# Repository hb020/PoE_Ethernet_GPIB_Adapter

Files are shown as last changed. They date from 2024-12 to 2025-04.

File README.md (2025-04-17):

# PoE Ethernet GPIB Adapter, with Prologix or VXI-11.2

## PoE-powered GPIB Adapter with Ethernet and USB-C Support

<a href="Img/adapter_connected.png" target="_blank">
    Adapter Assembled
</a>

The **PoE Ethernet GPIB Adapter** is designed to interface test equipment with GPIB / HPIB / IEEE-488 interfaces.

The primary goal of this project is to provide an easy solution to connect multiple GPIB-equipped instruments over Ethernet without excessive cabling. It can, at choice, use the Prologix protocol or support VXI-11.2 (VISA).

---

## Why?

The motivation behind this project comes from the challenges of using several generations of instruments with GPIB interfaces. In theory, only one GPIB master is needed, and up to 20+ instruments can be connected in any order using suitable GPIB cabling. However, there are drawbacks:

- Instruments must be fully compliant with the IEEE-488 standard. Many older instruments, predating the standard, do not comply. The main issue is that the bus does not go Hi-Z when off, requiring certain instruments to be powered on even if you're only using another device.
- GPIB cabling is bulky and expensive. While used options can sometimes be found, the overall cost remains high.

At work, this has been solved elegantly using commercial Ethernet adapters, each assigned an address and connected directly to the instrument. However, these adapters are priced around $500 USD—far from hobbyist-friendly. My initial solution was to buy one adapter and rely on daisy-chaining, but as my instrument collection grew to 20 devices requiring GPIB, this approach was no longer practical. Hence, the **PoE Ethernet GPIB Adapter** was born.

---

## Design Criteria

1. Lower cost: Total BOM should be less than 50 USD.
2. Support Power over Ethernet (PoE) to minimize cable clutter.
3. Include USB-C power as an alternative if PoE is unavailable.
4. Enable GPIB communication over both Ethernet and USB-C interfaces.
5. Use the same communication protocol as existing commercial units.
6. Minimize radiated and conducted noise to avoid interference in test environments.
7. Include a simple, easy-to-print 3D-printed enclosure to keep costs low.

---

## Results

All design goals have been met[^2]. The current unit price is approximately $45 USD when ordering parts for 20 units. Prices increase for smaller batch sizes.

[^2]: GPIB commands over USB-C is Work In Progress.

In my home lab, I assign each device a static IP address based on its MAC address and run a local DNS server to provide easy-to-remember domain names, making the adapter simple and intuitive to use.

Project's documentation:

- [Design Documentation](docs/dn.md)
- [Design Test Documentation](docs/dt.md)

---

## VXI-11 or Prologix

This code can produce either a VXI-11.2 device, or a Prologix device (the ROM is not big enough for both at the same time, although the code is compatible with cohabitation). Switching between VXI-11 and Prologix is done at compile time. If compiler option `-DINTERFACE_PROLOGIX` is used, the firmware produced is for Prologix.

VXI-11.2 allows discovery over the network, and uses the following VISA connection strings:

- Controller[^1]: `TCPIP::{IP address}::INSTR` (unless you have set the default instrument address to something else than 0)
- Instruments: `TCPIP::{IP address}::gpib,N::INSTR` or `TCPIP::{IP address}::instN::INSTR`, where `N` is their address on the GPIB bus (1..30)

Example: `TCPIP::192.168.7.105::gpib,2::INSTR` for instrument with GPIB address 2 on the gateway having IP address 192.168.7.105.

[^1]: controller, gateway, adapter: different names for the same.

### VXI-11.2 compatibility

With the limited resources, this device is meant to work with the most common tools, like for example pyVisa. It is not a full implementation, and lacks the following advanced features:

- secondary instrument addresses
- async VXI-11 operations
- instrument locking via VXI-11
- VXI-11 interrupts
- the VXI-11 abort channel

It is discoverable via UDP, but there is no publication via mDNS (yet).

---

## The number of instruments you can connect

The GPIB bus protocol itself allows up to 30 instruments. This does not mean you can connect 30 instruments to the gateway, as the gateway device has its electrical limits, depending on the length of the cables and instruments themselves. And also the software has its limits.

The Prologix service will accept as many instruments as the gateway hardware can drive reliably.

The VXI-11 service is easier to integrate with many tools, but it consumes more resources on the gateway. The Ethernet chip can only maintain a limited number of network sockets, and each instrument requires a separate socket with VXI-11. Prologix uses only 1 socket, no matter the number of instruments. This means that regardless of the limitations of the hardware, there is a limit to the number of instruments you can connect to via VXI-11 compatible client software:

- up to 4 instruments: no restriction
- 5 instruments: only if you do not use the web server
- 6 instruments: only if you disable the web server (use the compile option `-DDISABLE_WEB_SERVER`)
- 7 or more: not possible via VXI-11

This does not mean that you cannot physically connect more instruments to the gateway, it just means that you cannot connect to more of them, via your client software, at the same time.

Also, be aware that the GPIB bus is a shared bus. Do not try to control instruments on the bus from different software clients at the same time. VXI-11 is somewhat more forgiving in this matter, but the prologix service simply doesn't allow multiple connections.

---

## The User Interface of the device

There are 3 parts:

- the **LED**. It indicates different states: blue for waiting for DHCP, red for error in network or DHCP, green flashing for idle, green/blue flashing for busy
- the **Web Server** (on port 80): it shows some help texts and the number of connected clients. It is not interactive.
- the **serial console** (via USB): This console shows startup information, ports used, and has a small menu. 

### The serial menu

This menu is rather basic. Be aware that it requires 'enter' for each command.

It has the following options:

- Setting of IP address. By default, the device starts with DHCP. You can however force a fixed IP address.
- Setting of the default instrument address (only with VXI-11, as Prologix has its own command for that). The default is 0, meaning: the gateway itself. If you only have 1 instrument connected, or want to designate a "preferred" instrument, you can set it to the address of any instrument on the bus. That way, the gateway becomes transparent, and you can use the default (and the discoverable) VISA connection string to address that instrument.

---

## Project files

Latest version is avaiable under [Releases](https://github.com/Kofen/PoE_Ethernet_GPIB_Adapter/releases)

And all the source code for all the parts should be in their respective folders in the repro. If anything is missing, let me know!

## How to compile

The easiest is for compilation with PlatformIO, from the [SW](/SW) directory.

## License

This project is licensed under the GPL V3. See the [LICENSE](LICENSE) file for details.

## Acknowledgements

- A huge thanks to the [AR488 project](https://github.com/Twilight-Logic/AR488), run by [Twilight-Logic](https://github.com/Twilight-Logic) and its community contributors. The current software is a fork of AR488. For more information about this, see [here](SW/README.md).
- The VXI-11 driver is partially inherited from [espBode](https://github.com/awakephd/espBode), and went through various evolutions before arriving here.

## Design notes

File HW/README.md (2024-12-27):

# PoE Ethernet GPIB Adapter - Hardware Files

## Overview

This folder contains the necessary hardware files for the PoE Ethernet GPIB Adapter project.

- **Schematics:** The schematic files can be found [here](https://github.com/Kofen/PoE_Ethernet_GPIB_Adapter/blob/main/HW/Schematic_PDF/PoE_Ethernet_GPIB_Adapter.pdf).
- **Output Files:** The output files, including Gerber files and assembly information, are located [here](https://github.com/Kofen/PoE_Ethernet_GPIB_Adapter/tree/main/HW/PoE_Ethernet_GPIB_Adapter_PCBA_MFG_Files).
- **Releases:** Precompiled hardware files for different versions are available under [Releases](https://github.com/Kofen/PoE_Ethernet_GPIB_Adapter/releases).

**Important note:** PCB thickness should be 1.6mm, 1 oz / 35 um copper thickness on all layers!

---

Ensure to verify compatibility with your PCB manufacturing service before using the files.

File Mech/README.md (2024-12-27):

# PoE Ethernet GPIB Adapter

In the Freecad folder you will find the project files and an output folder with STL files. 

To make the case and assemble: 

- 2 x M3 x 10mm T10 Torx Countersunk Screws (ISO 14581) 
- 12 Meter (40 gram) of 3d filament of your choice. 
- Optional: 2x M3.5 x 70mm Countersunk Screws to fasten the adapter to the instrument. 

***NOTE*** If you want to use screws to fasten the adapter to the instrument, you need to drill out the holes in the centronic connector.

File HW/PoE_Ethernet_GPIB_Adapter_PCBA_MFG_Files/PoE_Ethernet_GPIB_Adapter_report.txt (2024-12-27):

PCB statistics report
=====================
- Date: Friday, December 27, 2024 at 07:41:28 AM
- Project: PoE_Ethernet_GPIB_Adapter
- Board name: PoE_Ethernet_GPIB_Adapter

Board
-----
- Width: 60.0000 mm
- Height: 55.0000 mm
- Area: 3300.0000 mm²

Pads
----
- Through hole: 60
- SMD: 557
- Connector: 0
- NPTH: 4

Vias
----
- Through vias: 741
- Blind/buried: 0
- Micro vias: 0

Components
----------

| | Front Side | Back Side | Total |
|---|---|---|---|
|THT: | 4 | 0 | 4 |
|SMD: | 135 | 28 | 163 |
|Unspecified:  | 30 | 1 | 31 |
|Total: | 169 | 29 | 198 |

Drill holes
-----------

| Count | Shape | X Size | Y Size | Plated | Via/Pad | Start Layer | Stop Layer |
|---|---|---|---|---|---|---|---|
| 741 | Round | 0.3000 mm | 0.3000 mm | PTH | Via | F.Cu | B.Cu |
| 26 | Round | 1.0000 mm | 1.0000 mm | PTH | Pad | F.Cu | B.Cu |
| 10 | Round | 0.6500 mm | 0.6500 mm | PTH | Pad | F.Cu | B.Cu |
| 10 | Round | 0.8900 mm | 0.8900 mm | PTH | Pad | F.Cu | B.Cu |
| 4 | Round | 1.0200 mm | 1.0200 mm | PTH | Pad | F.Cu | B.Cu |
| 2 | Round | 0.6500 mm | 0.6500 mm | NPTH | Pad | F.Cu | B.Cu |
| 2 |  Slot | 0.6000 mm | 1.7000 mm | PTH | Pad | F.Cu | B.Cu |
| 2 |  Slot | 0.6000 mm | 1.4000 mm | PTH | Pad | F.Cu | B.Cu |
| 2 | Round | 3.2000 mm | 3.2000 mm | NPTH | Pad | F.Cu | B.Cu |
| 2 | Round | 1.7000 mm | 1.7000 mm | PTH | Pad | F.Cu | B.Cu |
| 2 | Round | 1.3000 mm | 1.3000 mm | PTH | Pad | F.Cu | B.Cu |
| 2 | Round | 3.0000 mm | 3.0000 mm | PTH | Pad | F.Cu | B.Cu |

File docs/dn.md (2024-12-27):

# PoE Ethernet GPIB Adapter

## Design Notes

<a href="../Img/adapter_open.png" target="_blank">
    Adapter Assembled
</a>

---

## Hardware

While there are a few open-source GPIB controller projects, most of them rely on USB, Raspberry Pi, or WiFi/Bluetooth connectivity. These solutions do not meet my requirements. Using over 10 adapters with USB would result in a serial port management nightmare and require a service running on a local computer to forward all ports over the network for access from any computer. 

WiFi could resolve this but would introduce multiple devices in close proximity to sensitive test setups, which I find suboptimal. One PoE-powered GPIB project based on the RP2040 was mentioned on the EEVblog forum but was never published and seemed to have stalled. Therefore, I designed my own adapter while ensuring compatibility with one of the largest open-source adapters, the AR488.

Based on these requirements, the design was divided into the following components:

- PoE Power Supply
- Microcontroller Interface
- Network Interface
- GPIB Interface
- USB Interface

---

### PoE Power Supply

Several PoE modules provide 5V output, simplifying integration. However, achieving low noise and a small form factor made off-the-shelf solutions challenging without extensive pre-testing for EMI compliance. To address this, I divided the power supply into two parts: a PoE controller and a standalone isolated power supply.

- **PoE Controller:** I selected the Texas Instruments TPS2375-1 for its small size, affordability, built-in inrush limit, integrated MOSFET, and 802.3af compliance. The device was configured for Class 0 classification with standard input capacitance and transient protection.
- **Isolated 5V Power Supply:** The Texas Instruments LM5180 flyback controller was chosen for its integrated switch and primary-side regulation, offering a simple implementation. Although flyback converters are not ideal for low EMI, space constraints left no alternative without significantly increasing complexity. To minimize EMI:
  - A powerful common-mode filter was added on the input side.
  - Planar magnetics were used to reduce current loop size.
  - A cancellation winding was added to the transformer to mitigate common-mode voltage issues.
  - A strong chassis connection to the GPIB connector ensured a low-impedance return path for common-mode voltage.

---

### Microcontroller Interface

The Microchip ATMEGA4809 was chosen for its affordability and familiarity. While a more powerful 32-bit processor could have been considered, simplicity and the 8-bit architecture's alignment with the GPIB bus made this an appealing choice.

- **Unique MAC Address:** A Microchip I2C Unique ID EEPROM was included to provide a globally unique MAC address for the Ethernet interface. It can also store user-configurable settings.
- **Additional Features:** An RGB LED and reset switch were added for status indication and recovery in case of GPIB bus or adapter failure. 
- **Expansion:** A standard UPDI pinout for Atmel ICE programmers was implemented. Optional resistors connect I2C and UART2 to unused pins for potential future use with sensors or a WiFi UART interface (default resistors are not mounted).

---

### Network Interface

The Wiznet W5500 was selected as the network controller for its available drivers and compatibility with the AR488 project. To simplify the design:
- A magnetics RJ-45 magjack was used.
- Series termination was added to all applicable I/O lines for proper signal integrity and EMI reduction.
- A Texas Instruments SN74LV1T125DCK tri-state buffer was used for level translation (5V ↔ 3.3V ↔ 5V).
- A simple LDO provided the 3.3V supply, with a watchdog on the reset line.
- The crystal was selected per the datasheet to ensure Ethernet timing compliance.

---

### GPIB Interface

The GPIB interface directly connects to the microcontroller without driver ICs, using a resistor network on each I/O line and ESD protection to ground. This design:
- Does not handle constant overvoltage but protects against most ESD events.
- Requires the device to be powered on to avoid loading the GPIB bus, deviating slightly from full IEEE-488 compliance. This compromise reduces cost and space while meeting the 99% use case of the adapter being the controller.

---

### USB Interface

USB-to-UART controllers from reputable distributors proved expensive. Instead, I selected the CH340X USB-UART controller for its affordability and proven reliability in DIY and commercial projects. Notable features:
- A USB-C connector was used and configured for 500mA power.
- Protection includes a PTC fuse, ferrite bead, transient diode, and ESD filters on the data pins.
- The only drawback is sourcing the CH340X from Asian vendors, but reputable distributors like LCSC ensure reliability.

---

## Software

The current software is a work-in-progress, simplified fork of the AR488 project. This fork was chosen because it uses the Prologix syntax, compatible with my existing scripts. I also appreciate Prologix's simplicity: the Ethernet adapter operates as a basic socket. Commands without a `++` prefix are sent directly to the bus, while configuration is handled with `++` commands (e.g., `++addr` queries the address, and `++addr 22` sets the interface address to 22).

Initially, I intended to fully integrate the network stack and console interface into the AR488 project. However, given the project's complexity and my inability to test all functionalities, I opted to streamline this fork exclusively for this adapter. In the future, I plan to move away from Arduino to enhance performance.

Currently, the software includes a barebones implementation of the network stack and I2C support, with only DHCP enabled. Switching to USB-C UART instead of Ethernet requires modifying the configuration file and recompiling. Updates are planned to address these limitations.

Despite its barebones, hacky approach, the code has proven extremely reliable, running for months without issues. All my Prologix-based scripts work seamlessly.

Many software updates are expected in the future. Contributions to the software are highly welcome!

---

## Mechanics

A simple split housing was designed in FreeCAD for 3D printing. The snap-action case simplifies assembly and includes holes for securing the PCB and connector to the bottom half. There are also two holes on the back of the case for optional M3.5 screws to secure the adapter to the instrument.

The case design fitment heavily depends on the 3D printer and filament. I printed the cases on a Prusa MK3.5 using Bambu Labs PLA-CF filament, which provides a superb finish.

---

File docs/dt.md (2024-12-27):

# PoE Ethernet GPIB Adapter

## Design Tests

<a href="../Img/adapter_open.png" target="_blank">
    Adapter Assembled
</a>

---

## Scope of Testing

Each of the main blocks of the adapter was fully design-tested. The prototype (shown in the header image) was built in stages to make testing each module manageable as it was brought up.

The adapter was built and tested in this order:

- PoE Power Supply
- Microcontroller Interface
- USB Interface
- Network Interface
- GPIB Interface

**A note on details:** There are screenshots and CSV files of many measurements in this repository, but I decided against adding them to this document as they are not that interesting unless you are testing the design yourself. They're there for those who might care, in the `DT/Figs` folder. Naming should make sense for anyone familiar with the tests.

---

## Electrical Testing

### PoE Transformer

I started with a bare PCB to characterize the transformer using an HP4395A impedance analyzer in shunt-thru mode.

**Test Setup:**  
<a href="../Img/trafo_dt.png" target="_blank">
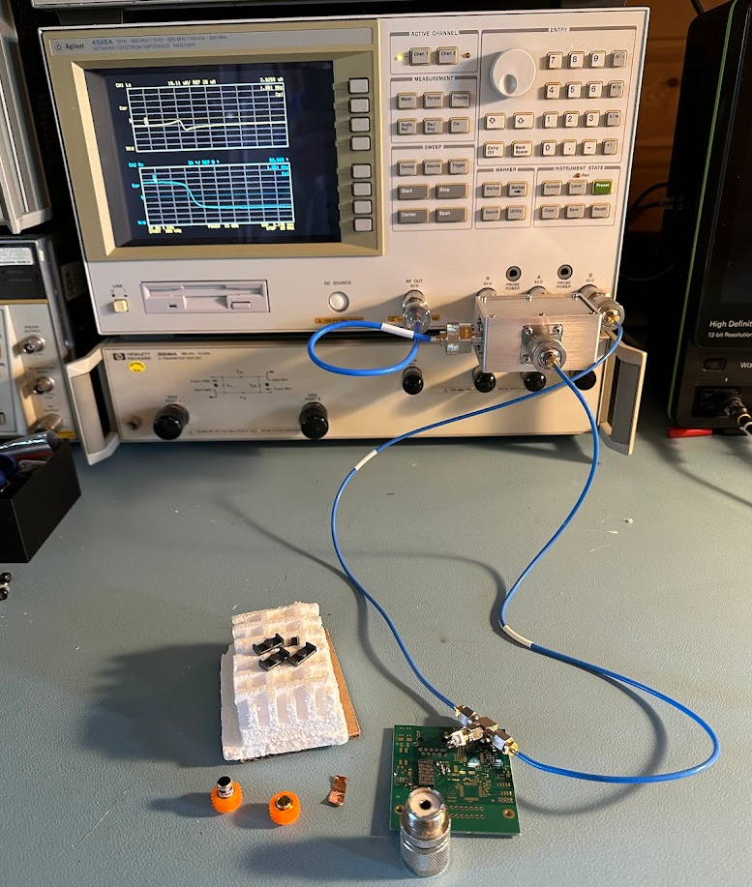
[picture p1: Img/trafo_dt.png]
Transformer Test Setup
    
</a>

Measurements were taken for primary/secondary inductance, leakage inductance, and interwinding capacitance. Everything was calibrated, and fixture parasitics were compensated.

Two tests were run with cores providing 50nH and 100nH Al values. Eventually, the 50nH core combination was chosen (reasons detailed later). Results for this configuration:

- Interwinding capacitance: **100 pF**
- Primary inductance: **18.2 µH**
- Secondary inductance: **2.29 µH**
- Primary leakage inductance: **395 nH**

These numbers lined up well with expectations.

### PoE Flyback 5V Power Supply

With the flyback controller populated, I connected it to a lab power supply with current limiting. It came to life at around 36.5V input, outputting 5.4V, which stabilized to 5.01–4.9V depending on the load.

**Test Setup:**  
<a href="../Img/test_poe.png" target="_blank">
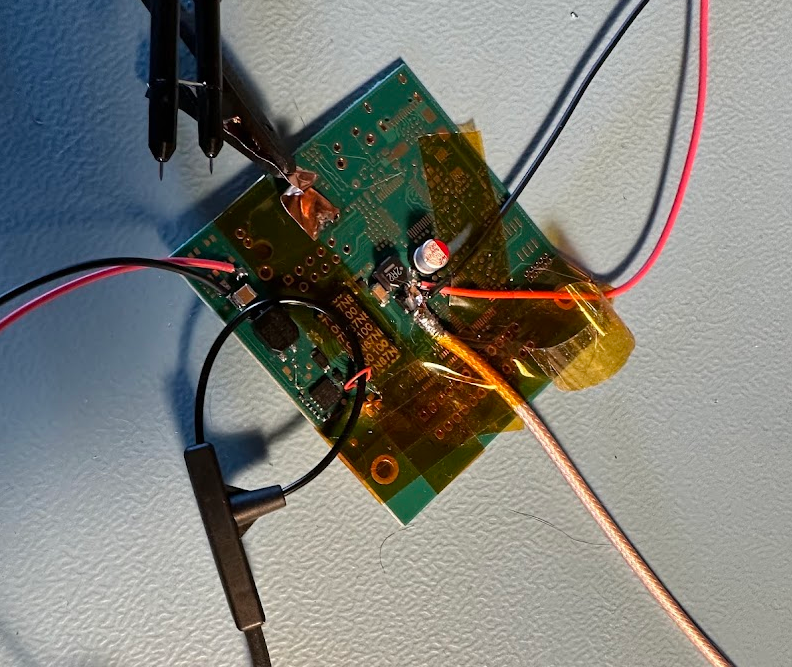
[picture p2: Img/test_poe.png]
Power Test Setup
    
</a>

**Troubleshooting and Adjustments:**  
Things went sideways at 48V, with instability in the power supply. The issue was traced to an undersized air gap in the transformer core. I took a calculated risk here, knowing the available cores and space constraints. To fix this, I replaced both of the core halfs with a gapped one, reducing the Al value to 50nH. This brought the primary inductance to ~15 µH. Not ideal, as it increased magnetizing current and reduced efficiency, but it was the best trade-off given the circumstances.

- Switching node voltage was clean, with the zener snubber doing its job well. No RC snubber was needed.
- High-frequency ringing across the rectifier diode required a 330pF + 33Ω snubber, which worked effectively.

**Efficiency Plot (Clickable):**  
<a href="../Img/eff.png" target="_blank">
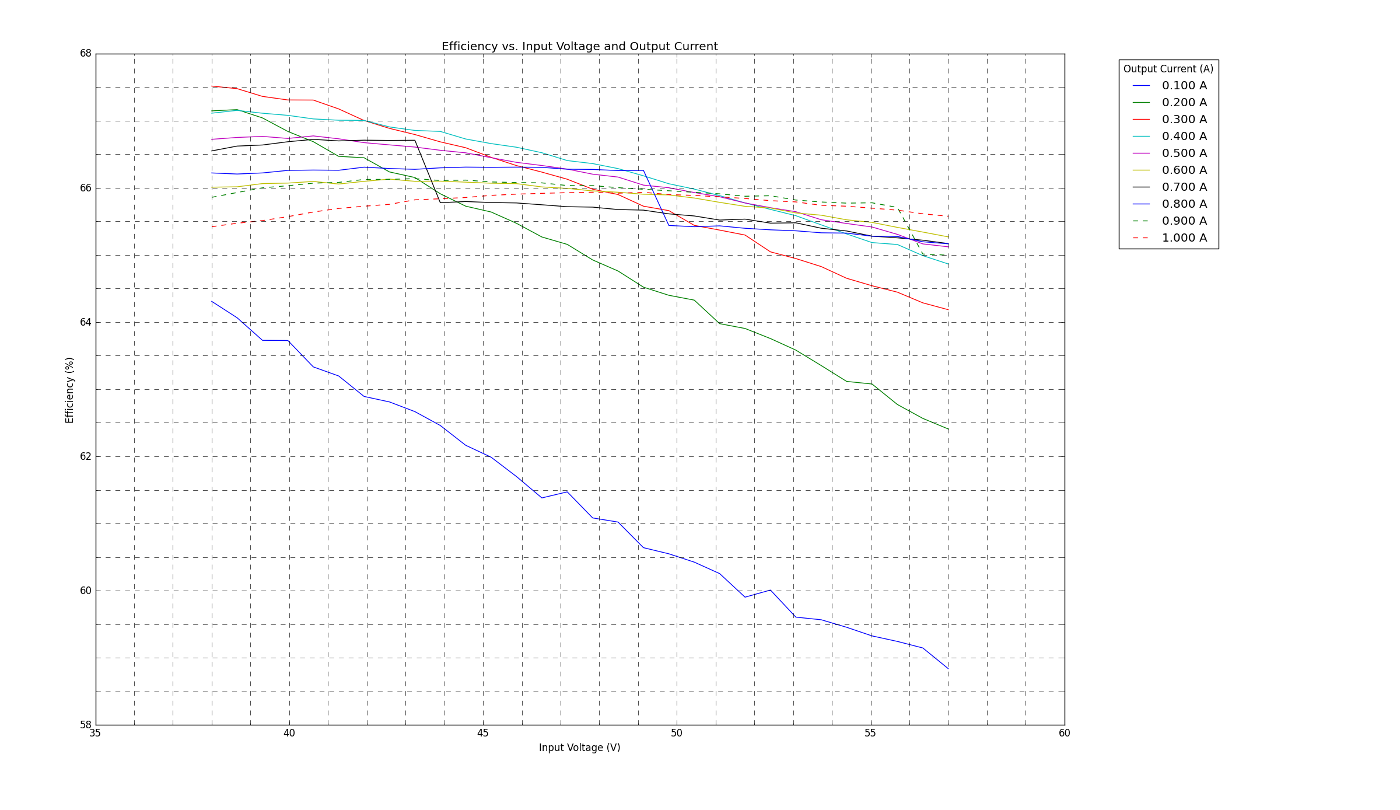
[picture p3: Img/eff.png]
Power Efficiency
    
</a>

As expected, efficiency isn't great. Lower loads and higher input voltages exacerbate losses due to increased magnetizing current and switching losses. However, thermals remain under control, with no concerning hotspots under typical operating conditions. It was decided to leave the core as is until full system tests are done.

Next, stability testing was done. Since the secondary voltage is regulated by the primary side, we do not have a normal feedback network. 
To test stability, two tests were done: step response and output impedance measurement. 

First, step response was done.

**Step Response Plot (Clickable):**  
<a href="../Img/Step_response_0p5A.png" target="_blank">
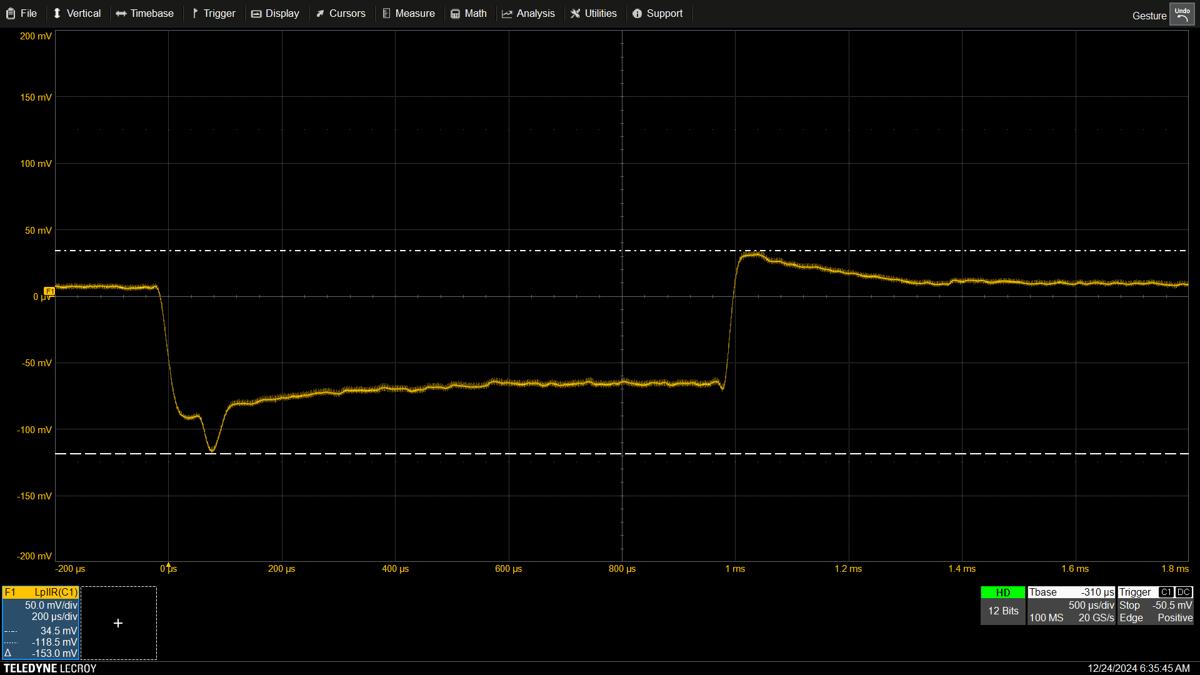
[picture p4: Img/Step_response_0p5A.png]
Step Response
    
</a>

The load was stepped from 0.1 A to 0.5 A. The result is a clean, fast step response with minimal ringing. The output voltage does drop slightly with increased load; this is due to the extra diode drop, not accounted for by the controller due to the regulating mechanism. 

Output ripple was measured to 15 mV peak to peak. Created mostly by the rest of the circuitry connected to the power supply.

As a final test, the output impedance was measured with all the parts placed on the PCB, with the adapter powered off and on. 

**5V PSU Impedance Plot (Clickable):**  
<a href="../Img/PSU_Impedance.png" target="_blank">
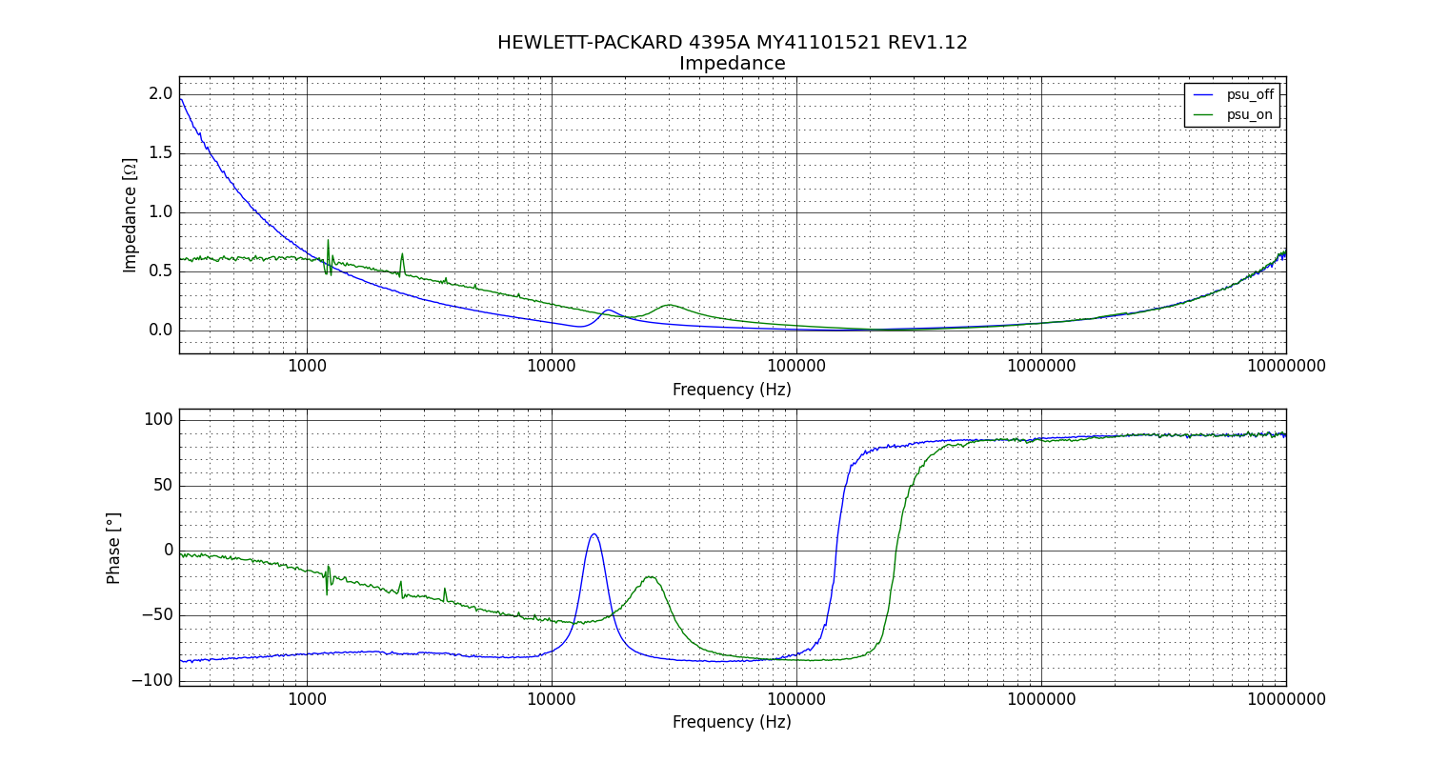
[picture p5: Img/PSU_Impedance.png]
PSU Impedance
    
</a>

With the power supply off, we see a resonance formed by the output LC filter, then we turn inductive around 150 kHz. 
With the power supply turned on, those points shift, and the Q of the LC resonance is lowered due to the parallel output impedance of the power supply. 
We also lower the general output impedance and see no added peaks or resonances from the power supply itself. 

The peak from the LC filter harmonizes well with the damped half-cycle ringing observed in the step response. 

Since we have no way to inject a test signal and do not see any form of resonance created by the switching controller on the impedance plot, we have no way of estimating the phase margin, but we can safely assume it is high due to the lack of any formed resonance. 
It is concluded that the power supply is sufficiently stable. 

### Microcontroller Interface

The microcontroller and its support circuitry were populated. Programming over JTAG worked perfectly, and all LEDs blinked as expected. No issues arose.

### USB Interface

With the CH340X USB interface populated, the adapter was recognized by my computer, and the serial console worked flawlessly. The reset line behaved correctly for USB programming. Measurements revealed no ringing or anomalies on the I/O lines.

### Network Interface

The Wiznet W5500's 3.3V power supply measured 4.2V due to an ordering mistake: the AZ1117-3.3 LDO I received had a different pinout. After replacing it, the supply output 3.303V, as expected.

Once the correct LDO was in place, the W5500 connected to the network, obtained an IP address, and passed signal integrity checks.

### GPIB Interface

The final test involved connecting the adapter to a GPIB-equipped instrument and querying `*IDN?`. It returned the expected instrument ID. The adapter handled multiple instruments and longer GPIB chains without issues, with signal levels and integrity well within acceptable ranges. I set up an automated test to stress the GPIB handling by sending a lot of data back and forth between numerous instruments without any issues. 

---

## EMC Compliance Testing

**Disclaimer:** This was done at home with DIY equipment. While I've characterized all my gear and even compared some of my equipment with professional gear, these results shouldn't be treated as commercial-grade compliance tests. The goal here was to ensure the adapter wasn't creating an EMI disaster in my own lab.

### Conducted Emissions

**Test Setup:**  
<a href="../Img/emc_cond.jpg" target="_blank">
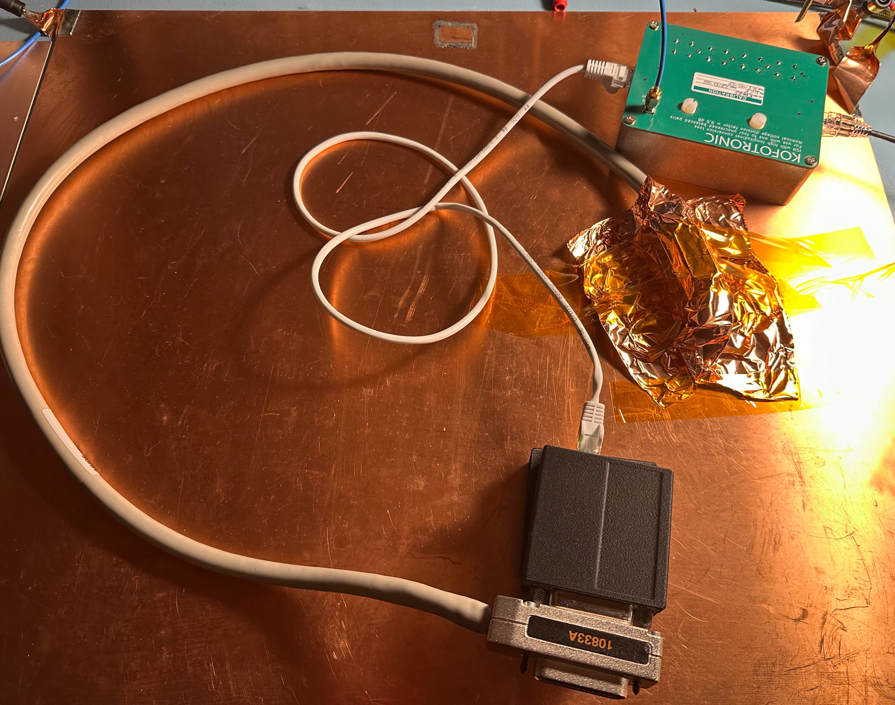
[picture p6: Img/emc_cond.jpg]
EMC Conducted Setup
    
</a>

This worst-case setup involved elevating the DUT 2.5 cm, using a cheap 1 Meter unshielded Ethernet cable, and grounding the GPIB connector via an additional GPIB cable.

**Results (Clickable):**  
<a href="../Img/Conducted.png" target="_blank">
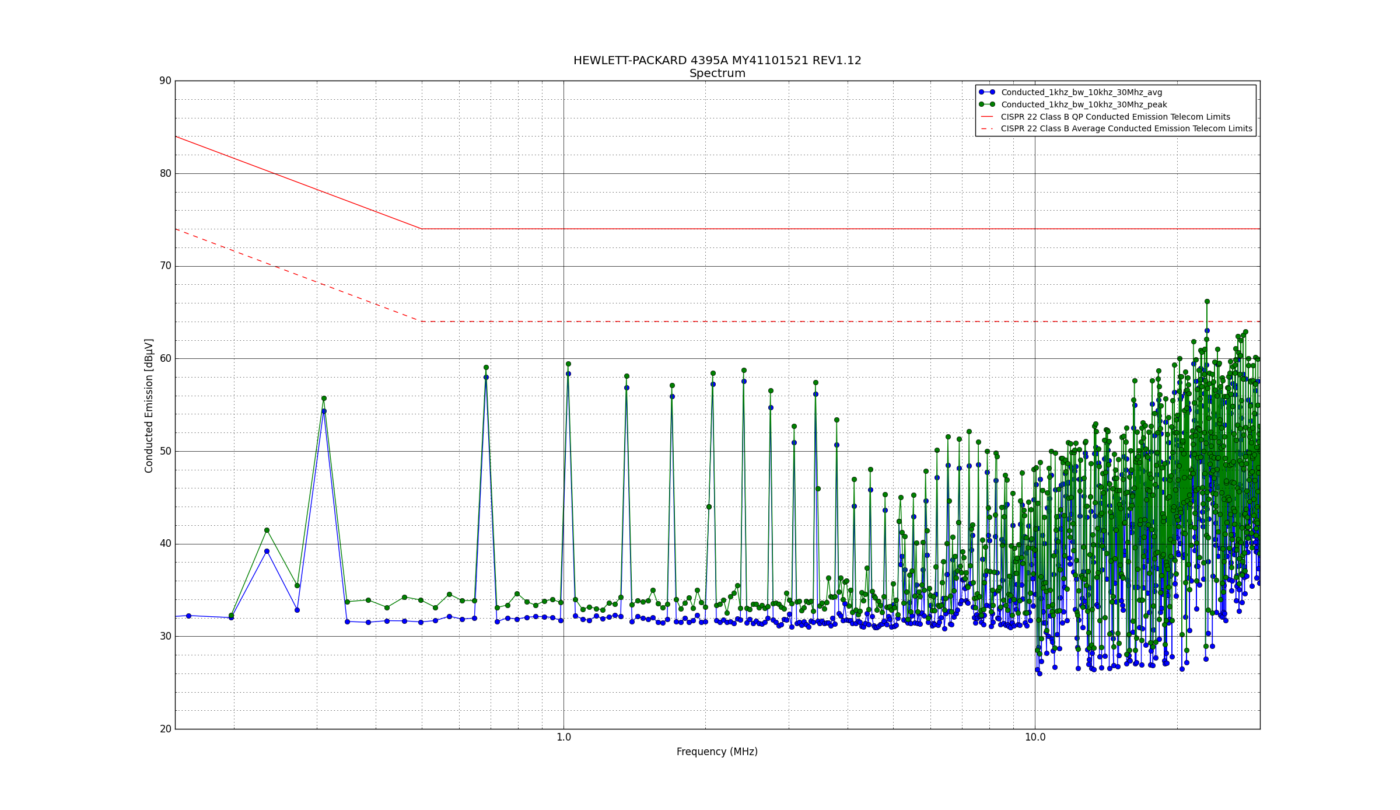
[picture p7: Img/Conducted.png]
Conducted Emissions
    
</a>

The adapter met CISPR-22 Class B limits. Margins were tight at higher frequencies, but no further tweaks were deemed necessary.

### Radiated Emissions

**Test Setup:**  
<a href="../Img/tem.png" target="_blank">
    EMC Radiated Setup
</a>

A small TEM cell was used instead of a proper far-field setup, so take these results with a grain of salt.
I have calculated the equivalent 3-meter far field, but I am still unsure how well it translates. Uncorrected as well as corrected data is therefore shown below.

**Uncorrected Results (Clickable):**  
<a href="../Img/Radiated_emissions_peak.png" target="_blank">
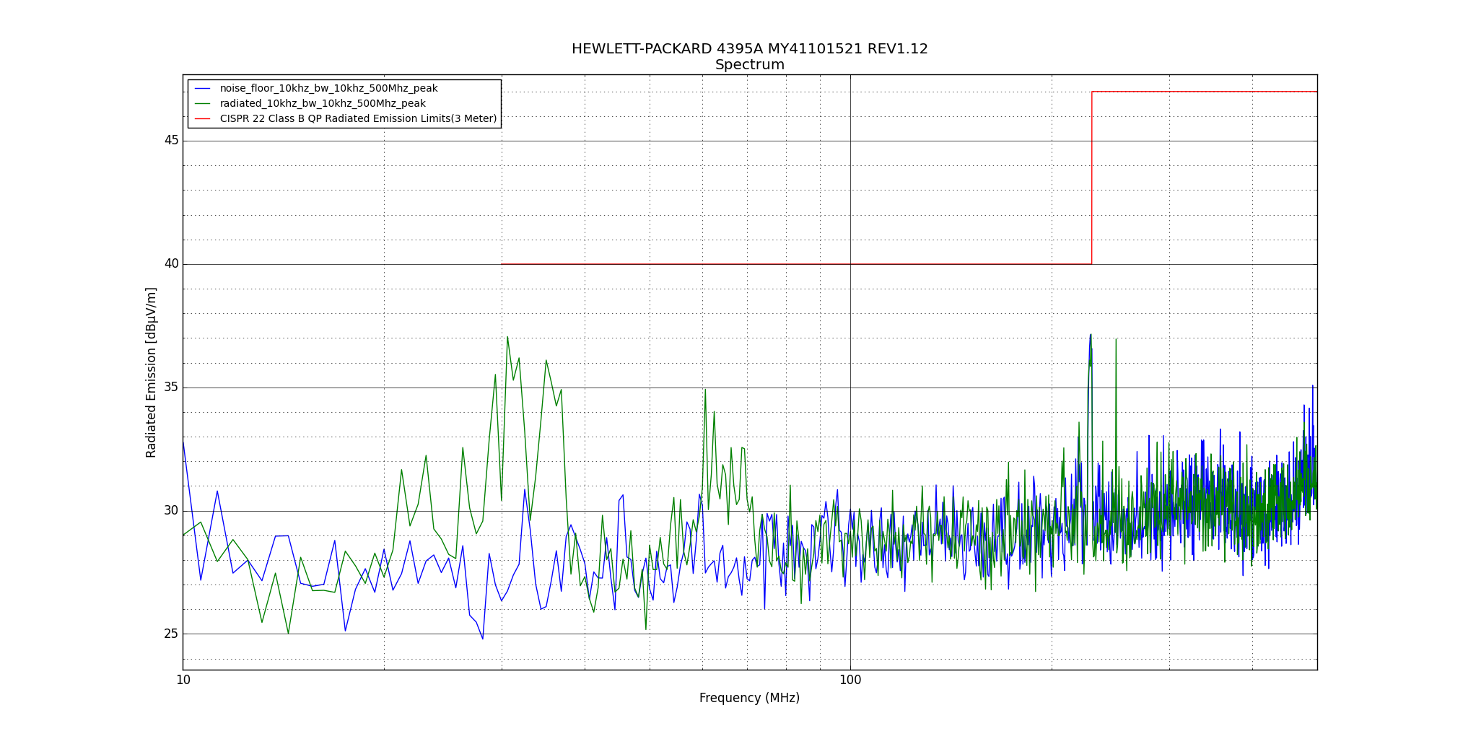
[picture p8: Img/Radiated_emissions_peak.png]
Radiated Emissions
    
</a>

**Corrected Results (Clickable):**  
<a href="../Img/Radiated_emissions_peak_corrected.png" target="_blank">
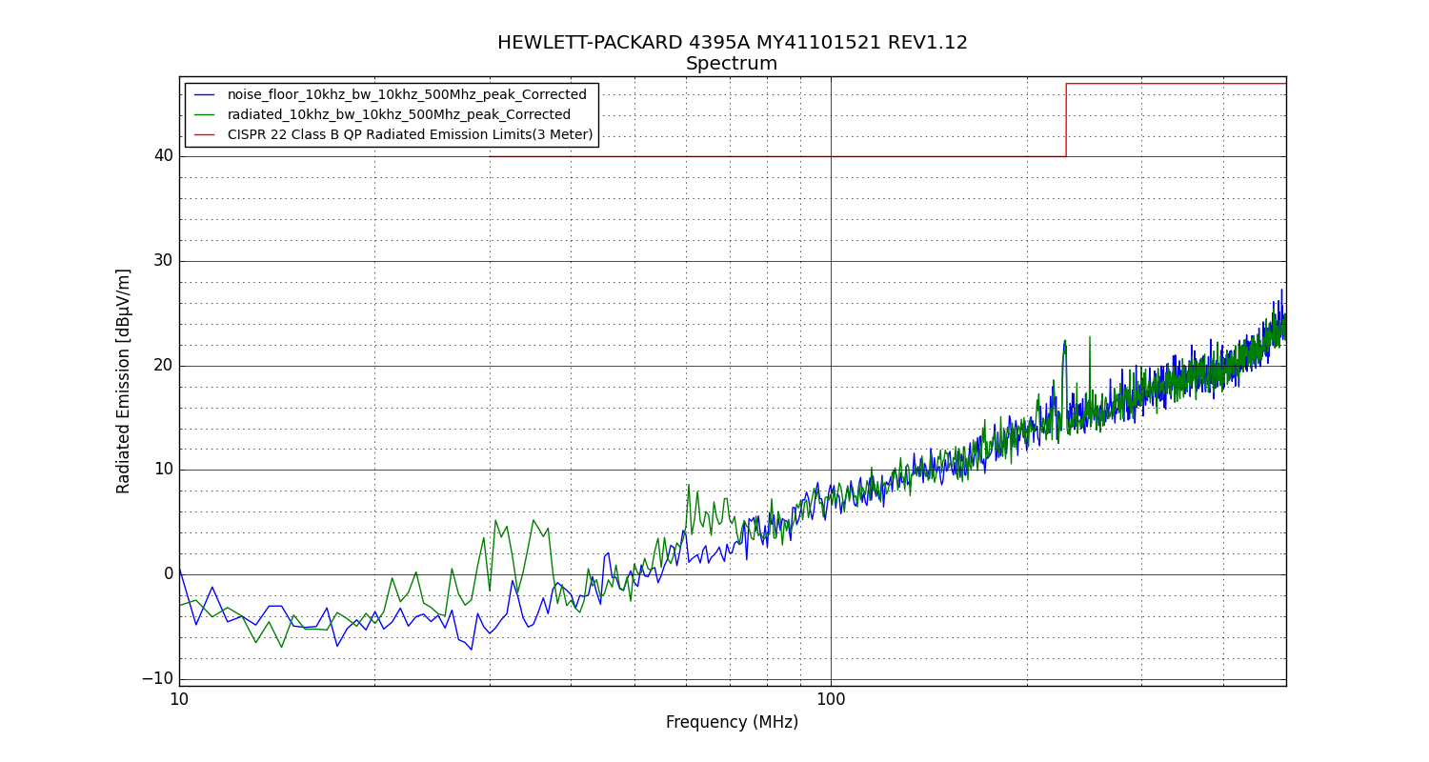
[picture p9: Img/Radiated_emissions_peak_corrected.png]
Corrected Radiated Emissions
    
</a>

The adapter showed minimal issues. Peaks around 250 MHz likely originate from the network interface.

---

## Thermal Testing

Thermal tests showed the adapter's housing raised internal temperatures by ~10°C. With the case opened, thermal imaging identified the 3.3V LDO and Ethernet interface as the hottest points (~23°C above ambient).

**Thermal Plot (Clickable):**  
<a href="../Img/Thermals.png" target="_blank">
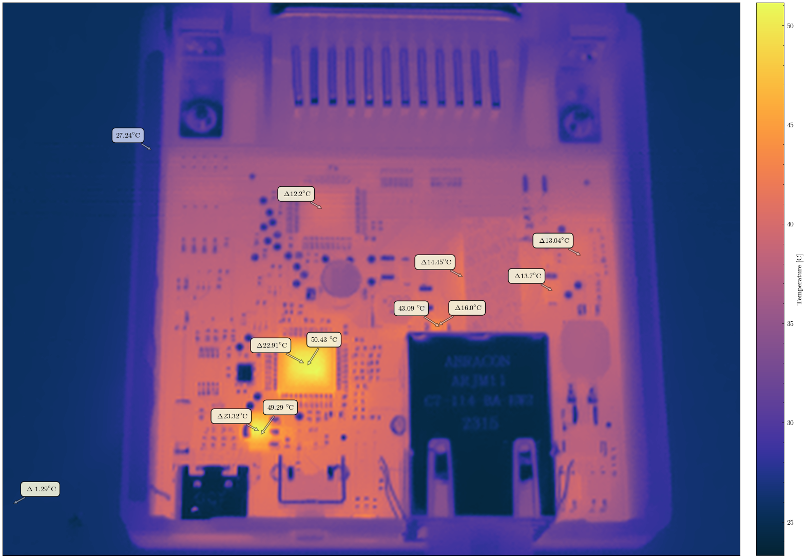
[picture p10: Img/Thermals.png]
Thermal Analysis
    
</a>

This suggests the adapter is safe for ambient temperatures up to ~50°C.

---

## Total power consumption

The total power consumption at 52v in was measured to 1.3 Watt. This is with network interface active, but GPIB bus idle.

## Conclusion

The device meets design goals despite a few compromises:

- The transformer core was adjusted to avoid re-sourcing or grinding cores.
- The LDO issue was fixed with a correct part replacement.

For the release version, I added optional I2C and UART2 connections to the JTAG header and improved copper pours around the Ethernet controller and LDO.

These changes aren't critical but should make future revisions easier.

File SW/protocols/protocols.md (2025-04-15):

# prologix vs RAW vs VXI-11.2 vs hislip

## Needs in number of network connections

..provided we need compatibility with 1 pyvisa program only.

Suppose N is the number of instruments to be represented:

* prologix: 1: TCP server
* RAW: N or N+1 (if you also want the instrument server): all TCP servers in 'auto' mode
* VXI-11.2: N+2 or N+3 (if you also want the instrument server): 1 UDP portmapper, 1 TCP portmapper and the rest RPC servers in non-'auto' mode.
* hislip: not investigated, requires a LOT

## prologix

not (yet) suppored by pyvisa

## RAW

Example of connection string:

TCPIP::192.168.1.105::[port number]::SOCKET

Requires 1 server, and 1 client socket per instrument. Multiple commands tend to be sent concatenated in 1 network packet, unless a question is sent.

## VXI-11.2

Example of connection string:

* TCPIP::192.168.1.105::gpib,5::INSTR   (gpib or hpib or gpibN or hpibN): VXI-11.2
* TCPIP::192.168.1.105::inst::INSTR     (instN): 'normal' vxi-11

gpib0 or inst0: default or only, hpibN or instN: others

Requires 3 servers, and 1 client socket per instrument:

* port mappers on UDP and TCP that point to the VXI-11 RPC server
* the VXI-11 RPC server. VXI-11 consists of 3 separate RPC programs with the numeric identifiers: 0x0607AF (DEVICE_CORE), 0x0607B0 (DEVICE_ASYNC) and 0x0607B1 (DEVICE_INTR).
* you may also add mDNS

For compatibility with basic pyvisa use, you only need DEVICE_CORE, but the guidelines say you should also support the others.

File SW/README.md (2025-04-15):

# PoE Ethernet GPIB Adapter Software

## Programming

In order to program the adapter you first need to flash the Optiboot bootloader via Jtag with an UPDI programmer(Atmel ICE, serial updi or similar).
After this is done, it can be programmed through the usb-c interface.

# AR488, what has changed and how to integrate a new version of AR488

The GPIB part of this program is "forked" from https://github.com/Twilight-Logic/AR488, from ver. 0.53.03, 08/04/2025. It was enhanced with ethernet support, VXI-11.2 and a couple of User Interface options.

Since a proper fork was not possible seen the amount of changes and the specifics of the hardware, this file documents how the integration of the AR488 code was performed. Hoping it will help future code updates.

The original README from AR488 is here: [README_AR488](README_AR488.md), as is the [original AR488 manual](AR488-manual.pdf). Only the part regarding the Prologix protocol would be of interest here.

The files starting with `AR488` were copied to `\SW\src` and modified:

## AR488.ino

This is/was the 'main' file. It received most changes:

* changed the setup section, as the structure was not compatible with cohabitation with other socket servers
* was lacking forward declarations, making it incompatible with 'standard' compilers.

The file was renamed to 'prologix_server.cpp'. The code sections that were modified, are marked as such, with explanation of what was changed.

## AR488_ComPorts.cpp and AR488_ComPorts.h

* DEVNULL externalised to become a dependency
* Added include to `EthernetStream.h`
* `startDataPort()` version added that points to a `EthernetStream`.
* `int maintainDataPort()` added
* `printBuf()` added

## AR488_Config.h

* Set `#define AR488_CUSTOM`, plus content of the 2 relevant sections

## AR488_Eeprom.cpp and AR488_Eeprom.h

no changes

## AR488_GPIBbus.cpp and AR488_GPIBbus.h

* Changed `void sendData(char *data, uint8_t dsize);` into `void sendData(const char *data, uint8_t dsize);`  (const)
* Added a couple of sections with `#ifdef AR488_GPIBconf_EXTEND`, in order to store the IP address in the config.

## AR488_Layouts.cpp and AR488_Layouts.h

Replaced the entire `CUSTOM PIN LAYOUT SECTION` in the .cpp file.

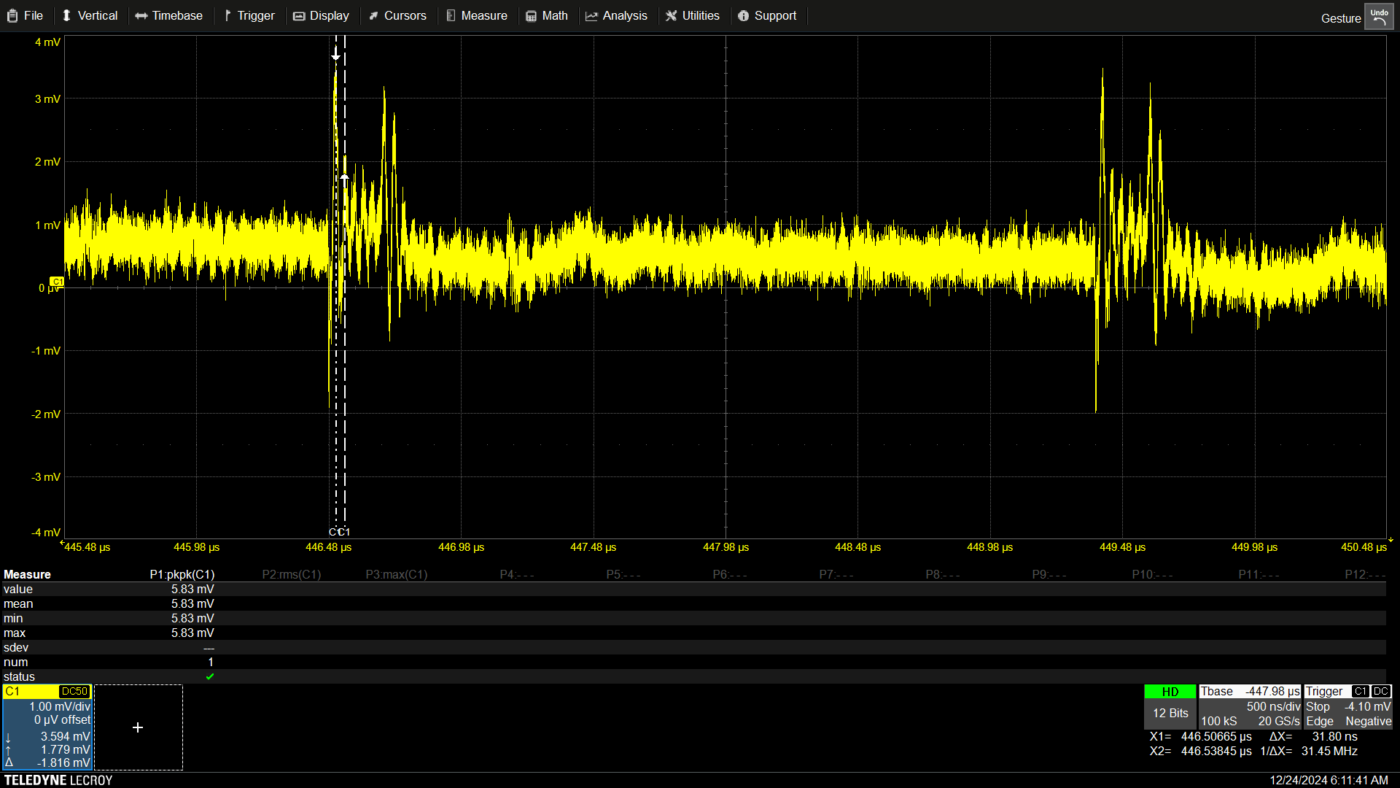
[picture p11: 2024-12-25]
HW/DT/Figs/ripple_30mhz.png

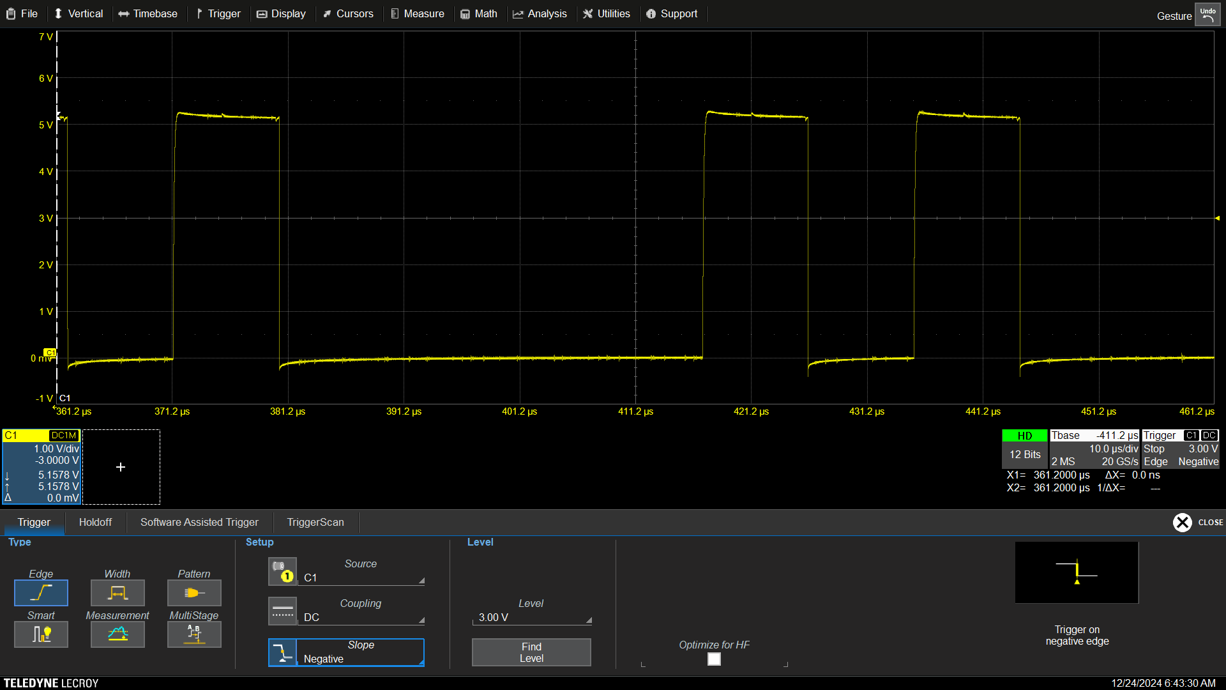
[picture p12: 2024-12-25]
HW/DT/Figs/SDA.png

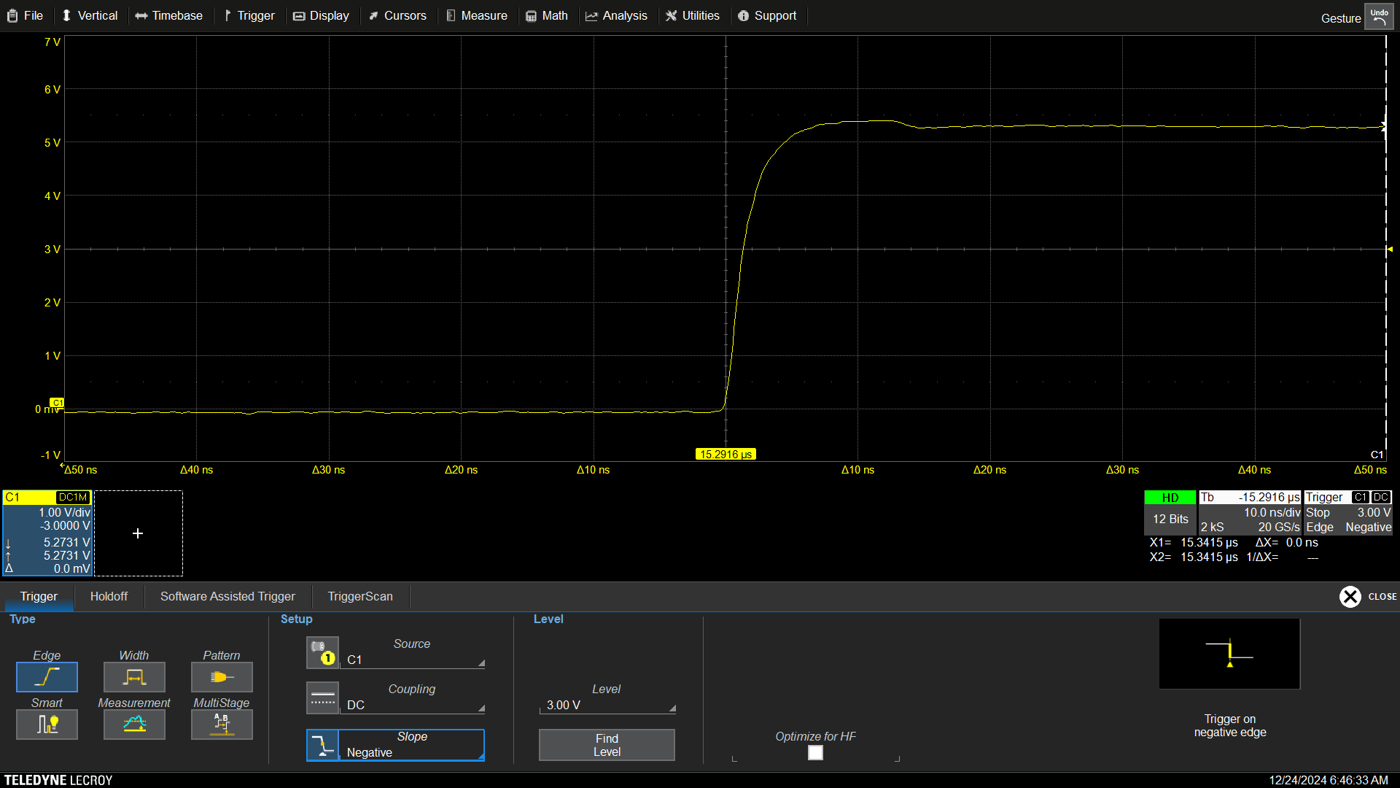
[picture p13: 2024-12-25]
HW/DT/Figs/MOSI_RISE.png

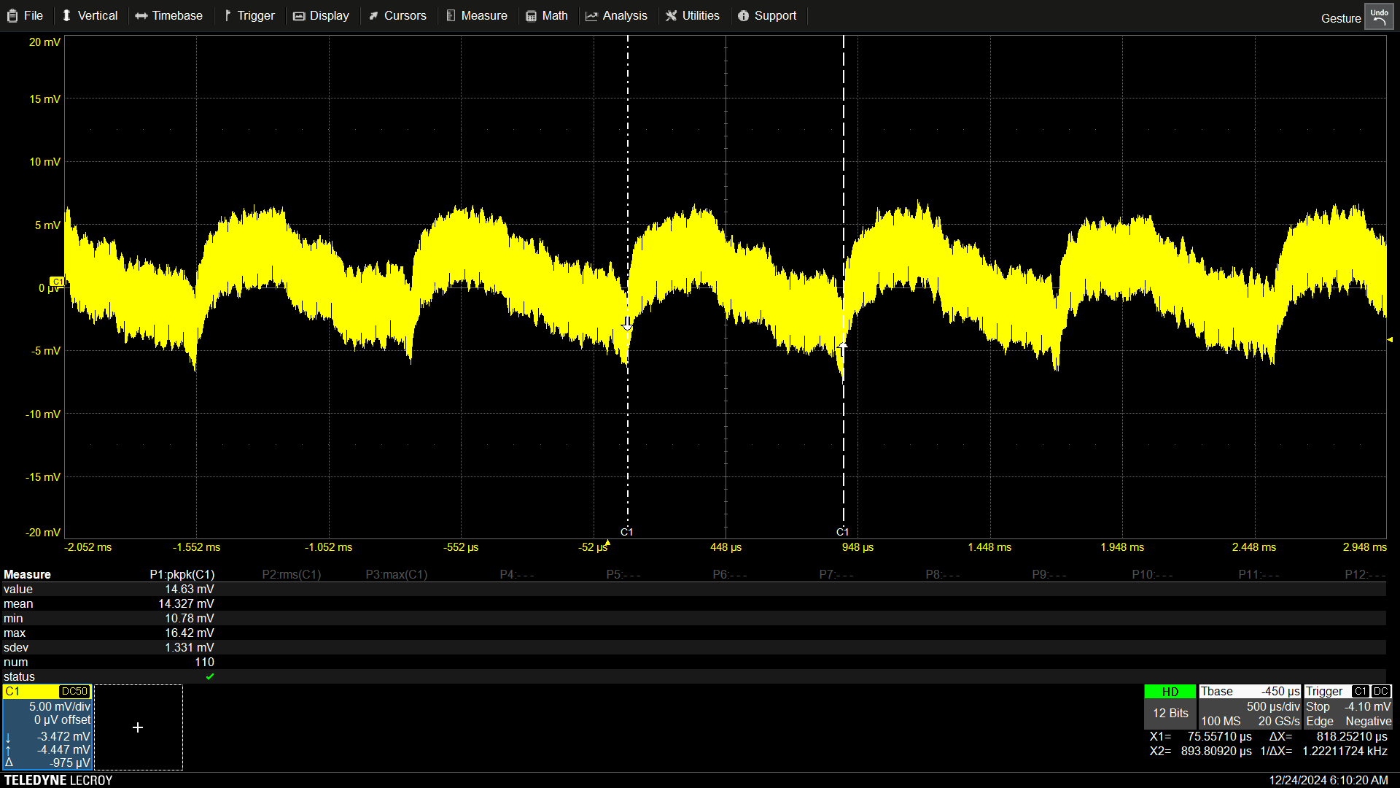
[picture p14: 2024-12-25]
HW/DT/Figs/ripple_lf.png

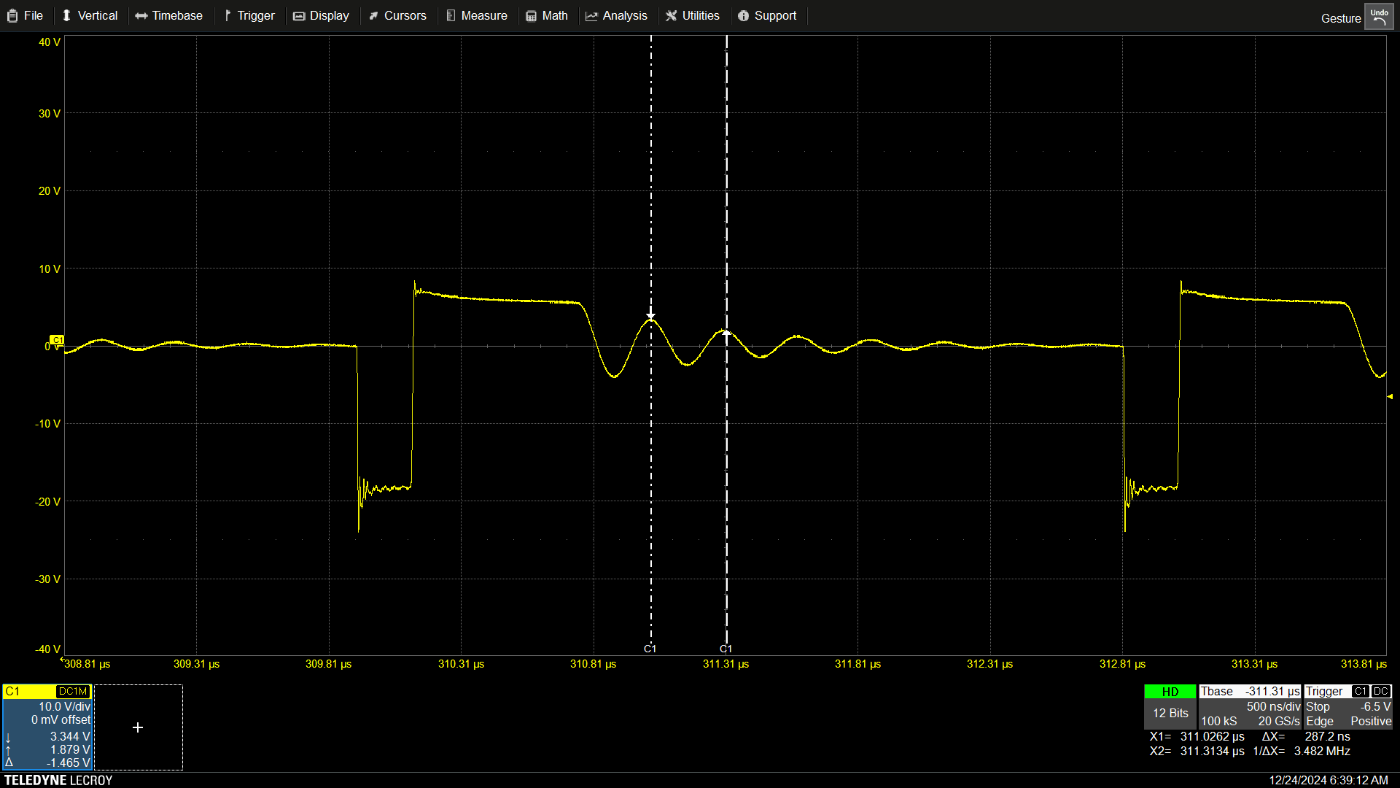
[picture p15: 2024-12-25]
HW/DT/Figs/DCM_secondary_ringing.png

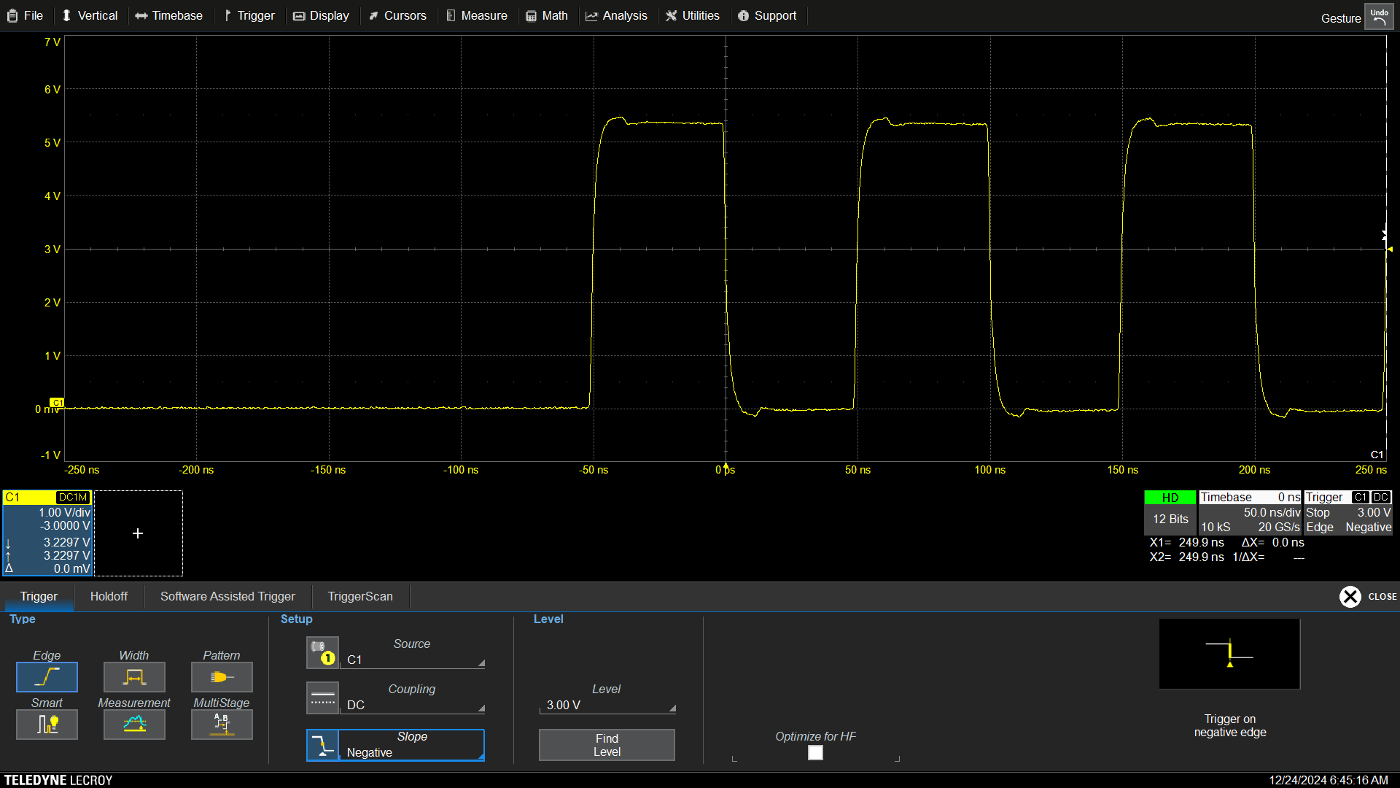
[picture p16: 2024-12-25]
HW/DT/Figs/SCK.png

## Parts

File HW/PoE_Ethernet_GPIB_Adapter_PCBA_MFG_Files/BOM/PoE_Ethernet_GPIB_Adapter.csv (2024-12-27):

null | Sourced | Placed | References | Value | Footprint | Manufacturer | Model | Quantity
1 |  |  | C4, C5, C6, C11, C12, C13, C14, C19, C20, C22, C23, C31, C32, C33, C34, C35, C36, C37, C38, C39, C40, C41 | 100n | C_0402_1005Metric | KEMET | C0402C104K4RACTU | 22
2 |  |  | C7, C8, C9, C10, C15, C16, C21, C24, C25, C26, C27, C28, C29, C30, C63, C64 | 10µ | C_0402_1005Metric | Murata | GRM155R60J106ME05D | 16
3 |  |  | C47, C48, C49, C50, C51, C52, C53, C54, C57 | 4.7n 1kV | C_0805_2012Metric | KEMET | C0805C472KDRACTU | 9
4 |  |  | C2, C3, C17, C18 | 18p | C_0402_1005Metric | YAGEO | CC0402GRNPO9BN180 | 4
5 |  |  | C43, C44, C45, C46 | 10µ 100v | C_1210_3225Metric | Murata | GRM32EC72A106ME05L | 4
6 |  |  | C1, C62 | 47n | C_0402_1005Metric | KEMET | C0402C473K4RACTU | 2
7 |  |  | C59, C60 | 100µ | C_1206_3216Metric | Samsung | CL31A107MQHNNWE | 2
8 |  |  | C42 | 100n 100v | C_0603_1608Metric | Samsung | CL10B104KC8NNNC | 1
9 |  |  | C55 | 22pF | C_0603_1608Metric | YAGEO | CC0603JRNPOYBN220 | 1
10 |  |  | C56 | 330pF | C_0603_1608Metric | YAGEO | CC0603JRNPOYBN331 | 1
11 |  |  | C58 | 470pF 1kV | C_0805_2012Metric | KEMET | C0805C471KDRACTU | 1
12 |  |  | C61 | 100µ 6.3v | CP_Elec_5x5.3 | Wurth Elektronik | 865080142007 | 1
13 |  |  | R23, R24, R25, R26, R27, R36, R37, R38, R39, R41, R42, R53, R54, R55, R56 | 49.9 | R_0402_1005Metric | Yageo | RC0402FR-0749R9L | 15
14 |  |  | R10, R11, R32, R33, R34, R35, R40 | 10 | R_0402_1005Metric | Yageo | RC0402FR-0710RL | 7
15 |  |  | R5, R7, R12, R17, R31 | 4.7k | R_0402_1005Metric | Yageo | RC0402FR-074K7L | 5
16 |  |  | R46, R47, R48, R49 | 1.5k | R_0603_1608Metric | Yageo | RC0603FR-131K5L | 4
17 |  |  | R3, R15, R16 | 27k | R_0402_1005Metric | Yageo | RC0402FR-0727KL | 3
18 |  |  | R18, R29, R30 | 220 | R_0402_1005Metric | Yageo | RC0402FR-07220RL | 3
19 |  |  | R6, R28 | 12.1k | R_0402_1005Metric | Yageo | RC0402FR-0712K1L | 2
20 |  |  | R13, R14 | 5.1k | R_0402_1005Metric | Yageo | RC0402FR-075K1L | 2
21 |  |  | R20, R21 | 1k | R_0402_1005Metric | Yageo | RC0402FR-071KL | 2
22 |  |  | R1 | 15k | R_0402_1005Metric | Yageo | RC0402FR-0715KL | 1
23 |  |  | R2 | 330k | R_0805_2012Metric | Yageo | RC0805FR-13330KL | 1
24 |  |  | R4 | 100k | R_0402_1005Metric | Yageo | RC0402FR-07100KL | 1
25 |  |  | R8 | 150k | R_0805_2012Metric | Yageo | RC0805FR-13150KL | 1
26 |  |  | R9 | 10k | R_0402_1005Metric | Yageo | RC0402FR-0710KL | 1
27 |  |  | R19 | 2.2k | R_0402_1005Metric | Yageo | RC0402FR-072K2L | 1
28 |  |  | R22 | 1M | R_0402_1005Metric | Yageo | RC0402FR-071ML | 1
29 |  |  | R43 | 24.9k | R_0402_1005Metric | Yageo | RC0402FR-0724K9L | 1
30 |  |  | R44 | 180k | R_0402_1005Metric | Yageo | RC0402FR-07180KL | 1
31 |  |  | R45 | 4.42k | R_0402_1005Metric | Yageo | RC0402FR-074K42L | 1
32 |  |  | R50 | 100 | R_0603_1608Metric | Yageo | RC0603FR-13100RL | 1
33 |  |  | R51 | 33 | R_0603_1608Metric | Yageo | RC0603FR-1333RL | 1
34 |  |  | R52 | 0 | R_0603_1608Metric | Yageo | RC0603FR-130RL | 1
35 |  |  | L1 | 50475AC | muRata_5000A | MuRata | 50475AC | 1
36 |  |  | L2 | 2.2µ | L_Taiyo-Yuden_NR-50xx | TAIYO YUDEN | NRS5030T2R2NMGJ | 1
37 |  |  | D1, D2 | DT1240A-08LP3810 | UDFN-9_1.0x3.8mm_P0.5mm | Diodes Incorporated | DT1240A-08LP3810-7 | 2
38 |  |  | D4, D10 | 1N4448WS | D_SOD-323 | Diotec Semiconductor | 1N4448WS | 2
39 |  |  | D6, D7 | MYS80 | Diode_Bridge_Diotec_MicroDil_3.0x3.0x1.8mm | Diotec Semiconductor | MYS80 | 2
40 |  |  | D3 | P4SMAJ5.0A | D_SMA | Diotec Semiconductor | P4SMAJ5.0A | 1
41 |  |  | D5 | LED_ABGR | LED_RGB_Everlight_EASV3015RGBA0_Horizontal | Wurth | 155124M173200 | 1
42 |  |  | D8 | P4SMAJ58CA | D_SMA | Diotec Semiconductor | P4SMAJ58CA | 1
43 |  |  | D9 | DFLZ20-7 20V | D_PowerDI-123 | Diodes Incorporated | DFLZ20-7 | 1
44 |  |  | D11 | CUHS20S40 | D_TUMD2 | Toshiba | CUHS20S40,H3F | 1
45 |  |  | D12 | 5.6v | D_SOD-123F | Diotec Semiconductor | BZT52C5V6 | 1
46 |  |  | U7, U8 | SN74LV1T125DCK | SOT-353_SC-70-5 | Texas Instruments, Texas Instruments | SN74LV1T125DCKRG4 | 2
47 |  |  | U1 | LM5180 | WSON-8-1EP_4x4mm_P0.8mm_EP1.98x3mm | Texas | LM5180NGUR | 1
48 |  |  | U2 | ATmega4809-A | TQFP-48_7x7mm_P0.5mm | Microchip | ATMEGA4809-AU | 1
49 |  |  | U3 | W5500 | LQFP-48_7x7mm_P0.5mm | WIZnet | W5500 | 1
50 |  |  | U4 | 24AA256UID | SOIC-8_3.9x4.9mm_P1.27mm | Microchip | 24AA256UID-I/SN | 1
51 |  |  | U5 | USBLC6-2P6 | SOT-666 | STMicroelectronics | USBLC6-2P6 | 1
52 |  |  | U6 | CH340X | MSOP-10_3x3mm_P0.5mm | Jiangsu Qin Heng | CH340X | 1
53 |  |  | U9 | APX811-31UG-7 | SOT-143 | Diodes Incorporated | APX811-31UG-7 | 1
54 |  |  | U10 | AZ1117-3.3_SOT89 | SOT-89-3 | Diodes Incorporated | AZ1117CR2-3.3TRG1 | 1
55 |  |  | U11 | TPS2375-1 | TSSOP-8_4.4x3mm_P0.65mm | Texas Instruments | TPS2375PWR-1 | 1
56 |  |  | Y1 | 25Mhz | Crystal_SMD_2520-4Pin_2.5x2.0mm | ECS | ECS-250-18-36B2-CTY-TR | 1
57 |  |  | F1 | 0.75A | Fuse_1812_4532Metric | Eaton | PTS181213V075 | 1
58 |  |  | SW1 | Reset | SW_Tactile_SKHH_Angled | Alps Alpine | SKHHLUA010 | 1
59 |  |  | RN1, RN2 | 10 | R_Array_Convex_8x0602 | YAGEO | YC248-JR-0710RL | 2
60 |  |  | FB1 | 220R | L_0603_1608Metric | Bourns | MU1608-221Y | 1
61 |  |  | FB2 | 1k | L_0805_2012Metric | Murata Electronics | BLM21PG102BH1D | 1
62 |  |  | Q1 | PMV30XPEAR | SOT-23 | Nexperia | PMV30XPEAR | 1
63 |  |  | Q2 | BC857BS | SOT-363_SC-70-6 | Nexperia | BC857BS-QX | 1
64 |  |  | T1 | ~ | ER14_planar_4_to_1_48v_in_5v_out_5w | TDK | B65513J0100A087 | 2
65 |  |  | J1 | ARJM11C7-114-BA-EW2 | RJ45_ARJM11C7-114-BA-EW2 | ABRACON | ARJM11C7-114-BA-EW2 | 1
66 |  |  | J2 | 112-024-113R001 | 112-024-113R001 | NorComp | 112-024-113R001 | 1
67 |  |  | J3 | USB4105-GF-A | USB_C_Receptacle_GCT_USB4105-xx-A_16P_TopMnt_Horizontal | GCT | USB4105-GF-A | 1
68 |  |  | J4 | UPDI Debug Connector | PinHeader_2x05_P1.27mm_Vertical | Amphenol | 20021111-00010T1LF | 1

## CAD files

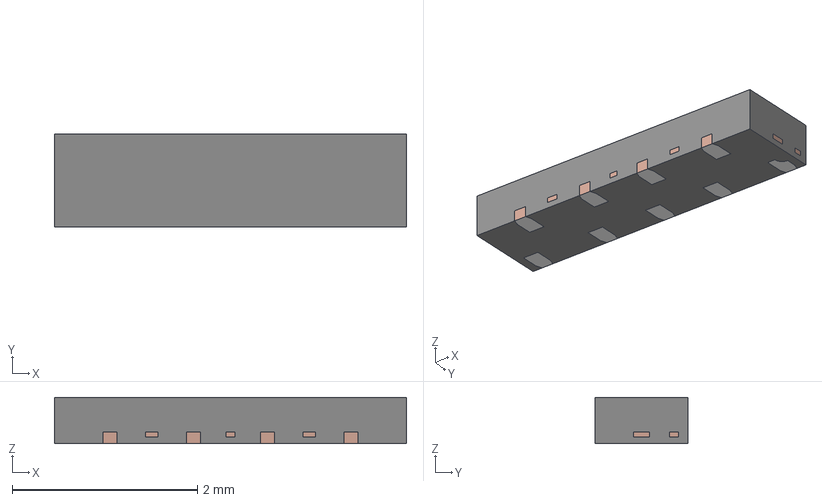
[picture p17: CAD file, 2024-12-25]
HW/3d_models/DT1240A-08LP3810-7.stp
3.80 x 1.00 x 0.5 mm
CPD
LDF

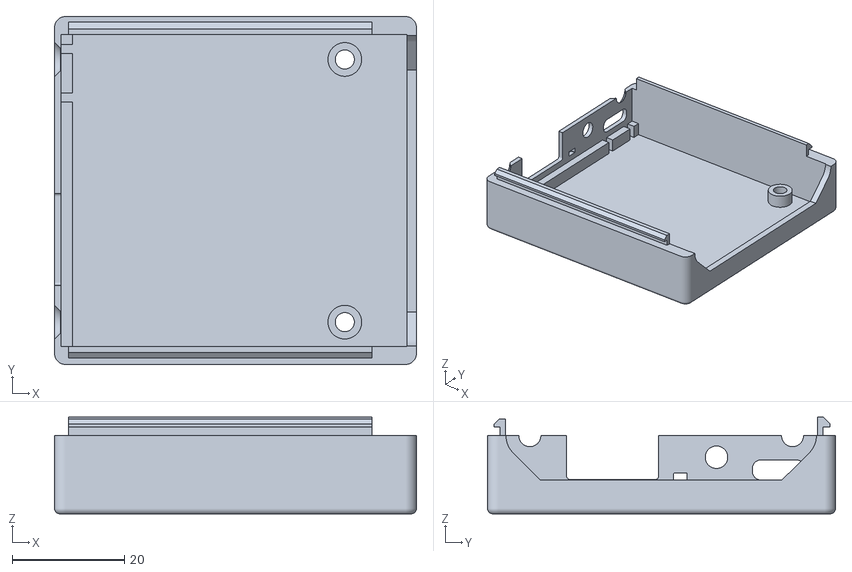
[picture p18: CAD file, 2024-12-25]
Mech/Freecad/STL/PoE_Ethernet_GPIB_Adapter_bot.stl
64.5 x 62.0 x 17.2

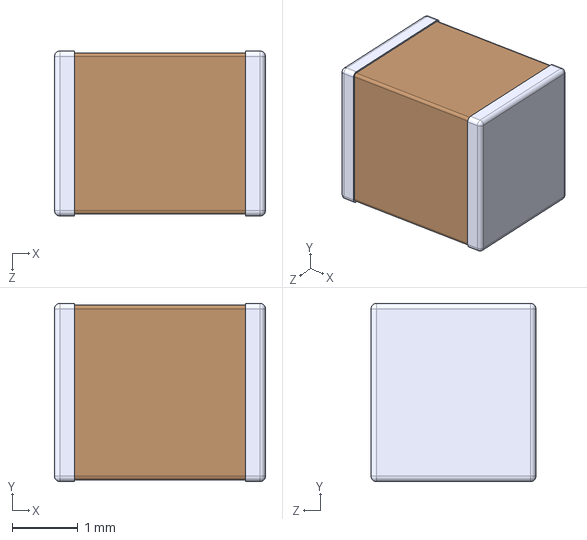
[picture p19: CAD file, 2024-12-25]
HW/3d_models/GRM32EC72A106ME05K.STEP
3.20 x 2.70 x 2.50 mm

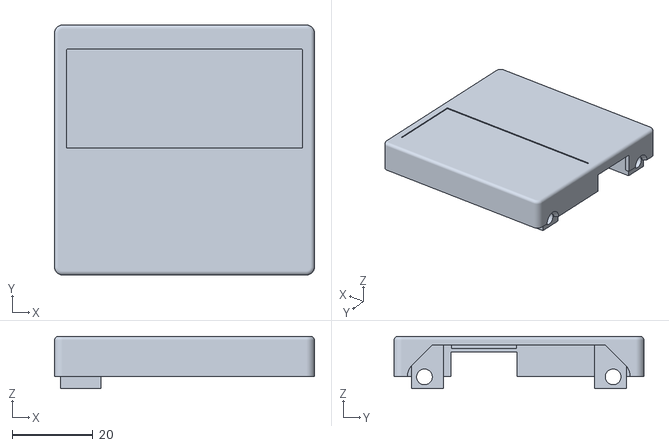
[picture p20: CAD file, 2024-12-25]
Mech/Freecad/STL/PoE_Ethernet_GPIB_Adapter_top.stl
64.5 x 62.0 x 13.0

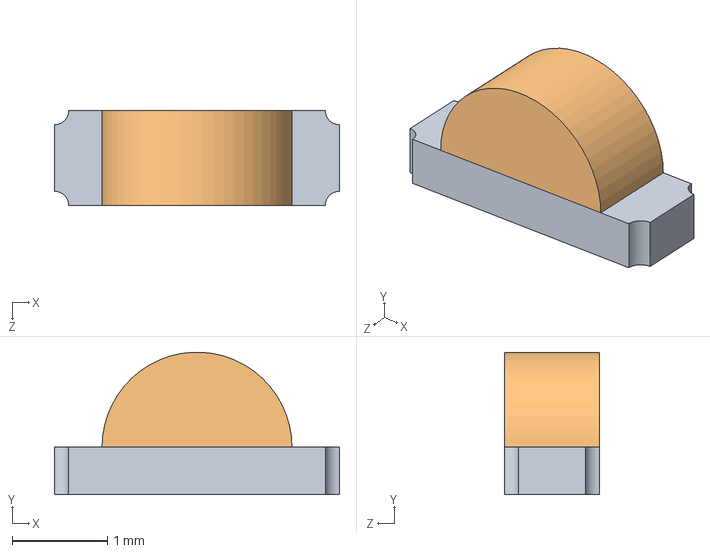
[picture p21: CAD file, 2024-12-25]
HW/3d_models/EASV3015RGBA0.STEP
3.00 x 1.50 x 1.00 mm

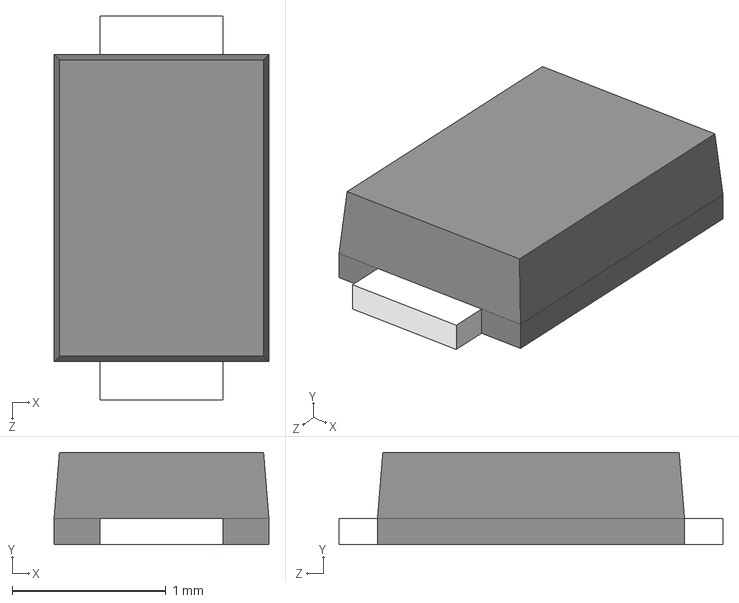
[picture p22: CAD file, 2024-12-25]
HW/3d_models/CUHS20S40,H3F.stp
1.40 x 0.6 x 2.50 mm

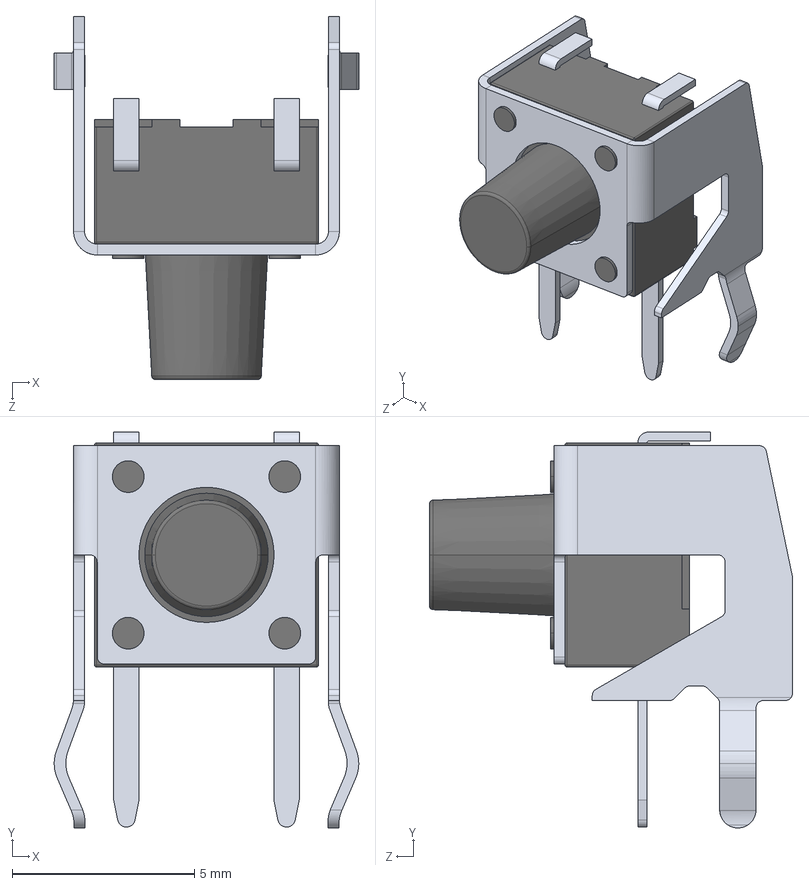
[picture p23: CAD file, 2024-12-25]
HW/3d_models/User Library-Alps TACT SKHH Horizontal Switch.STEP
8.37 x 10.9 x 9.97 mm

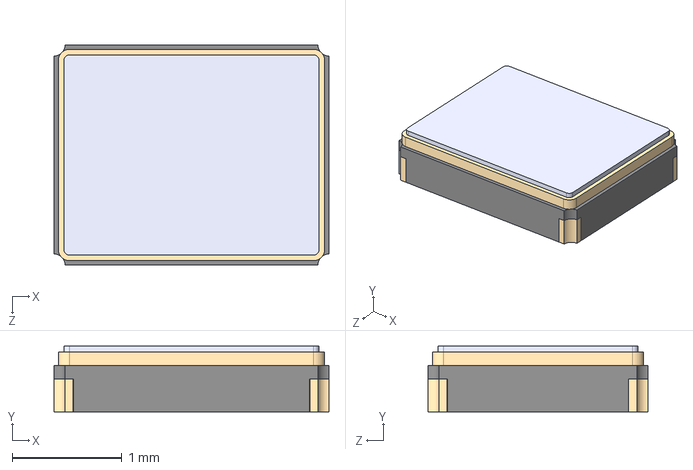
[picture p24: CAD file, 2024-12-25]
HW/3d_models/ECS-250-18-36B2-CTY-TR.stp
2.50 x 0.6 x 2.00 mm

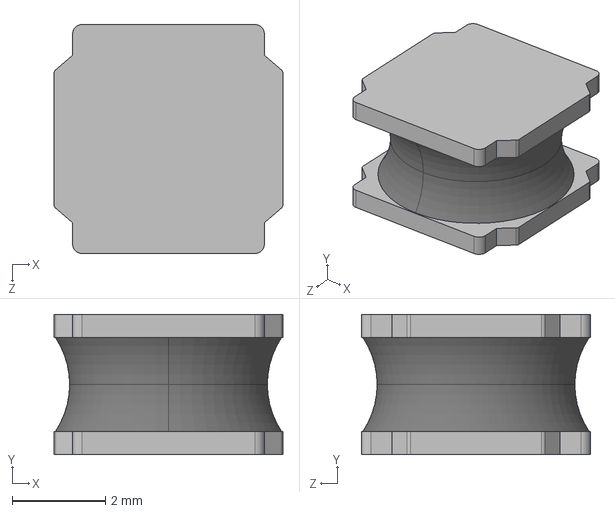
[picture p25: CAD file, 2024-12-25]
HW/3d_models/User Library-SMDpowerInductor.STEP
4.90 x 3.00 x 4.90 mm

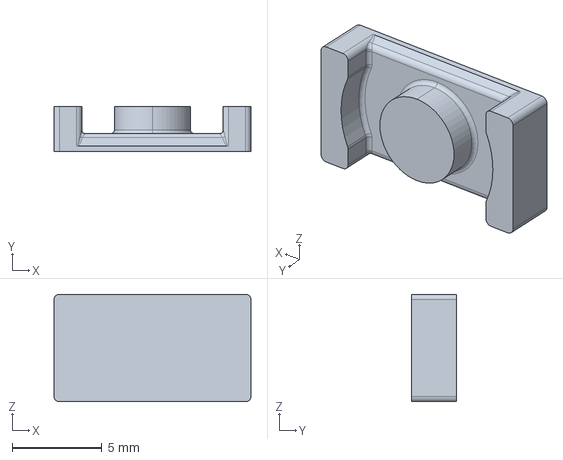
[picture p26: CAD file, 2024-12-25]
HW/3d_models/B65525J0000R087/3D/B65525J0000R087.stp
11.0 x 2.50 x 6.00 mm

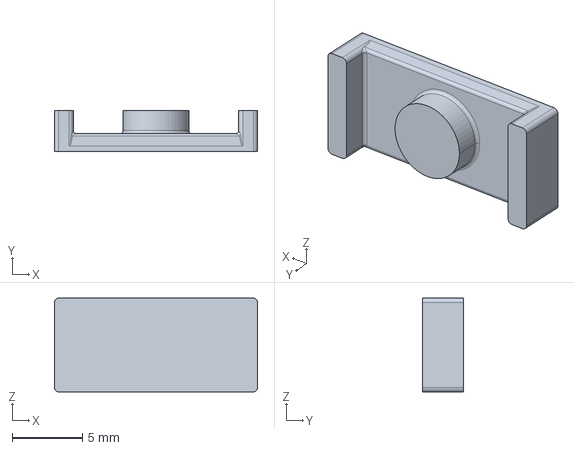
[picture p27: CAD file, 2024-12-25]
HW/3d_models/c61036_a0377_c001_ER14_5.stp
14.5 x 2.95 x 6.70 mm

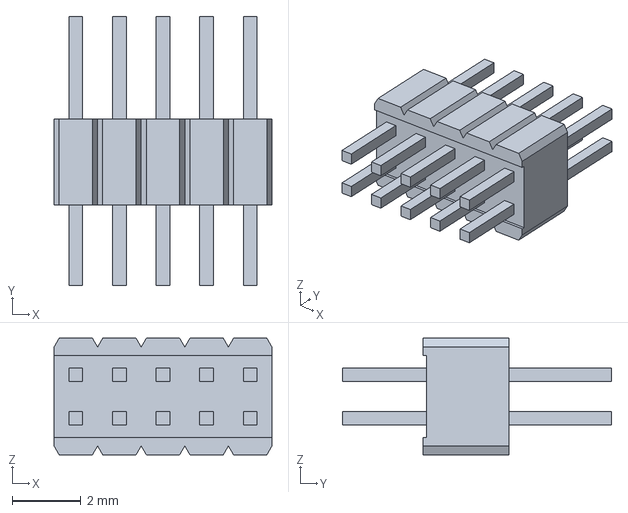
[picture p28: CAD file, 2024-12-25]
HW/3d_models/20021111-00010T1LF.stp
6.35 x 7.85 x 3.40 mm

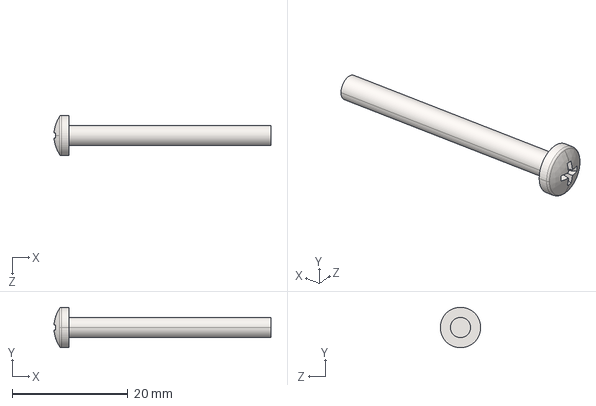
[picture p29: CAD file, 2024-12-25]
HW/3d_models/M3.5 x 35 Screw head.STEP
37.6 x 7.00 x 7.00 mm

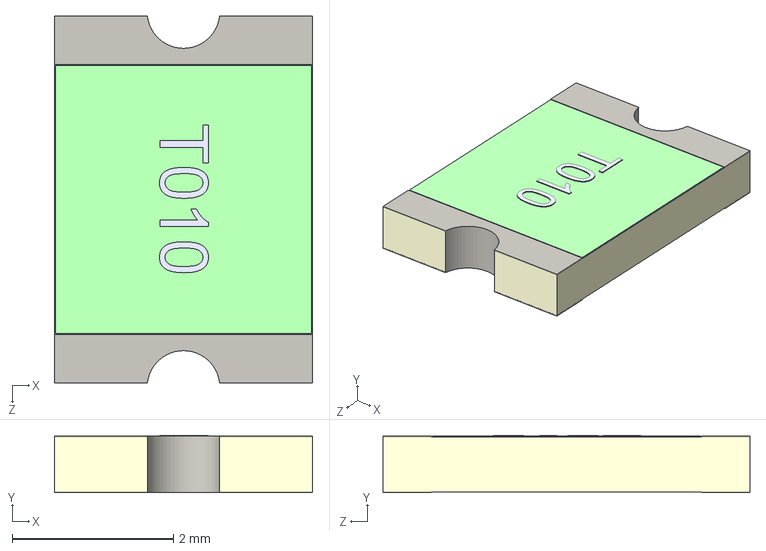
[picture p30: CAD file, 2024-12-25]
HW/3d_models/PTS181213V075.stp
3.20 x 0.71 x 4.55 mm

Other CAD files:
HW/3d_models/155124M173200.step

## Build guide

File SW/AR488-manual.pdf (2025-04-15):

# AR488 GPIB Controller

# User Manual

### Version:

0.53.03

### Dated:

8

## th April 2025

# Twilight Logic

01001010 01000011 01001000

- 1 -

## Table of Contents

- 2 -

- 3 -

A – ATMega328P Boards | 91
Connection details for UNO and Nano | 91
Wiring diagram | 92
B - ATMega2560 boards | 94
Connection details for layout AR488_MEGA2560_D | 94
Connection details for layout AR488_MEGA2560_E1 | 96
Connection details for layout AR488_MEGA2560_E2 | 97
Wiring Diagram for layout - AR488_MEGA2560_D | 98
Wiring Diagram - layout E1 and E2 | 99
E1/E2 layout end header pinout details | 100
C – ATMega32u4 Boards | 101
Connection details for the Arduino Micro | 101
Connection details for the Leonardo R3 | 103
D – Raspberry RP2040/RP2350 Boards | 104
Connection details for Raspberry Pico/W layout RAS_PICO_L1 | 104
Connection details for Raspberry Pico/W layout RAS_PICO_L2 | 106
E – Espressif ESP32 Boards | 108
Connection details for layout ESP32_DEVKIT1_WROOM_32 | 108
Connection details for layout ESP32_TTGO_T8_161 | 109
Connection details for layout ESP32_LOLIN32_161 | 110
Connection details for layout ESP32_ESP32DEV | 111
F – MightyCore ATMega644/1284 Boards | 112
Connection Details for layout AR488_MEGA644P_MCGRAW | 112
G - IEEE Connector Pinout | 113
- 4 -

## The AR488 GPIB Controller

## Introduction

The AR488 GPIB controller is an Arduino-based controller for interfacing with IEEE488 GPIB

devices. The code has been tested on Arduino Uno and Nano 328p boards, the Mega 2560 board,

Micro and Leonardo 32U4 boards and MicroCore ATMega644 and ATMega1024 boards. It

provides a low cost alternative to other commercial interfaces. There is also a forked version for

the ESP32 which can be found here:

https://github.com/douardda/AR488/tree/esp32

A list of other related projects and utilities built by others can be found here:

https://www.eevblog.com/forum/projects/ar488-arduino-based-gpib-adapter/msg2184323/

#msg2184323 (https://www.eevblog.com/forum/projects/ar488-arduino-based-gpib-adapter/msg2184323/#msg2184323)

To build an interface, at least one of the aforementioned Arduino boards will be required to act as

the interface hardware. Connecting to an instrument will require a 16 core cable and a suitable

IEEE488 connector. This can be salvaged from an old GPIB cable or purchased from electronics

parts suppliers. Alternatively, a PCB board can be designed to incorporate a directly mounted

IEEE488 connector.

The project can be expanded by optionally adding the SN75160 and SN75161 GPIB transceiver

integrated circuits. These devices provide proper tri-state IO and buffering between the Arduino

and the GPIB bus. Details of construction as well as mapping of the Arduino pins to GPIB control

signals and the data bus are explained in the Building an AR488 GPIB Interface section.

The interface firmware supports standard Prologix commands (with the exception of ++help) and

adheres closely to the Prologix syntax, but there are some minor differences. In particular, due to

issues with the longevity of the Arduino EEPROM memory, the ++savecfg command has been

implemented differently. A number of additional custom commands have also been implemented.

Details of all commands can be found in the Command Reference section.

The Table of Contents section of this document is hyperlinked. Use Ctrl + Right-Click on the mouse

to go directly to the relevant section of the document.

- 5 -

## Driver Installation

In order to be able to connect to a computer via USB, the above mentioned boards will usually

have an on-board serial to USB converter chip. Windows 7, Windows 10 and Windows 11 will

automatically recognize the 16u2 chip used on genuine Arduino boards as well as the CHG340G

chips used on alternative boards. It will also recognize the FT232RL adapter board as well as the

CP2102 aused on the ESP32. Windows should automatically install the appropriate driver from

Windows Update and then present a COM port.

The official source for FTDI drivers is here:

https://www.ftdichip.com/FTDrivers.htm

The VCP driver provides a virtual COM port for communication while the D2XX (direct) driver

allows direct access via a DLL interface.

The official CH340G driver source is here:

http://www.wch.cn/download/CH341SER_EXE.html

The official CVP2102 driver can be found here:

https://www.silabs.com/developers/usb-to-uart-bridge-vcp-drivers?tab=downloads

There seems to be no official driver source for the 16u2 chip.

Modern versions of Linux such as Mint, MX and Ubuntu contain these driver modules in the kernel

and so will automatically recognize both chipsets.

There is also an interesting alternative Nano board made by Logic Green. This has an LGT8F328P

(328p) clone MCU capable of twice the speed of the Nano. The UART is a Holtek HT42B534-2 IC.

This UART chip does not appear to be officially supported in Linux seem to be recognized by the

Kernel. There seems to be no official driver source for the Holtek chip but it should be recognized by Windows.

## Firmware Upgrades

The firmware is updated by compiling the source in the Arduino IDE and then uploading the

compiled code over USB, but an AVR programmer can also be used to upload the compiled

firmware binary to the Arduino microcontroller.

Updates are available from https://github.com/Twilight-Logic/AR488

- 6 -

## Wireless Operation

### Bluetooth

The AR488 interface can communicate using a Bluetooth HC05 master module. The HC05 module

supports command mode and can be auto-configured by the AR488 sketch using serial

communication. Details of how to enable and configure this feature can be found in the

Configuration and Bluetooth sections. While it is possible to use the HC06 slave module to provide

Bluetooth communication, the slave module does not support command mode so cannot be

configured remotely by the AR488 sketch. It has to be configured manually. For this reason, the

master module is recommended.

### WiFi

David Douard has produced fork of the AR488 project running on an ESP32. His project can be

found here:

https://github.com/douardda/AR488-ESP32/tree/esp32

## Client Software

The interface can be accessed via a number of software client programs.

Serial Terminal software:

https://www.putty.org/

EZGPIB:

http://www.ulrich-bangert.de/html/downloads.html

KE5FX GPIB Toolkit (GPIB Configurator):

http://www.ke5fx.com/gpib/readme.htm

Python scripts and almost anything that can access the Prologix adapter

Terminal clients connect via a virtual COM port and should be set to 115200 baud, no parity, 8

data bits and 1 stop bit when connecting to the interface. On Linux, the port will be a TTY device

such as /dev/ttyUSB0 or /dev/ttyACM0.

Specific considerations may apply when using an Arduino based interface with EZGPIB and the

KE5FX toolkit. These are described in the Working with EZGPIB and KE5FX section.

- 7 -

## Applications

There are a number of compatible applications that can be used with the AR488:

Luke Mester’s Instrument Control Software (HP3478 and WaveTek 178) :

https://mesterhome.com/gpibsw/ (https://mesterhome.com/gpibsw/hp3478a/)

Data logging software by Nirav Patel:

https://www.eevblog.com/forum/projects/ar488-arduino-based-gpib-adapter/msg3586488/

#msg3586488 (https://www.eevblog.com/forum/projects/ar488-arduino-based-gpib-adapter/msg3586488/#msg3586488)

PyMeasure:
https://www.eevblog.com/forum/projects/ar488-arduino-based-gpib-adapter/msg4604662/

#msg4604662 (https://www.eevblog.com/forum/projects/ar488-arduino-based-gpib-adapter/msg4604662/#msg4604662)

https://pymeasure.readthedocs.io/en/latest/

## GPIB

### A Brief Overview

GPIB is an early technology designed for interconnecting computers, peripherals (displays, disks

and printers) and instruments originally designed by HP and known as the Hewlett-Packard

Interface Bus (HPIB). This was later published by the Institute of Electrical and Electronics

Engineers as document IEEE488/1975. It became adopted by other companies and became known

as the General Purpose Interface Bus (GPIB). The standard has been updated and released as

IEEE488.1 and later IEEE488.2.

The GPIB bus is a parralel bus consisting of 8 data signals to transmit characters plus 8 control

signals. It uses relatively heavy 24 way cables terminated with a 24-way Centronics connector.

Modern implementations can run over Ethernet cables.

There have been further enhancements to the Standards for Programmable Instrumentation

(SCPI) and National Instruments “high speed 488”. Some interesting historical and technical

information can be found here:

https://www.hp9845.net/9845/tutorials/hpib/

Full details of the standard can be found here:

https://webuser.unicas.it/misure/MAQ_OLD%20(VO)/Dispense/DISP_7STANDARD%20IEEE

%20488_2%201992.pdf (https://webuser.unicas.it/misure/MAQ_OLD%20(VO)/Dispense/DISP_7STANDARD%20IEEE%20488_2%201992.pdf)

- 8 -

### GPIB Addressing

In order to identify addresses on the bus, each device has to have a GPIB address. GPIB addresses

range from 0 to 31, there being 32 available addresses in all. Address 0 is often used by the

controller. These are known as primary addresses.

In addition to primary addresses, there is also an expanded addressing scheme known as

secondary addressing. This add a second address byte to the primary address. Addresses range

from 0 to 31 as for primary addressing but the combination of two address bytes allows a larger

number of devices to be addressed.

In order to remote-control an instrument, the controller may send control bytes which also all

have values below 32. So how does the instrument it differentiate these values?

When GPIB sends an address over the bus, the value of the byte that it actually sends will depend

on whether its a primary address or secondary address. The GPIB bus is not a duplex bus, in other

words characters can only be sent in one direction at a time. Therefore, the controller addresses

an instrument to either listen or to talk. This is also done by changing the value of the primary

address. To address a device to listen, the controller will add 32 (0x20) to the primary address

value. To address a device to talk, the controller will add 64 (0x40) to the address value. What this

is actually doing is setting bits 5 and 6 of the address byte. When the controller wants to send a

secondary address, it adds 96 (0x60) to the address which sets both bits.

In this way the instrument can determine whether it has been addressed to listen, talk or has

received a secondary address. This is also why you might see secondary addresses referenced as

values between 0-31 or between 96-126. If neither bit is set, then the value is actually below 32

and the instrument interprets this as a control byte.

The AR488 supports both primary and secondary addressing using the ++addr command. It also

provides two additional commands (++secread and ++secsend) to simplify sending and receiving

data when using a secondary address.

## Operating Modes

The interface can operate in both controller and device modes.

### Controller Mode

In this mode the interface can control and read data from various instruments including Digital

multimeters (DMMs). oscilloscopes, signal generators and spectrum analyzers. When powered on,

the controller and sends out an IFC (Interface Clear) to the GPIB bus to indicate that it is now the

Controller-in-Charge (CIC).

All commands are preceded with the ++ sequence and terminated with a carriage return (CR),

newline [a.k.a. linefeed] (LF) or both (CRLF). Commands are sent to or affect the currently

addressed instrument which can be specified with the ++addr command (see command help for

more information).

- 9 -

By default, the controller is at GPIB address 0.

As with the Prologix interface, the controller has an auto mode that allows data to be read from

the instrument without having to repeatedly issue ++read commands. After ++auto 1 is issued, the

controller will continue to perform reading of measurements automatically after the next ++read

command is used and using the parameters that were specified when issuing that command.

### Device Mode

The interface supports device mode allowing it to be used to send data to GPIB devices such as

plotters via a serial USB connection. All device mode commands are supported.

## Transmission of Commands and Data

All data from the computer is sent to the interface over the USB to Serial. Commands sent to the

interface are prefixed with a double plus sign ++ . Anything sent with this prefix is processed by the

command parser. Data to be sent directly to the instrument is not prefixed and is sent directly

over GPIB to the instrument. Character sequences are terminated with a line ending character,

which is usually CR, LF or CRLF depending on the operating system in use and the terminal

software settings. The terminators are stripped by the interface before the data is processed. A

terminator corresponding to the configuration of the AR488 interface (see ++eos and ++eoi

commands) is then appended before onward transmission over GPIB to the instrument.

Data returned from the instrument is not processed or parsed with one exception. If EOI only is

being used as a terminator, a character may be substituted to indicate a terminator depending on

the configuration of the ++eot and ++eot_char commands.

- 10 -

### Sending Data and Special Characters

Carriage return (CR, hex 0D, decimal 13), newline [a.k.a linefeed] (LF, hex 0A, decimal 10), escape

(hex 1B, decimal 27) and ‘+’ (hex 2B, decimal 43) are special “control” characters. Carriage return

and newline terminate command strings and direct instrument commands, whereas the sequence

‘++’ precedes a command token. Special care needs to be taken when sending binary data to an

instrument, because we do not want control characters to be interpreted as some kind of action.

Rather, they need to be treated as ordinary binary data and transmitted as part of the binary data

stream.

When sending binary data, the above mentioned characters must be ‘escaped’ by preceding them

with a single escape (hex 1B, decimal 27) byte. For example, consider sending the following binary

data sequence:

54 45 1B 53 2B 0D 54 46

It would be necessary to escape the 3 control characters and send the following:

54 45 1B 1B 53 1B 2B 1B 0D 54 46

Without these additional escape character bytes, the special control characters present in the

sequence will be interpreted as actions and an incomplete or incorrect data sequence will be sent.

It will also likely be necessary to prevent the interface from terminating the binary data sequence

with the usual carriage return, newline or both (0D 0A) as this will confuse most instruments and

rely on the EOI signal instead. The command ++eos 3 can be used to turn off the transmission of

termination characters. The command ++eos 0 will restore default operation. See the command

help that follows for more details.

### Receiving Data

Binary data received from an instrument is transmitted over GPIB and then via serial over USB to

the host computer PC unmodified. Since binary data from instruments is not usually terminated by

CR or LF characters (as is usual with ASCII data), the EOI signal can be used to indicate the end of

the data transmission. Detection of the EOI signal while reading data can be accomplished with

the ++read eoi command, while an optional character can be added as a delimiter with the

++eot_enable command (see the command help that follows). The instrument must be configured

to send the EOI signal. For further information on enabling the sending of EOI see your instrument

manual.

- 11 -

### Interrupting Transmission of Data

In normal operation, the user issue the ++ command, the instrument responds and data is

returned form the instrument over serial. Once the transmission is complete, the next ++

command can be sent. However, under certain conditions when the instrument is addressed to

talk, data transmission may continue indefinitely, for example:

- when eos is set to 3 [no terminator character] and the expected termination character is

not received from the instrument

- ‘read with eoi’ has been configured on the interface but the instrument is not configured

to assert eoi

- auto mode is enabled

If this happens, the interface should still respond to the a double plus followed by an exclamation

mark ++! or a command (e.g. ++auto 0 or ++rst). There may be a slight delay before response but

data transmission should stop allowing the interface or instrument configuration to be adjusted.

### Listen-only (LON), Talk-only (TON) and Promiscuous modes

In device mode, the interface supports “listen-only”, “talk-only” and promiscuous modes (for

further details see the ++lon, ++ton and ++prom commands. Talk-only and listen-only modes are

non-addressed modes and do not require a GPIB address to be set. Any GPIB address that has

already been set is ignored. In either of these modes, devices are not controlled by the CIC. Data

characters are sent using standard GPIB handshaking , but GPIB commands are ignored. The bus

acts as a simple one way transmission medium. In LON mode, the device is in listen-only mode and

will receive any data placed on the bus by a talker in Talk-Only Mode. In TON mode the device is in

Talk-Only mode. It can send data only and cannot receive data from other devices on the bus. Only

one talker can exist on the bus, but it is possible to have many listeners.

In Promiscuous mode the interface will ignore addressing and receive any data being sent across

the GPIB bus and can be used when there is a controller on the bus. It will ignore command bytes

and forward only the received data to the serial port.

LON and TON are standard GPIB modes. Promiscuous mode is a custom option provided by the

AR488 interface.

- 12 -

## Configuration

## The Configuration File

Configuration of the AR488 is achieved be editing the AR488_Config.h file. This is a C++ style

header file containing various definition statements, also known as ‘define macros’ , starting with

keyword ‘#define’, that can be used to configure the firmware. The AR488_config.h file must be

included in the main AR488 sketch as well as any other module header file (e.g.

AR488_Layouts.cpp and AR488_Layouts.h) with an include statement:

#include "AR488_Config.h

A number of these definition statements are contained within an #ifdef .. #endif construct, some

of which may contain additional #else or #elif elements. The presence of these constructs is

necessary and they should not be changed or removed. Only the definitions within them should be

changed as required. Nothing should need to be changed in any other file.

The firmware version is defined at the top of the AR488_Config.h file in the format:

#define FWVER "AR488 GPIB controller, ver. 0.51.09, 20/06/2022"

The #define command is a compiler directive instructing it to store the version string, whoch is

contained within the double quotes, in a variable called FWVER. This variable is used to present

the version information within the program. It should not exceed 47 characters in length and

ideally should also not be changed. If required, the string can be overridden using the ++id

command (see the Command Reference).

## Board Selection

The AR488 supports a number of Arduino AVR boards and also a custom GPIO pin layout which

can be defined by the user in the Custom Board Layout section. If a custom GPIO pin layout is to be

used, then following entry must have the comment characters (preceding ‘//’) removed:

//#define AR488_CUSTOM

Otherwise, the comment characters should remain in place which has the effect of disabling the

definition by designating it as a comment. The compiler ignores comment statements. Following

this is an #ifdef statement containing several sections preceded by an #elif keyword. Each of these

is followed by a token that corresponds to known Arduino definitions for microprocessor types.

The structure looks like this:

- 13 -

/*

* Configure the appropriate board/layout section

* below as required

*/

#ifdef AR488_CUSTOM

…

#elif __AVR_Atmega328P__

…

#elif __AVR_Atmega32U4__

#elif __AVR_Atmega2560__

…
#endif // Board/layout selection

When the custom layout is selected, all other layouts are ignored. If the custom layout is not

selected, then the section corresponding to the automatically detected Arduino microprocessor

will apply. Each section contains a definition referencing one or more pre-defined board layouts

as well as serial port definitions corresponding to the features of specific boards. For example here

are the definitions for boards based on the 328p microprocessor which are found within the

__AVR_Atmega328P__ section of the #ifdef statement:

/*** UNO and NANO boards ***/

#elif __AVR_ATmega328P__

/* Board/layout selection */

#define AR488_UNO

//#define AR488_NANO

The section contains definitions for two boards, namely the Uno and the Nano. Only ONE of these

should be selected by removing the preceding comment characters:

#define AR488_UNO

//#define AR488_NANO

The default entry is AR488_UNO, which selects the pre-defined template for the Arduino UNO

board in AR488_Hardware.h. Selecting AR488_NANO will select the pre-defined template for the

Nano board. In order to compile the sketch for the selected board, in addition to selecting the

template in Config.h, the correct board must be selected in the Board Manager within the Arduino

IDE (see Tools | Board: ).

It is important to make sure that the correct board is selected in the Arduino IDE Boards Manager (Tools => Board) otherwise the sketch will not compile correctly.

## Serial Port Configuration

### Hardware Serial Ports

The firmware implements separate ports for data flow and debug messages. These can be enabled

activating or de-activating the DATAPORT_ENABLE and DEBUG_ENABLE flags by adding or

removing the preceding comment ‘//’ character sequence. In order to receive data from

instruments and responses to commands, DATAPORT_ENABLE must be defined, otherwise the

port will be disabled and there will be no output. It is not recommended to comment this flag out.

- 14 -

Here is an example of the serial port configuration section for the data port:

/***** Communication port *****/

#define DATAPORT_ENABLE

#ifdef DATAPORT_ENABLE

// Serial port device

#define AR_SERIAL_PORT Serial

// #define AR_SERIAL_SWPORT

// Set port operating speed

#define AR_SERIAL_SPEED 115200

// Enable Bluetooth (HC05) module?

//#define AR_SERIAL_BT_ENABLE 12 | // HC05 enable pin
//#define AR_SERIAL_BT_NAME "AR488-BT" | // Bluetooth device name
//#define AR_SERIAL_BT_CODE "488488" | // Bluetooth pairing code

#endif

AR_SERIAL_PORT specifies the port name to use.

AR_SERIAL_SPEED specifies the baud rate to use.

On most interfaces the primary serial interface is called Serial, however interfaces come in various

flavours. Boards such as the UNO, Nano and Mega2560 implement a hardware UART chip. The

primary port on boards that are based on the 32u4 microcontroller, such as Micro Pro and

Leonardo, is implemented in firmware and called a CDC port. In addition, these boards have a

hardware port called Serial1 implemented on the Rx/Tx pins.

The Mega 2560 has 4 hardware serial ports so either of ‘Serial’, ‘Serial1’, ‘Serial2’ or ‘Serial3’

should be selected. Most likely the default port named Serial will be used although other options

are possible if required. However, please note that the default GPIO pin layout for the Mega 2560

board (AR488_MEGA2560_D) uses the pins assigned to Serial2 for other purposes, so this cannot

be used as a serial port when that particular layout definition is in use. However, it can be used with the E1 and E2 definitions.

Since the format for serial port names is standard for both hardware and CDC ports, the Arduino

handles this automatically behind the scenes.

### Software Serial Library

A serial port can also be implemented using a library called SoftwareSerial which allows a pair of

arbitrary GPIO pins to be used to run a serial port. The AR488 supports this option, although ports

implemented using this library have a practical speed limitation of 57600 baud. Ports implemented

using the SoftwareSerial library need additional configuration options to be specified.

To define a SoftwareSerial port, the entry:

#define AR_SERIAL_PORT Serial

Needs to be commented out. Instead the line:

// #define AR_SERIAL_SWPORT

- 15 -

Needs to be uncommented by removing the preceding ‘//‘.

The SoftwareSerial port section then needs to be configured by specifying the RX and TX pins as

shown in the example below:

#if defined(AR_SERIAL_TYPE_SW) || defined(DB_SERIAL_TYPE_SW)

#define SW_SERIAL_RX_PIN 11

#define SW_SERIAL_TX_PIN 12

#endif

It should be noted only ONE SoftwareSerial port can be set per board, and only ONE serial port can

be enabled in within the data port section.

### Enabling Bluetooth Support

The AR488 firmware supports Bluetooth using the HC05 module. Since communication between

the Arduino and the HC05 module is via serial, it is important that a serial port is configured as

indicated above first.

Once that is done, Bluetooth can be enabled by un-commenting and configuring the following 3

lines:

//#define AR_SERIAL_BT_ENABLE 12 | // HC05 enable pin
//#define AR_SERIAL_BT_NAME "AR488-BT" | // Bluetooth device name
//#define AR_SERIAL_BT_CODE "488488" | // Bluetooth pairing code

AR_SERIAL_BT_ENABLE sets the GPIO pin that is connected to the EN(able) pin on the HC05.

AR_SERIAL_BT_NAME sets the device name that is broadcast by the HC05.

AR_SERIAL_BT_CODE sets the Bluetooth pairing code.

More detailed information on pairing and setting up in Windows and Linux can be found in the

Bluetooth section.

### Configuring the Debug Serial Port

The Debug port is configured in a similar way to the data port. It can be set to the same port as the

data port, or to a separate one, allowing debug messages to be sent to a separate interface. Here

is an example of the configuration:

//#define DEBUG_ENABLE

#ifdef DEBUG_ENABLE

// Serial port device

// #define DB_SERIAL_PORT Serial

#define DB_SERIAL_SWPORT

// Set port operating speed

#define DB_SERIAL_SPEED 57600

#endif

- 16 -

DEBUG_ENABLE enabled or disables the debug port.

DB_SERIAL_PORT sets the port name.

DB_SERIAL_SWPORT alternatively sets a SoftwareSerial port. The Tx and Rx pins need to be set in

the SoftwareSerial port configuration section. Only ONE SoftwareSerial port can be set per board.

DB_SERIAL_SPEED sets the baud rate for the port.

To enable this feature, first uncomment #define DEBUG_ENABLE. Set the serial port to the port

that will receive the debug messages and configure the baud rate. If using SoftwareSerial,

comment out DB_SERIAL_PORT and un-comment DB_SERIAL_SWPORT instead. Next, configure

the GPIO pins to be used, for example:

#if defined(AR_SERIAL_SWPORT) || defined(DB_SERIAL_SWPORT)

#define SW_SERIAL_RX_PIN 50

#define SW_SERIAL_TX_PIN 51

#endif

The above example will configure a SoftwareSerial port at 57600 baud on GPIO pins 50 and 51.

Please note that the maximum advisable speed for a SoftwareSerial port is 57600 baud.

The next step is to select the debug message you require to view. Selectively enabling debug levels

can be helpful when trying to diagnose a problem. They should not be required or left enabled for

normal running of the interface, but only enabled when required for debugging. One or more of

the following can be enabled by removing the preceding // comment characters:

// Main module

//#define DEBUG_SERIAL_INPUT | // serialIn_h(), parseInput_h()
//#define DEBUG_CMD_PARSER | // getCmd()
//#define DEBUG_SEND_TO_INSTR | // sendToInstrument();
//#define DEBUG_SPOLL | // spoll_h()
//#define DEBUG_DEVICE_ATN | // attnRequired()
//#define DEBUG_IDFUNC | // ID command

// AR488_GPIBbus module

//#define DEBUG_GPIBbus_RECEIVE // GPIBbus::receiveData(), GPIBbus::readByte()

//#define DEBUG_GPIBbus_SEND | // GPIBbus::sendData()

//#define DEBUG_GPIBbus_CONTROL // GPIBbus::setControls()

//#define DEBUG_GPIB_COMMANDS // GPIBbus::sendCDC(), GPIBbus::sendLLO(),

GPIBbus::sendLOC(), GPIBbus::sendGTL(), GPIBbus::sendMSA()

//#define DEBUG_GPIB_ADDRESSING // GPIBbus::sendMA(), GPIBbus::sendMLA(),

GPIBbus::sendUNT(), GPIBbus::sendUNL()

//#define DEBUG_GPIB_DEVICE | // GPIBbus::unAddressDevice(),

GPIBbus::addressDevice

// GPIB layout module

//#define DEBUG_LAYOUTS

// EEPROM module

//#define DEBUG_EEPROM | // EEPROM

// AR488 Bluetooth module

//#define DEBUG_BLUETOOTH | // bluetooth
- 17 -

Provided that ENABLE_DEBUG has been set and one of the above options has been selected,

debug messages will be sent to the configured debug serial port. This can be the same port as the

data port or, where the board provides additional serial ports or where sufficient GPIO pins are

available to use SoftwareSerial, this can be an alternative serial port. The advantage of sending

debug messages to another port is that they will not interfere with normal interface

communications. Debug messages can be viewed on the alternative ‘debug’ port while normal

interface operations are in progress on the communications port.

Debug messages do not include messages shown when verbose mode is enabled with the

++verbose command. When the interface is being directly controlled by another program, verbose

mode should be turned off otherwise verbose messages may interfere with normal operations.

## Serial Handling in Applications and Scripts

When working with programs and scripts (e.g. Python), it should be bourne in mind that the

Arduino is only 64 bytes in size. Due to the memory constraints of the Arduino, the additional

processing buffer provided by the AR488 program is also limited to only 128 bytes. The UART ICs

on some boards provide no handshaking between the PC and the Arduino serial port. Although the

Arduino can keep up pretty well, the serial input buffer can easily overflow with loss of characters

if too much data is passed too quickly. This means that a bit of trial and error may be required

when working with scripts to establish whether and how much delay is required between

commands. A short delay may sometimes be needed to avoid a buffer overflow. The amount of

delay will depend on factors such as the interface hardware being used, the time taken for the

instrument to respond, as well as the GPIB speed of the instrument being addressed.

## Macro Support

Macros in this context are short sequences of commands that can be used to accomplish a

particular task. Controlling an instrument usually requires sequences of commands to be sent to

the device to configure it, or to perform a particular task. Sometimes such sequences are

performed frequently or repetitively. In those circumstances, it may be more efficient to pre-

program the required sequence and then execute it when required using a single command.

The AR488 supports a macro feature which allows user programmed command sequences to be

run when the interface starts up, as well as up to 9 user defined command sequences to be

executed at runtime.

Macros must be programmed before the sketch is compiled and uploaded to the interface. Macros

can be added to the designated AR488 MACROS SECTION in the AR488_Config.h file. Both

interface ++ commands and direct instrument commands can be included in macros. Programming

specific instruments is beyond the scope of this manual as commands will be specific to each

instrument or implemented according to the manufacturers choice of programming language or

protocol. However, in general, in order to create macros, a few simple rules will need to be

followed.

- 18 -

Firstly, macros need to be enabled. In the AR488_Config.h file there are two definitions under the

heading ‘Enable Macros’:

#define USE_MACROS | // Enable the macro feature

#define RUN_STARTUP | // Run MACRO_0 (the startup macro)

The #define USE_MACROS construct enables or disables the macro feature. When this line is

commented out by preceding it with ‘//’ then macros are disabled. Removing the preceding ‘//’

will enable the macro feature.

The #define RUN_STARTUP statement controls whether the start-up macro will run when the

interface is powered up or re-started. The start-up macro is designated MACRO_0 and if #define

RUN_STARTUP is enabled, this macro will run when the interface is powered on or reset.

When #define USE_MACROS is disabled, then the start-up macro will not be activated when the

interface is powered up or reset and none of the user macros (1-9) will be available at runtime.

When enabled, MACRO_0 will run when the interface is powered up or reset but only if #define

RUN_STARTUP is also enabled. The user macros (1-9) will always be available and can be executed

by the user at runtime by using the ++macro command. For more information please see the

++macro command heading in the Command Reference.

The start-up macro can be used in addition to the interface settings that can be saved using the +

+savecfg command, to not only to set up the interface, but also to initialise and configure the

instrument for a specific function. In this way, instrument commands that select function, range

and other control features can be sent automatically as the interface starts up.

Unless steps have been taken to disable the automatic reset that occurs when a USB serial

connection is opened to the interface, the start-up macro will run every time that a serial

connection is initiated to the interface. On the other hand, disabling reset prevents the Arduino

from being programmed via USB, so is not advised unless the intention is to program the Arduino

using a suitable AVR programmer.

In the AR488_Config.h file, sketch, below the help information there is a section that starts:

/********************************/

/***** AR488 MACROS SECTION *****/

/***** vvvvvvvvvvvvvvvvvvvv *****/

#ifdef USE_MACROS

Macros are defined here. The first macro is the startup macro, an example of which might be

defined as follows:

#define MACRO_0 "\

++addr 9\n\
++auto 2\n\

*RST\n\

:func 'volt:ac'

"

/* End of MACRO_0 (Startup macro)*/

- 19 -

Note that the macro code itself, is shown in bold, and has been inserted immediately after the

#define MACRO_0 line and before the ending comment:

#define MACRO_0 “\

macro

“

/*<-End of startup macro*/.

All macro commands comprising the macro must be placed after the ‘\’ on the first line and before

the final quote on the line before the ending comment. Nothing outside of these lines, including

the quote marks and the ‘\’ and after the macro name should be modified. The final quote mark

can be appended to the last command in the sequence if preferred. It is shown here on a separate

line for clarity. Everything between the two quote marks is a string of characters and must be

delimited. The ‘\’ character indicate to the pre-processor that the string continues on the next line.

Each command ends with ‘\n’ which is the newline terminator and serves to delimit each

command. The actual sequence shown above is therefore comprised of 4 commands, each

command ending with ‘\n’ and then a ‘\’ to indicate that the next command is to follow on the

next line. Try to avoid leaving or including any unnecessary spaces.

Each of these commands is either a standard AR488 interface command found in the command

reference, or an instrument specific command. All AR488 interface Prologix style commands begin

with ++ so the first two commands set the GPIB address to 7 and auto to 1. The next two

commands are direct instrument commands using the SCPI protocol, the first of which resets the

instrument and the second selects the instrument AC voltage function.

As shown, each command must be terminated with a ‘\n’ (newline) or ‘\r’ (carriage return)

delimiter character.

User defined macros that can be run using the ++macro command follow next, and have a similar

format, e.g:

#define MACRO_2 "\

"

/*<-End of macro 2*/

Once again, the required command sequence must be placed between the two quotes and after

the first ‘/’ and be terminated with a ‘\n’ or ‘\r’ delimiter. Each line must be wrapped with ‘\’.

There is a slightly shorter method of defining a macro by placing all commands on a single line. For

example this:

#define MACRO_1 "++addr 7\n++auto 1\n*RST\n:func 'volt:ac'"

Is exactly the same as this:

#define MACRO_1 "\

++addr 7\n\

++auto 1\n\

*RST\n\

:func 'volt:ac'\

"

- 20 -

The first definition is more condensed and requires no line wrap characters, but it is perhaps

easier to see what is going on in the latter example. Either will function just the same and take up

the same amount of memory.

The macro definition area provided in the sketch ends with:

#endif

/***** ^^^^^^^^^^^^^^^^^^^^ *****/

/***** AR488 MACROS SECTION *****/

/********************************/

Anything outside of this section does not relate to macros.

Provided that the commands have been specified correctly and the syntax is correct, the sketch

should compile and can be uploaded to the Arduino. The start-up macro will run as soon as the

upload is completed so the instrument should respond immediately. Please be aware that, unless

serial reset has been disabled, it will run again when a USB serial connection is made to the

interface. The instrument will probably respond and reconfigure itself again.

Please note that, although AR488 interface ++ commands are verified by the interface, and will

respond accordingly, there is no sanity checking by the interface of any direct instrument

commands. These command sequences are sent directly to the instrument, which should respond

as though the command sequence were typed directly into the terminal or sent from a suitable

instrument control program. Please consult the instrument user manual for information about the

behaviour expected in response to instrument commands.

Macro sequences can include any number delimiter separated of commands, but any individual

command sequence should not exceed 126 characters. This may be particularly relevant to SCPI

commands which can be composed of multiple instructions separated by colons.

## SN7516x GPIB Transceiver Support

Support for the SN75160 and SN75161 GPIB transceiver integrated circuits can be enabled by

uncommenting the following line:

//#define SN7516X

The pins used to control the ICs are defined in the section that follows:

#ifdef SN7516X

#define SN7516X_TE 6

// #define SN75161_DC 13

#endif

- 21 -

Specify the pin to be used for the SN7516X_TE signal. The above example shows pin 6 being used

and this is connected to the talk-enable (TE) pin on both ICs. The SN75161 handles the GPIB

control signals and in addition to the TE pin, also has a direction-control (DC) pin. This is used to

determine controller or device mode operation. A GPIO pin can be assigned to drive this pin, in

which case the SN75151_DC definition shown above should be uncommented and an appropriate

GPIO pin number assigned.

Alternatively, since the REN signal is asserted in controller mode and un-asserted in device mode,

this signal can be used to drive the DC pin of the SN75161. In this case, the SN75161_DC definition

should remain commented out and the GPIO pin assigned to the REN signal should be connected

to both DC and REN on the SN75161 IC. There is one small caveat when using this configuration.

The custom ++REN command, which is used to turn the REN line on and off, cannot be used and

will just return:

Unavailable.

If a separate GPIO pin is used to control DC then the ++REN command will return the status of REN

as usual. (See ++REN in the Custom Comands section of the Command Reference).

## Custom Board Layout Section

The custom board layout section in the Config.h file can be used to create a custom pin layout for

the AR488. This can be helpful for non-Arduino boards and where an adjustment to the layout is

required in order to accommodate additional hardware. By default, the definition implements the

Uno layout:

#define DIO1 | A0 | /* GPIB 1 | */

#define DIO2 | A1 | /* GPIB 2 | */

#define DIO3 | A2 | /* GPIB 3 | */

#define DIO4 | A3 | /* GPIB 4 | */

#define DIO5 | A4 | /* GPIB 13 */

#define DIO6 | A5 | /* GPIB 14 */

#define DIO7 | 4 | /* GPIB 15 */

#define DIO8 | 5 | /* GPIB 16 */

#define IFC | 8 | /* GPIB 9 | */

#define NDAC | 9 | /* GPIB 8 | */

#define NRFD | 10 | /* GPIB 7 | */

#define DAV | 11 | /* GPIB 6 | */

#define EOI | 12 | /* GPIB 5 | */

#define SRQ | 2 | /* GPIB 10 */

#define REN | 3 | /* GPIB 17 */

#define ATN | 7 | /* GPIB 11 */

To make use of a custom layout, AR488_CUSTOM must be selected from the list of boards at the

beginning of the Config.h file and the pin numbers/designations in the centre column (shown in

bold) should be configured as required.

- 22 -

Please note that on some MCU boards, a number of GPIO pins may not be available as inputs

and/or outputs despite a pad or connector being present. Please check the board documentation.

Sometimes such information is revealed only in online forum discussions or blogs.

When AR488_CUSTOM is defined, interrupts cannot be used to detect pin states and therefore

USE_INTERRUPTS will not be defined and interrupts will not be activated. Pin states will be

checked on every iteration of void loop() instead.

- 23 -

## Building an AR488 GPIB Interface

## Overview

Construction of an Arduino GPIB interface is relatively straightforward and requires a supported

single Arduino board, a length of cable that is at minimum 16-way and preferably screened, and an

IEEE488 connector. An old GPIB cable could be re-purposed by removing one end, or an old

parallel printer cable could be used, in which case a separate 24-way IEEE488 connector will need

to be purchased.

New GPIB/IEEE488 cables are expensive. Cheaper cables can be found from various sellers on

eBay. Connectors can be found by searching for ‘Centronics 24’ rather than ‘IEEE488’ or ‘GPIB’. In

the UK, RS Components sell these as part number 239-1207, for £2.86. They can also be found on

eBay. Old parallel printer cables can still be found on charity/thrift shops or on market stalls.

For connection details and wiring diagrams for specific boards, please see:

Appendix A – Uno and Nano (also Logic Green LGT8F328P)

Appendix B – Mega 2560

Appendix C – Micro 32u4

Ideally, in a GPIB cable, ground pins 18, 19, 20, 21, 22, 23 should be connected to a ground wire

that forms a twisted pair with the DAV, NRFD, NDAC, IFC, SRQ and ATN control wires, and a

shielded twisted pair cable with sufficient multiple pairs would be required. However, if such a

cable is not available, then linking them together and connecting them to GND on the Arduino side

should suffice, especially if sufficient numbers of conductors are not available.

Further information can be found by following the links below:

Additional GPIB pinout information - Link 1 (https://www.electronics-notes.com/articles/test-methods/gpib-ieee-488-bus/pinout-pin-connections.php)

Additional GPIB pinout information - Link 2 (https://allpinouts.org/pinouts/connectors/buses/ieee-488-gpib-hpib/)

Once the cable has been completed, the sketch should then be downloaded to the Arduino board

and the interface should be ready to test.

In order to provide multi-platform compatibility, the AR488 firmware sketch is modular and comes

in several files:

- 24 -

Filename: | Purpose:
AR488.ino | This is the main AR488 firmware sketch
AR488_Config.h | This is the configuration file. All configuration options are set here.
AR488_ComPorts.h | Communication ports header file
AR488_ComPorts.cpp | Communication ports implementation
AR488_Eeprom.h | EEPROM functions header file
AR488_Eeprom.cpp | EEPROM functions implementation
AR488_GPIBbus.h | GPIB functions header file
AR488_GPIBbus.cpp | GPIB functions implementation
AR488_Layouts.h | Board layout header file
AR488_Layouts.cpp | Board layout functions implementation

The firmware is supplied in a ZIP file. Download and unpack all files into a directory called AR488.

Load the main sketch, AR488.ino into the Arduino IDE. All the other files should be automatically

loaded by the IDE into separate tabs. Edit the AR488_Config.h file as required and save. Then

select the correct board from the list of boards within the Arduino IDE, Tools | Board menu option

and compile and upload the sketch.

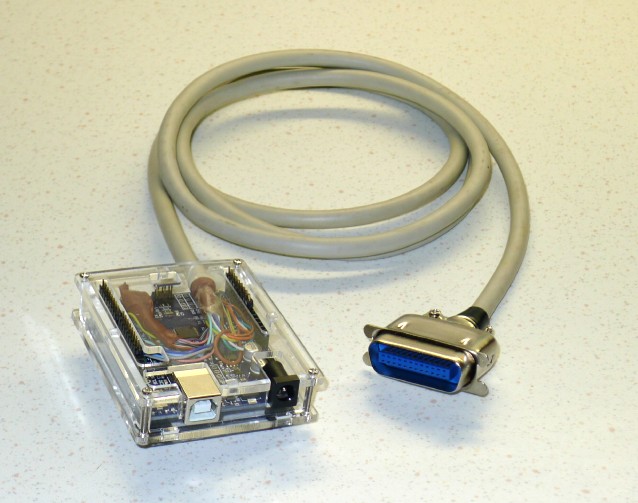
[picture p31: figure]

An example of a completed Arduino GPIB adapter

The following section details further hardware tweaks that may be required to make the board

work correctly with specific GPIB software.

- 25 -

## Multiple Arduino Interfaces on the Bus

The AR488 can be used in both controller mode and device mode and only ONE controller can be

active at any one time. When there is just one Arduino controller on the bus controlling one or

more instruments, this does not present a problem, provided that the Arduino is operating within

its current handling limits.

However, it is possible to have one AR488 operating as a controller and another as a device

simultaneously on the bus along with other instruments. However, without any additional

buffering (see the following section: SN7516x GPIB transceiver integrated circuits), problems can

arise when two or more Arduino interfaces are connected to the GPIB bus and one of them is

powered down. Such problems are manifest by instruments failing to respond to the ++read or

other commands, failing to respond to direct instrument commands, or other erratic bus

communication problems.

The reason for this is because when powered down, Arduino control pins do not present with a

high impedance. In a powered down state, voltages present on the various signal and data lines

are passed via protection diodes internal to the ATMega processor, to the +VCC rail on the

powered down interface. This then causes all pins on the unpowered Arduino to effectively go

HIGH. Furthermore, enough power may be present on the +VCC rail to at least partially power the

processor, which, even if it does manage to operate, may do so in an unpredictable manner and

the result of this may be that the interface does not function correctly with other equipment on

the GPIB bus. This is a parasitic power phenomenon that is not specific to Arduino

microcontrollers only, but can affect various other devices also. Further information regarding this

phenomenon can be found here:

https://www.eevblog.com/forum/blog/eevblog-831-power-a-micro-with-no-power-pin!/

Consequently, unpowered Arduino devices may adversely affect other devices on the GPIB bus. It

is therefore essential to either keep Arduino devices powered on, or else physically disconnected

from the bus. This is NOT an issue when there is just ONE Arduino-based GPIB controller remotely

controlling instruments on a bus. Nevertheless, other than when a sole Arduino is operating as a

controller, it is not recommended to leave unpowered Arduino’s connected to the bus.

## SN7516x GPIB Transceiver Integrated Circuits

The AR488 firmware supports SN75160 and SN75161 GPIB transceiver integrated circuits. These

ICs provide a buffer between the Arduino and the GPIB bus and allow the full 48mA drive current

for a GPIB device. In addition, when powered down, these devices present a high impedance to

the GPIB bus so that the connected device does not interfere with the operation of the bus. This

solves the ‘parasitic power’ problem that ocurrs when using Arduinos connected directly without

buffering to the the GPIB bus and means that theinterface can be safely powered down without

affecting communication on the GPIB bus.

- 26 -

In order to use these GPIB transceiver ICs, at least one SN75160 and one SN75161 will be required

and a separate daughterboard will have to be built. The SN75160 provides 3-state outputs for the

data bus, whereas the SN75161 provides similar isolation for the GPIB control signals. Connection

details can be found in Appendix A, which details connections for the Uno board. A similar

approach can be used for any other board using available GPIO pins.

Operation of the SN75160 is simple. The Arduino outputs are connected to the ‘Terminal I/O

ports’ side of the IC and the GPIB bus DIO lines to the ‘GPIB I/O ports side. The PE pin should be

connected to VCC in order to provide 3-state output. The TE (talk-enable) pin is connected to a

GPIO pin on the Arduino. The GPIO pin is defined in Config.h. For further details see the

Configuration section.

The operation of the SN75161 is a little more complex as part of the IC is controlled by the TE pin,

but also by the DC (direction-control) pin. The TE pin is connected to the same GPIO pin as the

75160 TE pin. The DC pin needs to be driven separately. This can be achieved by connecting DC to

a seperate GPIO pin which can also be defined in Config.h. Alternatively, it can be controlled by the

REN signal. The REN signal is asserted (LOW) in controller mode and un-asserted (HIGH) in device

mode which conveniently corresponds to the drive signal required for DC to switch between

controller and device mode. When REN is being used to control DC, it cannot be turned off as this

would switch the IC into device mode and communication would fail. For this reason, the ++REN

command is not available in this configuration (see ++REN in the Custom Commands section for

details on the behaviour of this command).

The SN75162 IC differs from the SN75161 in that the REN and IFC signals are independently

controlled. The input required is the inverse of the DC signal. Conceivably a separate GPIO pin

could be used to drive the SC pin of the SN75162 but this is currently untested and unsupported.

Alternatively some means of hardware inversion could be devised and the pin connected to DC,

but in this case, experiment at your own risk.

## Arduino Brownout Detection Setting

The first three bits of the Arduino extended fuse determine the brownout detection (BOD) setting.

BOD will hold the processor in the reset state when the power rail voltage falls below a specific

threshold. There are three threshold levels that can be set depending on the bits that is set.

On the boards that were used for development, the default setting of the Extended Fuse seems to

be FD, which means that the last three bits will be 101 and therefore that the BOD level is set to

BODLEVEL1.

It has been reported that when BOD is disabled (e.g. fuse set to FF) and the Arduino signal pins are

connected to power, that under some circumstances the Arduino flash memory can get corrupted

and the sketch will have to be downloaded again. It is therefore inadvisable to disable BOD on an

Arduino being used as a GPIB interface.

- 27 -

Arduino BOD settings are as follows:

BOD Level: | Bit setting | Threshold
DISABLED | 111 | BOD disabled
BODLEVEL0 | 110 | 1.7 – 2.0v (avg 1.8v)
BODLEVEL1 | 101 | 2.5 – 2.9v (avg 2.7v)
BODLEVEL2 | 100 | 4.1 – 4.5v (avg 4.3v)

To check the extended fuse setting, the following AVRDUDE command line can be used:

UNO/NANO:

avrdude -P /dev/ttyACM0 -b 19200 -c usbasp -p m328p -v

MEGA 2560:

avrdude -P /dev/ttyACM0 -b 115200 -c usbasp -p m2560 -v

MEGA 32u4:

avrdude -P /dev/ttyACM0 -b 115200 -c usbasp -p m32u4 -v

The ATMega328p part can be specified as -p m328p or -p atmega328p. The Mega 2560 and Mega

32u4 can also be specified using either convention. If your Arduino has a 328pb processor IC, then

this will have a different signature to the 328p and the -p parameter needs to be specified as -p

m328pb or -p atmega328pb.

- 28 -

## USB-to-Serial UART ICs and Handshaking

Most Arduino boards have a serial ports. Some, like the Mega 2560 even have multiple serial

ports. In order to communicate over USB with a PC, most boards will also have a Universal

Asynchronous Receiver Transmitter (UART) chip to implement the Serial to USB connection. The

chip manages the serial transmission of data as well as handshaking between device.

Handshaking is a process for signalling between devices to indicate when they are ready to receive

or send. It prevents data from being lost by one device still trying to send while the other is not yet

ready to receive. It also provides a means to ensure that buffers are managed so that they are not

overrun. Most commonly when computer programs want to communicate over a serial port, they

will make use of two signals – Clear-to-Send (CLS) and Ready-to-Send (RTS). Programs will assert

RTS to indicate that they are ready to send and then check the CTS response to confirm that the

interface is ready to accept data before sending anything. As soon as CTS is de-asserted, the

program will stop sending.

Not all UART chips and boards are implemented equally and some do not provide handshaking at

all. While handshaking may not be a problem when only a few bytes of data are being sent, it can

become an issue where larger volumes of data need to be sent to or from the Arduino over the

USB-to-serial connection. The serial buffer on most MCU boards is very small. On the Uno, Nano

and Leonardo, it is only 64 bytes in size. As can be appreciated, without any mechanism to control

the data throughput, it is likely that this buffer will overflow very quickly. The result is likely to be

data loss. The transmission of data then becomes incomplete and garbled.

From the perspective of a desktop computer or laptop operating system it may look like the

connection is being made to a serial port, in actuality this device is implemented as a virtual serial

port running over a USB connection, with the UART chip on the Arduino handling the incoming

connection. By default, many clone Arduino boards do not implement a method to control data

flow. Because of this, when sending a larger volume of data such as a file, the computer will keep

on sending data to the Arduino regardless of whether the MCU can accept it or not. If the MCU

cannot accept the data, it is simply lost. This problem can be further compounded when data has

to be then sent onward from the MCU. For example, if the Arduino were sending to a plotter, the

MCU may need to wait for the plotter to process the information already in its buffer before

sending it further data. However, it has no way of signalling the serial port to halt transmission

until the plotter is ready. Once again, data loss results because the computer will continue sending

regardless.

A method to control the flow of data at the serial port is therefore essential. This can be

implemented in hardware or in software. One common hardware approach to serial flow control is

to use a pair of additional wires or signals to transmit Request to Send (RTS) and Clear to Send

(CTS) signals which are defined in the RS232 protocol. UART chips often implement these signals

and present them to the PC virtually as part of the virtual serial port implementation.

Alternatively, a software method known as XON/XOFF can be used. XON/XOFF flow control.

XON/XOFF does not require additional wires but uses ASCII characters DC1 (decimal 17, hex 0x11)

to resume transmission and DC3 (decimal 19, hex 0x13) to pause transmission. This can work fine

for text data which does not include those special characters, but might be a problem when

transmitting binary data. This is because binary data can include any byte of a value between 0

- 29 -and 255, which would include the characters just mentioned. For this reason, XON/XOFF can only

reliably be used when sending text data. The advantage of the hardware RTS/CTS method is that it

can be used with both text and binary data. Whichever method is used, each party on the serial

line can exchange signals to pause and restart the transmission. This is known as a handshaking

protocol. For this reason, XON/XOFF is very rarely used nowdays.

When serial is implemented over USB, no additional wires are used as the serial port is

implemented virtually over the USB protocol, however in order to use RST/CTS signals, these

signals must be accessible somewhere. Unfortunately, by default, many alternative Arduino

boards do not support serial handshaking using RTS/CTS signalling by default. Commonly used

clone boards have on board a serial UART IC such as the CH340 or the Holtek HT42B534 which

exposes the RTS and CTS pins, but these pins are usually not connected anywhere. It is, of course

possible that the CH340G could be connected to GPIO pins in order to list16 pten to the RTS signal

from the remote computer and send it a CTS signal. On the Holtek

chip, the CTS pin does not appear to be functional and remains

asserted continuously.

It is also possible to obtain a USB-to-Serial breakout boards, for

example, the most common one of these is the FT232RL USB2.0 to

TTL Serial Adapter breakout board, but there are others such as one

based on the CP2102 or Prolific UART chips.

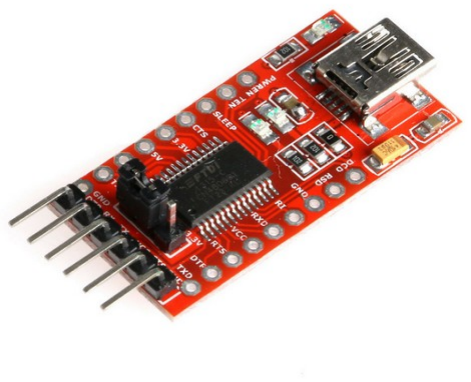
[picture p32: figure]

While serial communications are problematic when using the CH340 or the Holtek HT42B534

chips, they generally work well with FTDI, CP2102 and Prolific chips.

Thankfully Holtek chips are not found very often, but they might be present on some Logic Green

LGT8F328P boards. While the GPIB interface will run on the LGTF328P board, serial handshaking is

not possible with the Holtek UART chip.

## CH340G Serial UART

The CH340G chipset present in many Arduino compatible boards does not respond with the CTS

signal. There appear to be two possible workarounds, one of which requires very good soldering

skills. The RTS and CTS signals are exposed via pins 14 and 9 respectively on the CH340G chip.

While pin 9 connects to an easily accessible pad for soldering, pin 14 is not connected to anywhere

and because it is very small, attaching a wire to it is rather tricky. For this reason, workaround 2 is

easier to implement. Disclaimer: please proceed only if you are confident in your soldering skills. I

take no responsibility for damaged Arduino boards so if in doubt, ask a qualified or skilled person

for assistance.

- 30 -

### Workaround 1

The workaround requires that pin 14 be connected to pin 9 on the CH340G chip. When RTS is

asserted by the host over USB, the signal is passed to the RTS output on pin 14 of the CH340G. This

signal would ordinarily be passed to a serial hardware device which would respond by sending a

response to the CTS input on pin 9 of the the CH340G to indicate that it is ready to send. The

workaround passes this signal back to the CTS input via the link so that a CTS response will always

be echoed back to the host over USB. While this does not provide proper RTS/CTS handshaking, it

does allow the interface to respond with a CTS signal and, in turn, the host to be able to accept

responses to the commands sent to the interface, even when RTS/CTS handshaking is used.

### Workaround 2

Pin 9 of the CH340G needs to be connected to GND. This will keep CTS signal asserted on the

Arduino at all times, so again, proper handshaking is not provided. Simply solder a short wire to

the pad and connect to a convenient ground point.

A big thanks goes to Hartmut Päsler, who is currently looking after the EZGPIB program, for

informing me that the CH340G exposes the RTS/CTS signals via pins and that it might be possible

to make use of these pins to devise a solution.

## FTDI UART (FT232RL)

Arduino boards that contain the ATMEGA MEGA 16u2 chip are recognized as FTDI serial devices.

The functionality provided by the FTDI chip is embedded within this 16u2 chip. This chip does not

expose the RTS/CTS signals so the CH340 style modification is not possible nor is actually required

in order for it to be able to work with the KE5FX toolkit. An Arduino board running with the 16U2

chip running AR488 will work fine with the KE5FX GPIB toolkit, but for some reason.

For some reason, Arduino boards running the 16u2 chip are not recognized by the EZGPIB

program.

## CP2102 UART

Boards such as the ESP32 that have the CP2102 chip on board should work fine over USB,

although, of course, it would no doubt be desirable to operate over WiFi.

- 31 -

## AR488 Bluetooth Support

## The HC05 and HC06 Modules

Bluetooth is a common short range wireless connection technology for

connecting devices and sending data. Bluetooth devices can typically

communicate over distances not exceeding 10 metres, although some devices

can communicate over greater distances. In order to communicate with each

other, Bluetooth devices must be paired. Once paired, the device facilities can

be discovered and a connection established.

Bluetooth transceiver modules such as the HC05 and HC06

can be connected to an Arduino quite easily and manually

configured to provide a wireless connection in place of the

USB cable. These boards come as either the transceiver

board itself with soldered edge connectors only and

requiring a DC 3.3V supply, or, mounted on an “adapter” or

“breakout” board (as shown opposite) with external pin

connectors at one end and which can be supplied directly

with 5V.

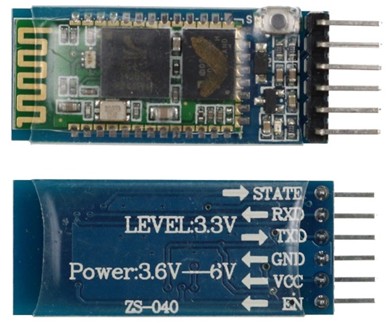
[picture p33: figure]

The AR488 supports auto-configuration of the HC05 Bluetooth breakout board for Arduino. This

board can be just connected to the serial port of the Arduino and the configuration set in

AR488_Config.h file. The HC05 board will be then configured automatically on start-up. Ideally the

board would be connected to the RX and TX pins of a second serial port, e.g. Serial1 on the 32u4

or Serial1/Serial3 on the Mega 2560. The HC06 module does not support master mode, so auto-

configuration is not possible with the HC06. However, either the HC05 and HC06 breakout boards

or modules can be configured manually if required and used with the AR488.

The HC05 and HC06 modules have a very similar appearance, but the HC05 can be identified by

the fact that it has six pins, while the HC06 has only four. There is no EN or STATUS pin on the

HC06.

Unlike most Arduino boards, which are supplied with 5V DC as is

common to all USB devices, the HC05 module requires a 3.3V supply. | The

“adapter” or “breakout” board provides a 3.3V regulator for this

purpose so it can be supplied with 5V, however, the serial input and | output

as well as the enable pin still operate at a 3.3V signalling level as

indicated by the ‘LEVEL:3.3V’ marked on the board. Applying 5V to these pins can damage the

module and while some tutorials do show these connected directly to the RX/TX pins on the

Arduino, this is not recommended and ideally, a level shifter should be used. This can be made

quite easily but ready made boards such as the one shown opposite can also be purchased. Such

boards usually have 4 “channels” (HV1-HV4 and corresponding LV1-LV4) which is sufficient for our

purposes. There are 4 transistors across the centre and 6 soldered connectors along each edge.

They board is usually supplied with a row of pins which can be soldered to the connectors if

required or wires can be soldered to the board directly. The HV side is connected to the Arduino

and the LV side to the HC05.

- 32 -

The level shifter board is easily supplied from the 5V and 3.3V pins on the Arduino with the 5V pin

connected to HV and 3.3V pin connected to LV. The GND connector must be connected to the

Arduino GND pin as well as the HC05 GND pin. Either one or both GND connectors on the level

shifter can be used as they are linked together. The Arduino TX, RX and enable pin connections are

made to one of the HV side channels and connections to the HC05 Bluetooth board are made to

the corresponding LV side channel. It does not matter which actual channel numbers are used for

which function so long as TX on the Arduino connects with RX on the HC05, RX on the Arduino to

the TX on the HC05 and EN on the HC05 connects to the GPIO pin configured for this purpose on

the Arduino, all connections being made via correspondingly numbered HV/LV channel on the level shifter.

The HC05 breakout board requires 5 connections in total including 5V DC power to VCC, GND, TXD,

RXD and EN or “Enable” that enables the Arduino master mode required for configuration. In the

example shown below, the EN pin is connected via the level shifter to pin 6 on the Uno, but any

spare Arduino GPIO pin can be used. The pin marked STATE is left disconnected.

Factory set serial communication speeds also seem to vary and while some modules operate at

38400 baud, others seem to require a 9600 baud connection. The AR488 Bluetooth module will

automatically detect the default speed and set it to the configured speed.

The Bluetooth HC05 transceiver breakout board requires three channels. The diagram below is an

example of how an Arduino Uno might be wired to the HC05 module:

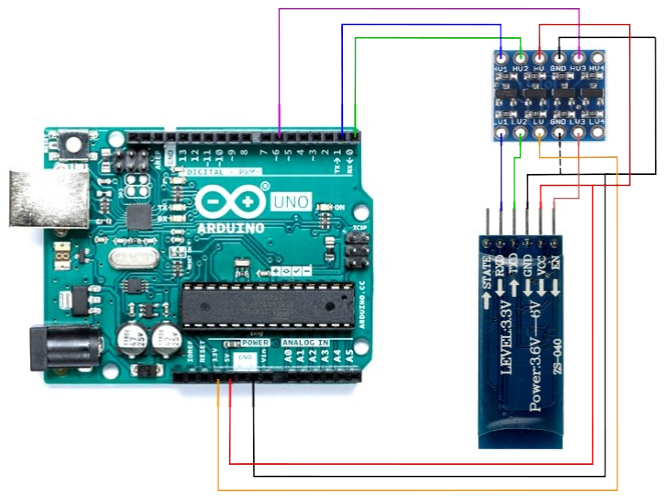
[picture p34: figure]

Diagram of the Arduino to HC05 connections

- 33 -

Clones of the Pro Micro board do not have a 3.3V regulator on board, so a 3.3V supply will have to

be provided separately.

## Enabling Bluetooth on the AR488

The Bluetooth feature is disabled by default, but can be enabled by removing the comment

characters ‘//’ preceding the definition for AR_SERIAL_BT_ENABLE within the data port

configuration section within the AR488_Config.h file:

//#define AR_SERIAL_BT_ENABLE 12 | // HC05 enable pin
//#define AR_SERIAL_BT_NAME "AR488-BT" | // Bluetooth device name
//#define AR_SERIAL_BT_CODE "488488" | // Bluetooth pairing code

so that it becomes:

#define AR_SERIAL_BT_ENABLE 12 | // HC05 enable pin

#define AR_SERIAL_BT_NAME "AR488-BT" | // Bluetooth device name

#define AR_SERIAL_BT_CODE "488488" | // Bluetooth pairing code

This will activate the Bluetooth auto-configuration. Set the pin number to the number of the GPIO

pin that will be used to control the EN pin on the HC05.

The default baud rate can be set to anything that the Arduino and the HC05 board will support.

Please note that there are no double quotes around this parameter.

The default pairing device name is AR488-BT, but this can be changed to anything desired by the

following line:

#define AR_SERIAL_BT_NAME "AR488-BT"

where AR488-BT is replaced by whatever string is desired.

The default paring code is 488488, but this can be changed by modifying the number in quotes

after the AR_BT_CODE keyword:

#define AR_SERIAL_BT_CODE “488488”

The code must be enclosed in double quotes and must be at least 6 digits long.

- 34 -

The diagram above shows a Uno wired up to a HC05 connector. It should be noted that the Uno

and Nano have only one UART and the 328p has only one set of Tx/Rx pins. Since the serial

protocol was designed for 1:1 connections, on these Arduino boards, USB and Bluetooth should

not be used at the same time. The sketch must be uploaded to the Arduino prior to the The HC05

being connected to the Tx/Rx pins, otherwise the upload will fail. Once the sketch has been

uploaded, the module can then be connected and both Arduino and HC05 module powered up.

This is not a problem where an Arduino has additional serial ports available such as the 32u4 and

the Mega 2560. The HC05 can be connected to a secondary port and the USB port used to

program as normal.

## Power-up and Detection

Once the sketch has been configured and uploaded to the board and the HC05 Bluetooth module

connected up, the AR488 can be powered up. On start-up it will automatically detect the baud

rate of the HC05 module and configure it. By default, the AR488 will appear as a Bluetooth device

called AR488-BT, but otherwise should appear with the configured name. On Windows, it may

appear as “Other device” until the screen is refreshed.

The first time that the HC05 board is used, the LED on the HC05 board will initially blink slowly for

a few seconds. The internal LED on the Arduino should then blink twice to indicate that the baud

rate has been successfully detected, and following that, 3 more times to indicate that

configuration has been successful. A few moments after this, the LED on the HC05 should begin

flashing rapidly to indicate that it has switched to slave mode and is ready for pairing.

On subsequent power-up, the LED on the HC05 board will initially blink slowly for a few seconds.

The Arduino internal LED will blink twice to indicate successful auto-detection of the baud rate,

and then once to indicate that the configuration has not changed. The LED on the HC05 will then

blink rapidly to indicate that it has switched to slave mode and the module is ready for pairing.

If the any of the Bluetooth configuration parameters are changed in the sketch, the AR488 will

perform the auto-configuration process again. If nothing has changed, the auto-configuration

process is skipped and the HC05 board just goes into slave mode.

Once paired, the LED on the HC05 board will blink twice every few seconds.

- 35 -

## Pairing the AR488 Bluetooth Interface

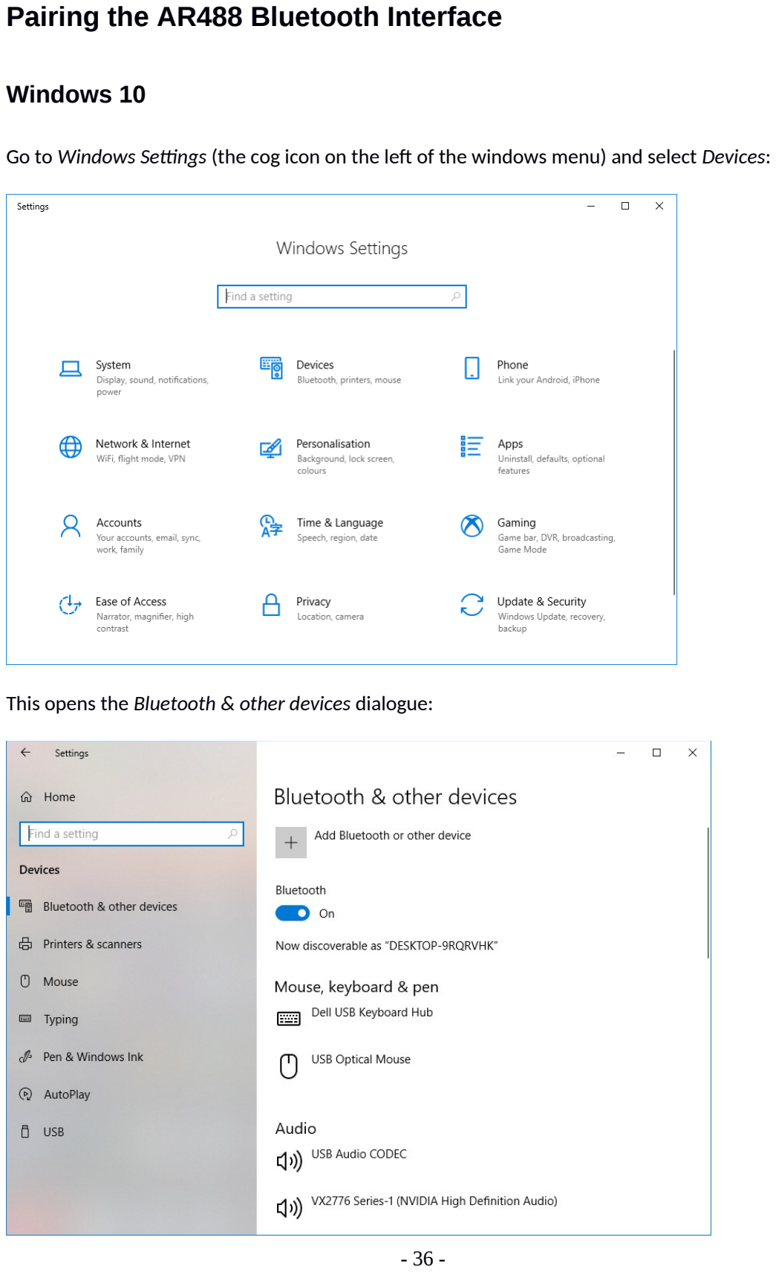
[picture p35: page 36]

### Windows 10

Go to Windows Settings (the cog icon on the left of the windows menu) and select Devices:

This opens the Bluetooth & other devices dialogue:

- 36 -

Make sure that Bluetooth is turned on. Click Add Bluetooth or other device. This will open another

Window:

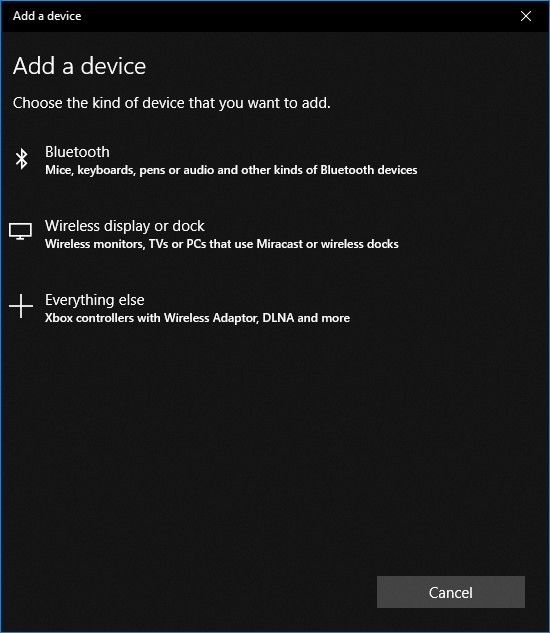
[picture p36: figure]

Click Bluetooth. Windows should now look for devices. It should momentarily show the AR488-BT

device as unknown device, but this should quickly change to AR488-BT.

- 37 -

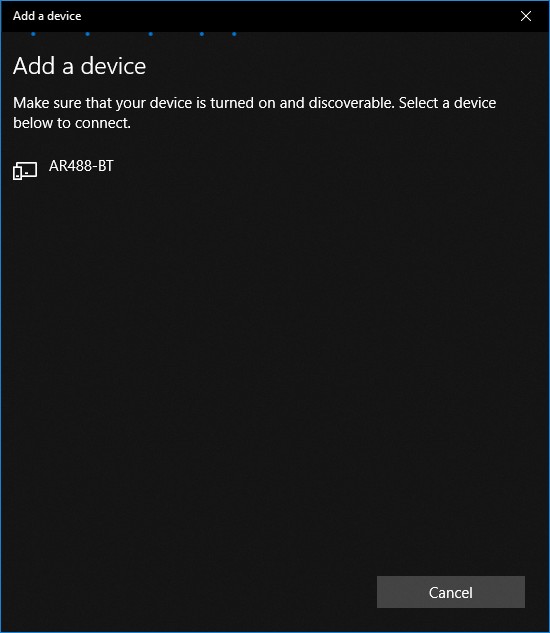
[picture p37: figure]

Click the AR488-BT device. After a few moments prompt will appear requesting the pin.

- 38 -

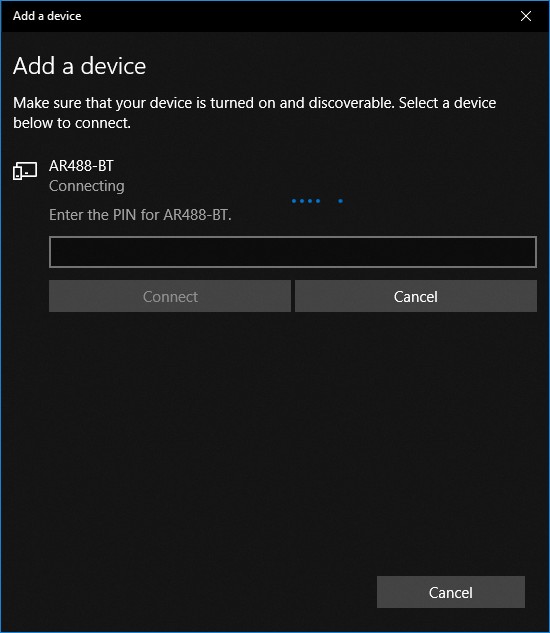
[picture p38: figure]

Enter the pin and click Connect. If it times out, the dialogue may show “Try connecting your device

again”. Click on the device again to try once more. Once successful, this will be clearly confirmed:

- 39 -

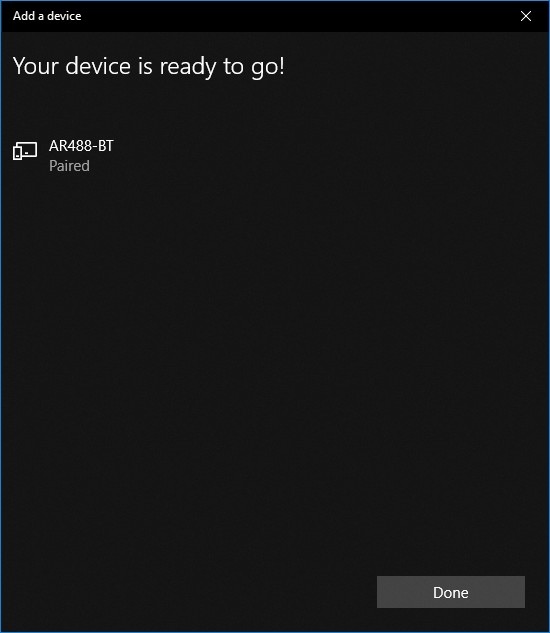
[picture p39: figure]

The device status should now be shown as Paired. Click the Done button to close the device

configuration window.

Back on the Bluetooth & other devices window, scroll down. The AR488-BT device should be listed

under Other Devices. The window can now be closed.

Right-click This PC and select Manage. Click on Device Manager and expand the Port (COM & LPT)

section. The device should be shown as Standard Serial over Bluetooth link (COMx) where COMx

will be the assigned COM port.

Open a terminal session to the assigned COM port and test communication with the device:

- 40 -

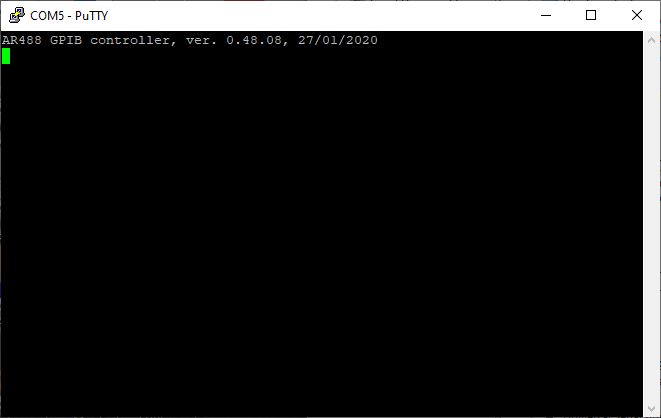
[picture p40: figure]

The interface should respond as normal.

- 41 -

### Linux

These instructions should work on most Linux distributions. Depending on your distro of Linux, the

bluez or bluez5 Bluetooth tools package may already be installed by default, or you may be able to

download and install it from the distribution repository using apt or other package manager.

Otherwise it will need to be compiled from source.

First, make sure that your Bluetooth dongle or built-in device is working correctly on your

computer or laptop.

Make sure that Bluetooth is turned on and your system can identify your Bluetooth hardware.

Once you have confirmed that your Bluetooth hardware is working, open a terminal and at the

command prompt type:

% bluetoothctl

This should list any known Bluetooth devices, show Agent registered at the end of the list, and a

[bluetooth]# prompt:

$ bluetoothctl

[NEW] Controller 00:80:98:94:AB:7E agabus [default]

[NEW] Device 78:3A:84:93:BC:B9 iPad

[NEW] Device 10:2F:6B:BD:49:F1 N930 phone

Agent registered

[bluetooth]#

If your device is not listed, then at the prompt type:

scan on

This should initiate a scan for new devices. In a few seconds any new devices should be listed:

[bluetooth]# scan on

Discovery started

[CHG] Controller 00:80:98:94:AB:7E Discovering: yes

[NEW] Device 98:D3:31:F9:4E:6D AR488-BT

The AR488-BT device should be detected and its mac address listed. To pair the device type:

[bluetooth]# pair 98:D3:31:F9:4E:6D

where the MAC address is the address of YOUR Bluetooth device. The bluetoothctl utility should

respond with something like:

[bluetooth]# pair 98:D3:31:F9:4E:6D

Attempting to pair with 98:D3:31:F9:4E:6D

[CHG] Device 98:D3:31:F9:4E:6D Connected: yes

Request PIN code

[AR481m[agent] Enter PIN code:

- 42 -

Enter the pairing code configured on the HC05 device. The default pairing code is 488488, but if a

custom six digit code has been configured then that should be provided instead. The bluetoothctl

utility will now attempt to pair with the device. If successful, the output should be something like:

[AR481m[agent] Enter PIN code: 488488

[CHG] Device 98:D3:31:F9:4E:6D UUIDs: 00001101-0000-1000-8000-00805f9b34fb

[CHG] Device 98:D3:31:F9:4E:6D ServicesResolved: yes

[CHG] Device 98:D3:31:F9:4E:6D Paired: yes

Pairing successful

[AR488-BT]#

At this point the device is paired, but there is no serial port associated with it. Another tool called

rfcomm can be used to associate a serial port with the Bluetooth device. First exit the bluetoothctl utility by typing:

[bluetooth]# exit

The utiltity will respond with the following and return to the system prompt:

Agent unregistered

[DEL] Controller 00:80:98:94:AB:7E agabus [default]
$

Type the following to associate a serial port with the Bluetooth device:

$ sudo rfcomm bind 0 98:D3:31:F9:4E:6D 1

You may be prompted for the sudo password. After this has command has completed, a serial port

called /dev/rfcomm0 will be created. To confirm that the port binding has been established can be

done with the following command:

$ ls /dev/rfcomm*

/dev/rfcomm0

The repose confirms that the port is now available, so we can open a TTY terminal such as PuTTY

and try to establish a connection to it:

- 43 -

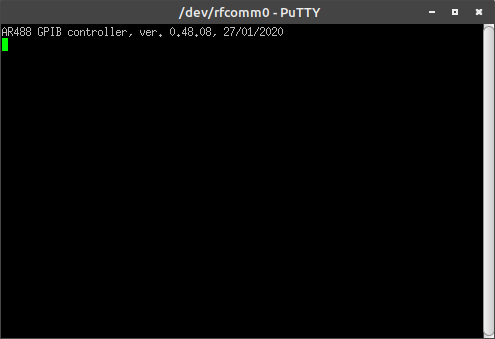
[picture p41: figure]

The terminal should connect and the device should respond in the usual manner.

To unbind the /dev/rfcomm0 port at the end of the session, from the system $ prompt type:

$ sudo rfcomm unbind 0 98:D3:31:F9:4E:6D 1

### Troubleshooting Information for Linux

A noteworthy point is that bluetoothctl is launched while a connected session is in progress, then

the prompt will show the name of the currently connected device:

[AR488-BT]#

To get further information about a device in bluetoothctl, when at the [bluetooth]# prompt type:

info 98:D3:31:F9:4E:6D

where the MAC address is the address of the device you would like further information on. The

program should respond with something like this:

- 44 -

[bluetooth]# info 98:D3:31:F9:4E:6D

Device 98:D3:31:F9:4E:6D (public)

Name: AR488-BT

Alias: AR488-BT

Class: 0x00001f00

Paired: yes

Trusted: no

Blocked: no

Connected: yes

LegacyPairing: yes

UUID: Serial Port | (00001101-0000-1000-8000-00805f9b34fb)

[bluetooth]#

You can also list all the devices that have been paired with:

[bluetooth]# paired-devices

Device 98:D3:31:F9:4E:6D AR488-BT

Device 10:2F:6B:BD:49:F1 N930 phone

[bluetooth]#

To remove a paired device type:

[bluetooth]# remove 98:D3:31:F9:4E:6D

[DEL] Device 98:D3:31:F9:4E:6D AR488-BT

Device has been removed

[bluetooth]#

If bluetoothctl responds with:

Failed to start discovery: org.bluez.Error.NotReady

This may indicate that the device is not powered on or blocked. Try this first:

[bluetooth]# power on

If this reports:

Failed to set power on: org.bluez.Error.Blocked

Then exit bluetoothctl and run this command to check for blocked devices:

$ rfkill list

1: hci0: Bluetooth

Soft blocked: yes

Hard blocked: no

If, as shown above, Bluetooth is ‘Soft blocked’ then it might be possible to unblock it with:

rfkill unblock all

Now run bluetoothctl again.

- 45 -

Otherwise check that device drivers were properly loaded.

If a device is ‘Hard blocked’ then there is a hardware problem, e.g. a toggle switch may be in the

wrong position, faulty cable, power off etc. or the device may be disabled in BIOS.

- 46 -

## Working With Third Party Software

## EZGPIB and the Arduino Bootloader

EZGPIB is is a tool for easy GPIB, TCP or serial based data acquisition in conjunction with a Prologix

GPIB to USB interface. It works with DLL based plugin cards & USB controllers as well as the latest

Prologix LAN GPIB interface. It provides an IDE programming environment that can be used to

work with GPIB devices and supports the Prologix protocol.

On older Arduino boards it was necessary to press the reset button to program the board. This

causes the board to reset and the bootloader to run. The bootloader will expect a particular

sequence of bytes within a timeout period and it will then expect a new compiled sketch to be

uploaded into memory. On completion of the upload, program control is passed to the newly

uploaded code. The timing of the upload is rather tricky and if the timeout period expires or the

upload is started too soon, then it will fail and the board will start with the current program code.

Current versions of the board allow code to be uploaded via USB without having to use the reset

button. This is accomplished by triggering a reset of the board each time a serial connection is

opened. The bootloader is then re-loaded and if the required sequence of bytes is received, and an

upload of code proceeds automatically. When this is finished, program execution passes to the

new code as before.

The problem with this is that the bootloader is loaded every time that the serial port is opened.

This causes a delay of about 1 second before the compiled user program is actually run and the

interface is initialised. EZGPIB (and possibly other programs) that do not re-try the connection

attempt after waiting a second or so, fails to establish a connection to the interface. Closing the

program and immediately trying again usually results in a successful connection. There are a

couple of possible solutions:

### Solution 1 - Capacitor

One option is to eliminate the delay caused by the board re-starting and the bootloader being re-

loaded into memory. This can be done quite easily by placing a 10μF capacitor between the RST

and GND pins on the Arduino. This causes the reset pulse, which is generated by activating the

serial DTR signal, to be drained to ground without affecting the RESET input on the AtMega328P

processor. Since it’s a capacitor, there is no direct DC coupling between RESET and GND. When the

serial port is now opened, the interface will just respond without the delay caused by re-booting.

Assuming the sequence “GPIB-USB” exists in the response to the ++ver command, EZGPIB will now

recognize it first time.

The drawback of this approach is that placing a capacitor permanently in this position will prevent

the Arduino IDE from being able to program the board. The reset button now has to be used or a

switch added to provide an on to run, off to program facility.

- 47 -

### Solution 2 – Hacking the EZGPIB Binary

If you are familiar with using a hex editor, there is another approach that involves editing the

EZGPIB.EXE binary to prevent it looking for an RTS signal being asserted. If the standard Windows

USBSER.SYS driver is used, this never happens, so EZGPIB will never find the GPIB adapter. This

workaround involves changing a specific byte in the RTS Check routine.

Open up a copy of EXGPIB.EXE version 20121217 in a hex editor. Look for the HEX sequence:

F6 04 24 10 74 06

Note, that these instructions can also be found on http://www.dalton.ax/gpib/, but show the

sequence as F6 02 24 10 74 06. I found the sequence to be as above. I’m not sure whether this

is an error or because my binary is different from the one that the author was working with. If you

can’t find the sequence with 04, check for the one with 02.

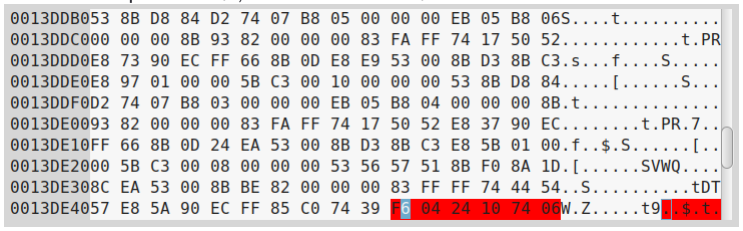
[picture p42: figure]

That sequence is the check for RTS. Change the penultimate byte to 75, so that the sequence now

reads:

F6 04 24 10 75 06

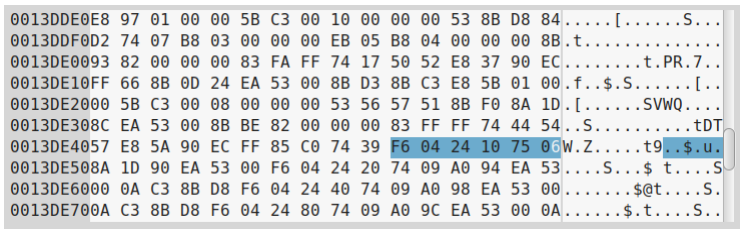
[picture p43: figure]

Now look for sequence:

24 04 10 0F 95

- 48 -

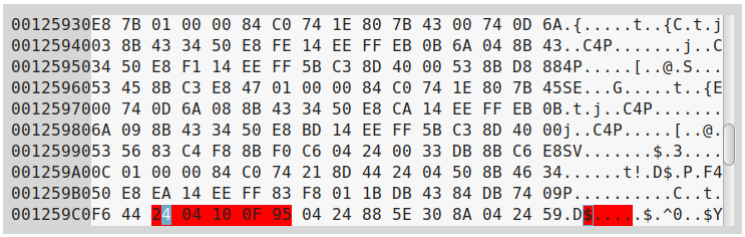
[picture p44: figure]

Change the last byte to 94 so that the sequence now reads:

24 04 10 0F 94

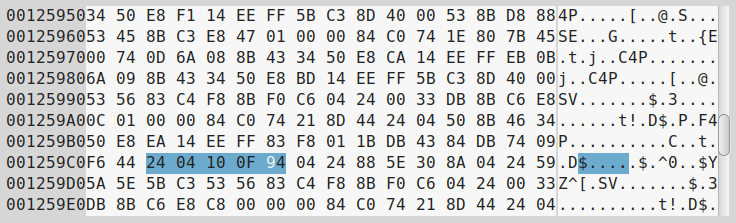
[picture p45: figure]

Save the file and close the hex editor. EZGPIB should now find your adapter.

- 49 -

## The KE5FX Toolkit

KE5FX by John Miles provides testing tools including a plotter emulator and Prologix configuration

utility and can be used with various instruments that support GPIB.

The Prologix GPIB Configurator program that is part of the KE5FX GPIB tools package looks for a

specific character sequence in the string returned by the ++ver command in order to identify a

Prologix interface. The response to the ++ver command must contain the sequence ‘version 6’

somewhere in the returned version string.

On the AR488, the version string displayed with the ++ver command can be set to anything

convenient by using the following example commands:

++id verstr AR488 GPIB-USB version 6

++savecfg

This will set the version string to 'AR488 GPIB-USB version 6' and should be enough to get the

interface recognized by the Prologix GPIB Configurator program. The version number does not

actually require a '.1' suffix, but:

++id verstr AR488 GPIB-USB version 6.1

would work just as well. The ++savecfg command saves the setting to EEPROM. This is important

since the value of the version string that has been set needs to survive a reset. That the string has

been saved can be confirmed by resetting or power cycling the adapter and using the command:

++id verstr

This should display the version string entered using the previous command.

Alternatively, the version string could be set by changing the value of the FWVER variable set using

a #define statement near the beginning of the AR488_Config.h file. This will set the default version

string in the compiled program which will be stored along with the code in program memory and

will not require EEPROM storage.

- 50 -

## Command Reference

The controller identifies commands by prefixing them with a double plus ++ character sequence.

The following sequence of characters is an interface command. When the ++ is omitted, the

sequence of accepted characters is assumed to be destined for and sent directly to the connected

instrument.

The aim of the project was to support the Prologix command set and operate in a manner that is

fully compatible with it. Therefore, with the exception of the ++savecfg command, where

command keywords correspond to a Prologix equivalent, they will operate in the same way and be

fully compatible with the Prologix GPIB-USB controller. However, some commands may have been

enhanced with additional functionality.

In addition, in order to enhance its features and operation, the AR488 controller also implements a

number of custom commands. The command reference that follows will clearly indicate which

commands are standard and which are additional custom commands as well as any enhancements

to the original Prologix command set.

## +addr

Prologix compatible: | yes
Enhanced: | yes
Modes: | controller, device
Description: | Used to set or query the currently set GPIB address. In controller mode, the address refers to the primary GPIB address and optionally the secondary address of the instrument that the operator wishes to communicate with. In device mode, the address represents the address assigned to this interface which is now acting as a device. By default, the address of the controller is 0. When issued without an address, the command returns the currently set primary and optional secondary address.
Syntax: | ++addr [ pri [,sec] ]
Comments: | pri is a GPIB primary address between 1 (0x01) and 30 (0x1E) sec is a GPIB secondary address between 96 (0x60) and 126 (0x7E) sec can also be a number between 0 (0x00) and 31 (0x1F) in which case it will automatically get converted to a range between 0x60 and 0x7F by the addition of 0x60 to the value.
- 51 -

## ++allspoll

Prologix compatible: | no
Enhanced: | n/a
Modes: | controller
Description: | Alias equivalent to ++spoll all. See ++spoll for further details.
Syntax: | ++allspoll

Comments:

- 52 -

## ++auto

Prologix compatible: | yes
Enhanced: | yes
Modes: | controller
Description: | Configure the instrument to automatically send data back to the controller. When auto is enabled, the user does not have to issue ++read commands repeatedly. When set to zero, auto is disabled. When set to 1, the controller will automatically attempt to read a response from the instrument after any instrument command or, in fact, when any character sequence that is not a controller command beginning with ++, has been sent. When set to 2, auto is set to “on-query” mode. The controller will automatically attempt to read the response from the instrument after a character sequence that is not a controller command beginning with ++ has been sent to the instrument, but only if that sequence is a query command that ends with the ? character, such as, for example *IDN?. When set to 3, auto is set to “continuous” mode. The controller will execute continuous read operations after the first ++read command is issued, returning a continuous stream of data from the instrument. The command can be terminated by turning off auto with ++auto 0 or performing a reset with ++rst. When called without a parameter, the command returns the value of the current setting for auto.
Syntax: | ++auto [0|1|2|3]
Comments: | Some instruments generate a “Query unterminated” or “-420” error if they are addressed after sending an instrument command that does not generate a response. This simply means that the instrument has no information to send and this error may be ignored. Alternatively, auto can be turned off (++auto 0) and a ++read command issued following the instrument command to read the instrument response.
- 53 -

## ++clr

Prologix compatible: | yes
Enhanced: | no
Modes: | controller
Description: | This command sends a Selected Device Clear (SDC) command to the currently addressed instrument. Details of how the instrument should respond may be found in the instrument manual. Typically the instrument may perform a reset, but other behaviours are possible.
Syntax: | ++clr

Comments:

## ++dcl

Prologix compatible: | no
Enhanced: | n/a
Modes: | controller
Description: | Send Device Clear (DCL) to all devices on the GPIB bus.
Syntax: | ++dcl

Comments:

- 54 -

## ++default

Prologix compatible: | no
Enhanced: | n/a
Modes: | controller, device
Description: | This command resets the AR488 to its default configuration. When powered up, the interface will start with default settings in controller mode. However, if the configuration has been saved to EEPROM using the savecfg command, the controller will start with the previously saved settings. This command can be used to reset the controller back to its default configuration. The interface is set to controller mode with the following parameters:
auto | 0
eoi | 0 (disabled)
eor | 0 (CR+LF)
eos | 0 (CR+LF)
eot_enable | 0 (disabled)
eot_char | 0
GPIB address - controller | 0
GPIB address - primary | 1
GPIB address - secondary | 0
mode | controller
read_tmo_ms | 1200
status byte | 0
version string | default version string
Syntax: | ++default
Comments: | After using the ++default command and configuring new settings, the ++savecfg command should be used to store the new settings in EEPROM*. Otherwise, the previously stored configuration will be re- loaded from non-volatile memory the next time that the interface is powered up. The interface can be returned to its default state by using ++default followed by ++savecfg without making any further configuration changes.

* this assumes that the board being used supports saving to EEPROM.

- 55 -

## ++eoi

Prologix compatible: | yes
Enhanced: | no
Modes: | controller, device
Description: | This command enables or disables the assertion of the EOI signal. When a data message is sent in binary format, the CR/LF terminators cannot be differentiated from the binary data bytes. In this circumstance, the EOI signal can be used as a message terminator. When ATN is not asserted and EOI is enabled, the EOI signal will be briefly asserted to indicate the last character sent in a multi-byte sequence. Some instruments require their command strings to be terminated with an EOI signal in order to properly detect the command. The EOI signal is also used in conjunction with ATN to initiate a parallel poll, however, the ++eoi command has no bearing on that activity. When issued without a parameter, a value corresponding to the current status of the EOI feature will be returned.
Syntax: | ++eoi [0|1]
Comments: | 0 disables and 1 enables asserting of the EOI signal to indicate the last character sent.
- 56 -

## ++eor

Prologix compatible: | no
Enhanced: | n/a
Modes: | controller
Description: | End of receive. While ++eos (end of send) selects the terminator to add to commands and data being sent to the instrument, the ++eor command selects the expected termination sequence when receiving data from the instrument. The following termination sequences are supported:
Option | Sequence | Hex
0 | CR + LF | 0D 0A
1 | CR | 0D
2 | LF | 0A
3 | None | N/A
4 | LF + CR | 0A 0D
5 | ETX | 03
6 | CR + LF + ETX | 0D 0A 03
7 | EOI signal | N/A

The default termination sequence is CR + LF. If the command is

specified with one of the above numeric options, then the

corresponding termination sequence will be used to detect the end of

the data being transmitted from the instrument. If the command is

specified without a parameter, then it will return the current setting. If

option 7 (EOI) is selected, then ++read eoi is implied for all ++read

instructions as well as any data being retuned by the instrument in

response to direct instrument commands. An EOI is expected to be

signalled by the instrument with the last character of any transmission

sent. All characters sent over the GPIB bus are passed to the serial

port for onward transmission to the host computer.

Syntax: | ++eor[0-9]

Comments:

- 57 -

## ++eos

Prologix compatible: | yes
Enhanced: | no
Modes: | controller, device
Description: | Specifies the GPIB termination character. When data from the host (e.g. a command sequence) is received over USB, all non-escaped LF, CR or Esc characters are removed and replaced by the GPIB termination character, which is appended to the data sent to the instrument. This command does not affect data being received from the instrument. When issued without a parameter, the command will return the current configuration
Syntax: | ++eos [0|1|2|3]
Comments: | 0=CR+LF, 1=CR, 2=LF, 3=none

## ++eot_enable

Prologix compatible: | yes
Enhanced: | no
Modes: | controller, device
Description: | This command enables or disables the appending of a user specified character to the USB output from the interface to the host whenever EOI is detected while reading data from the GPIB port. The character to send is specified using the ++eot_char command. When issued without a parameter, the command will return the current configuration.
Syntax: | ++eot_enable [0|1]
Comment: | 0 disables and 1 enables sending the EOT character to the USB output
- 58 -

## ++eot_char

Prologix compatible: | yes
Enhanced: | no
Modes: | controller, device
Description: | This command specifies the character to be appended to the USB output from the interface to the host whenever an EOI signal is detected while reading data from the GPIB bus. The character is a decimal ASCII character value that is less than 256. When issued without a parameter, the command will return a decimal number corresponding to the ASCII character code of the current character.
Syntax: | ++eot_char [<char>]
Comment: | <char> is a decimal number that is less than 256
- 59 -

## ++eot_char

Prologix compatible: | yes
Enhanced: | no
Modes: | controller, device
Description: | This command specifies the character to be appended to the USB output from the interface to the host whenever an EOI signal is detected while reading data from the GPIB bus. The character is a decimal ASCII character value that is less than 256. When issued without a parameter, the command will return a decimal number corresponding to the ASCII character code of the current character.
Syntax: | ++eot_char [<char>]
Comment: | <char> is a decimal number that is less than 256
- 60 -

## ++flags

Prologix compatible: | no
Enhanced: | no
Modes: | controller
Description: | This command enables flags that perform a rudimentary handshaking

when sending a large volume of data. These are not serial handshaking

flags as such, but provide 3 indicators: interface ready, receive

complete, send complete. When enabled, each of these actions will

generate an output at the serial port of the following character

sequences:

Flag | Bit | Value
AR488~RDY | 1 | 0x01
Read^OK | 2 | 0x02
Send^OK | 3 | 0x04

To turn on an individual flag, specify a value corresponding to its bit.

To turn on multiple flags, the corresponding values are added. For

example to turn on both Read^OK and Send^OK, specify ++flags 6. To

turn on all flags, use ++flags 7.

When turning on the AR488-RDY flag, it is necessary to save the setting

using the ++savecfg command otherwise it will be lost on restart.

Syntax: | ++flag value
Comment: | Bit values are OR’ed (added) to enable only the bits required.
- 61 -

## ++fndl

Prologix compatible: | no
Enhanced: | no
Modes: | controller
Description: | Find listeners: searches the GPIB bus and finds all of the listeners within the given range. Addresses can be specified individually, separated by a space, comma or tab. They can also be specified as a range with a start address and end address separated by a hyphen. There must be no spaces between the hyphen and address values. The whole address range from 0 to 31 can be searched by using the keyword all. The command will return a comma separated list of listener addresses. Listeners on secondary addresses will be presented as an extended address in the format pri:sec.
Syntax: | ++fndl addr, addr, addr…. ++fndl startaddr-endaddr ++fndl all
Comment: | Example oputput: 3,5:1,5:2,5:3,11,22
- 62 -

## ++help

Prologix compatible: | yes
Enhanced: | no
Modes: | controller, device
Description: | Returns a description of the command. The returned information is on the format: ++cmd: [P] Short description of command where ++cmd is the command for which information was requested, [P] or [C] indicate whether this is a Prologix command or an AR488 custom command, and the remaining text is the command description. Entering an invalid command will simply return: Unrecognized command
Syntax: | ++help <command>
Comment: | <command> is a name of a valid command without the ++ prefix
- 63 -

++id

Prologix compatible: | no
Enhanced: | n/a
Modes: | controller
Description: | Sets the identification parameters for the interface. Here you can set the instrument name and optional serial number. This command also sets the information that can be used by the interface to respond to a SCPI *idn? which may be useful where the instrument itself cannot provide such a response. For further information also see the ++idn command.
Syntax: | ++id fwver ++id name [name] ++id serial [serialnum] ++id verstr [version string]
Comment: | ++id name Displays or sets a short descriptive name for the interface. The name can be up to 15 characters long and should not include spaces. If the command is specified without a parameter, it will return the current name of the interface. If specified with a character string, the command will set the interface name to the provided string. By default, the name is not set and the command will not return a value.
| ++id serial Displays or sets an optional 9-digit serial number for the interface. In the event that there are multiple instances of identical instruments on the bus, each instrument can be given a unique serial number. When specified without a parameter, the command returns the currently configured serial number. By default no serial number is set so the command will return ‘000000000’. When specified with a parameter, the command sets the serial number to the provided alphanumeric numeric string.

++id verstr

Displays or sets the user-defined version string that the controller

responds with on startup and in response to the ++ver command. This

may be helpful where software on the computer is expecting a specific

string from a known controller, for example ‘GPIB-USB’. When no

parameter is given, the command returns the current version string.

When provided with a character string of up to 47 characters, the

command will set the version string to the supplied character string.

++id fwver

- 64 -

Displays the actual version of the controller firmware.

Examples:

++id fwver

++id name HP3478A
++id serial 347800001

++id verstr GPIB-USB

++id verstr
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

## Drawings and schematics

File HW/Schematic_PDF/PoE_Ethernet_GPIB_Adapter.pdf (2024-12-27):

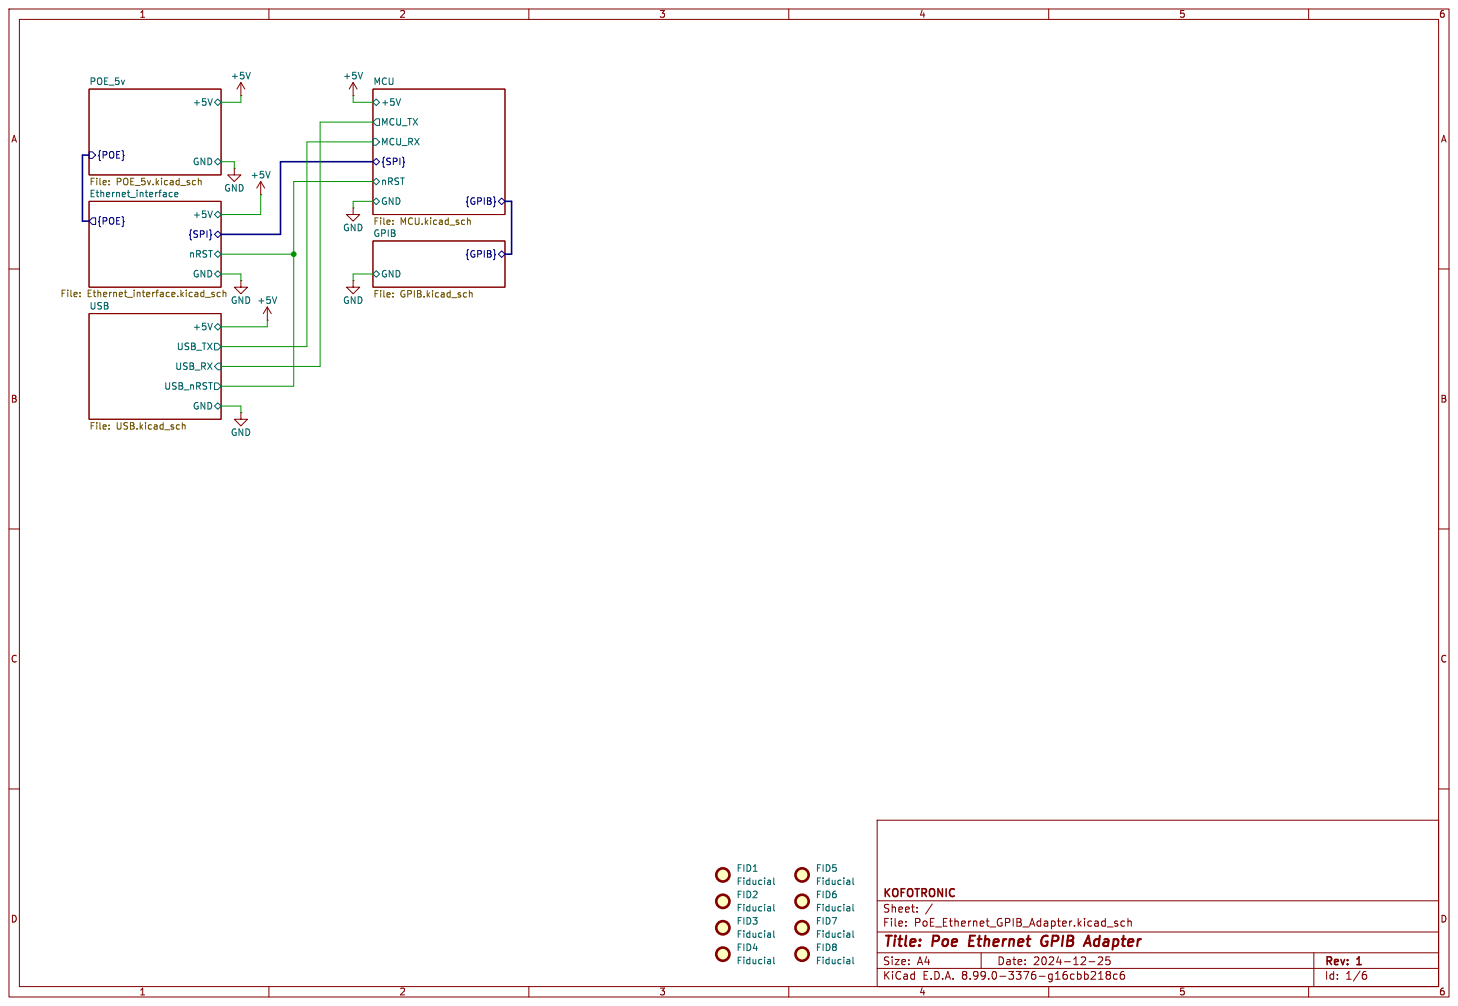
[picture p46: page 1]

Id: 1/6 Title: Poe Ethernet GPIB Adapter File: PoE_Ethernet_GPIB_Adapter.kicad_sch Sheet: / KOFOTRONIC

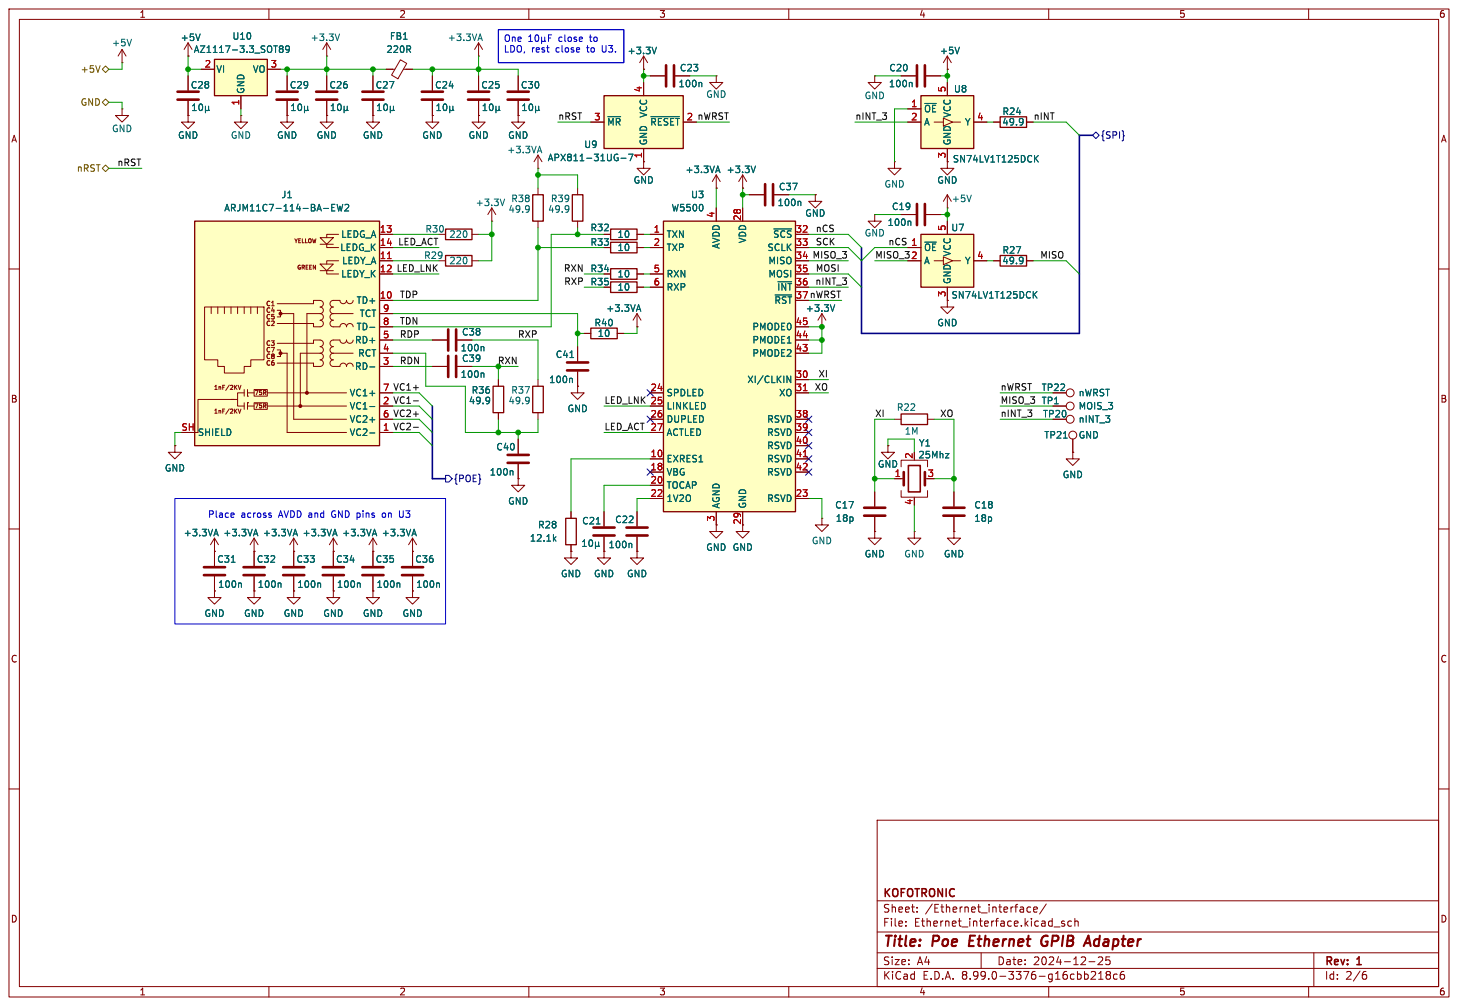
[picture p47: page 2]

1 VO 3 U10 AZ1117-3.3_SOT89 GND GND
LDO, rest close to U3. Place across AVDD and GND pins on U3 GND

3 TXN 1 TXP 2 RXN 5 RXP 6 SPDLED 24

LEDY_K 12 TD+ 10 TCT 9 TD- 8 RD+ 5 RCT 4 RD- 3 VC1+ 7 VC1- 2 VC2+ 6 VC2- 1 SHIELD SH

Id: 2/6 Title: Poe Ethernet GPIB Adapter File: Ethernet_interface.kicad_sch Sheet: /Ethernet_interface/ KOFOTRONIC

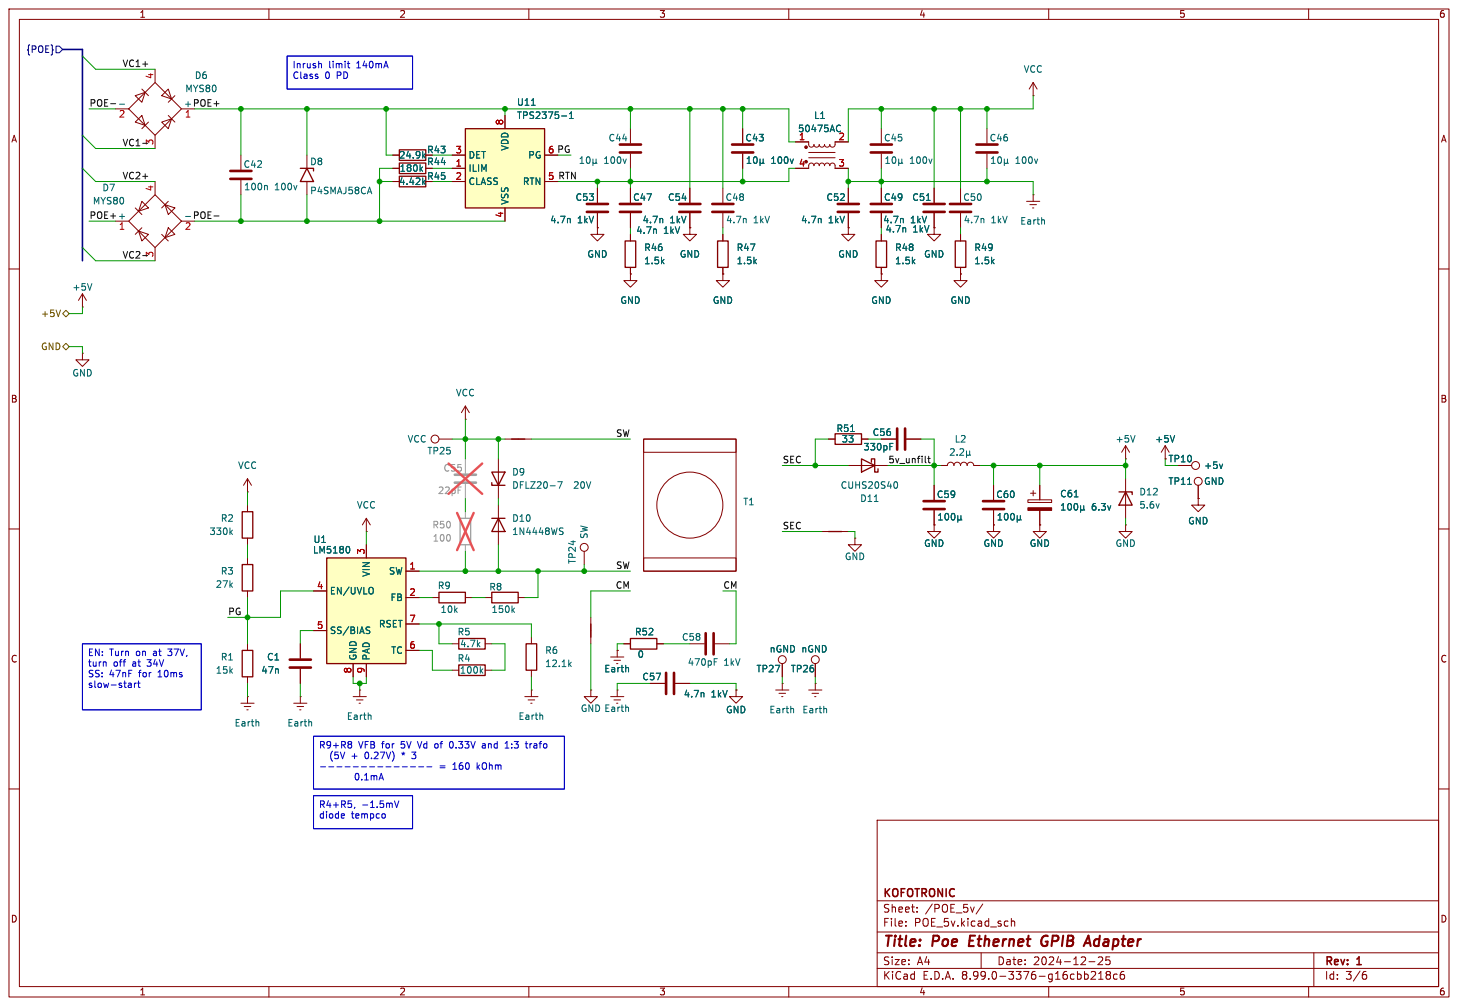
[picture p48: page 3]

Inrush limit 140mA Class 0 PD

9 SW 1 FB 2 RSET 7 TC 6 U1

9 SW 1 FB 2 RSET 7 TC 6 C1

EN: Turn on at 37V,
turn off at 34V
SS: 47nF for 10ms

Id: 3/6 Title: Poe Ethernet GPIB Adapter File: POE_5v.kicad_sch Sheet: /POE_5v/ KOFOTRONIC

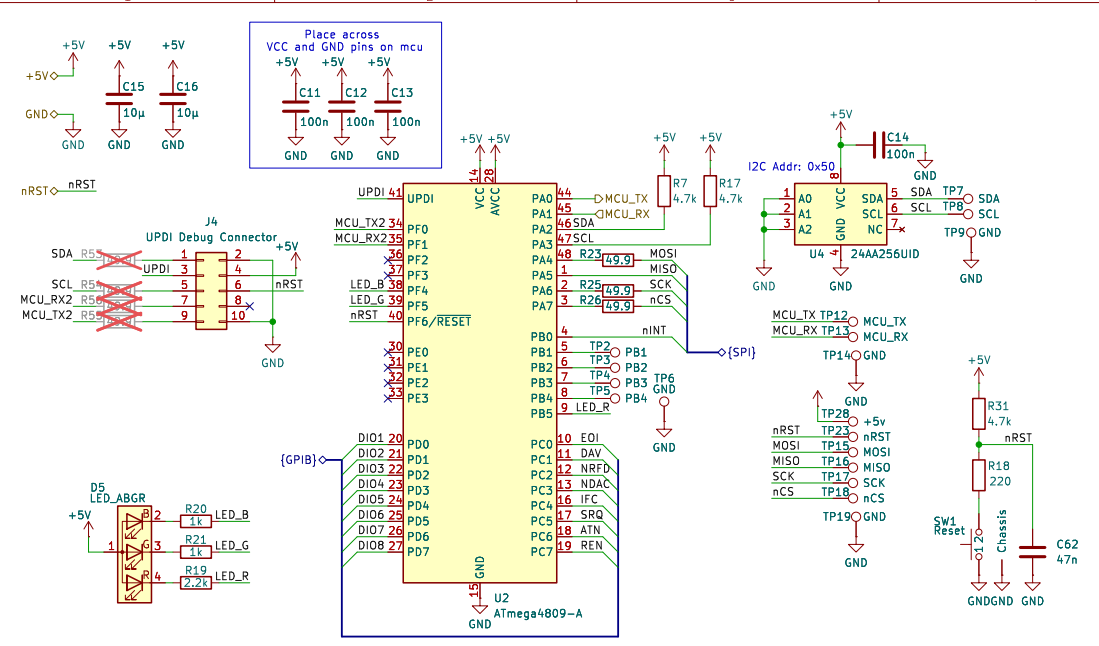
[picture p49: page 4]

I2C Addr: 0x50 Place across VCC and GND pins on mcu
10 +5V GND

4 SDA 5 SCL 6 NC 7 TP7 SDA

Id: 4/6 Title: Poe Ethernet GPIB Adapter File: MCU.kicad_sch Sheet: /MCU/ KOFOTRONIC

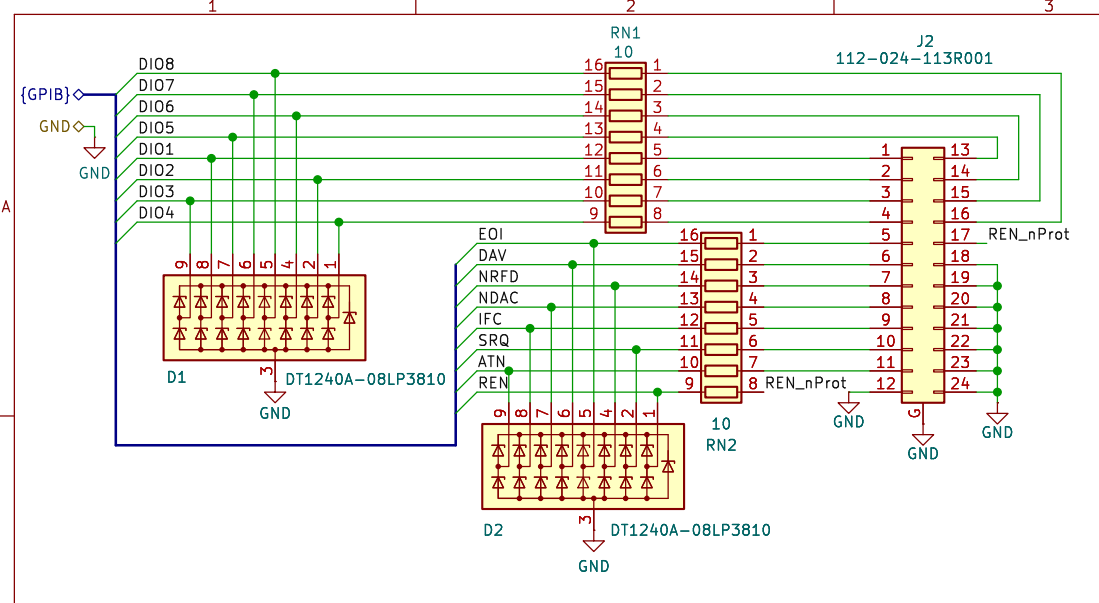
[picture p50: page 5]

2 2 | 14 14
3 3 | 15 15
4 4 | 16 16

Id: 5/6 Title: Poe Ethernet GPIB Adapter File: GPIB.kicad_sch Sheet: /GPIB/ KOFOTRONIC

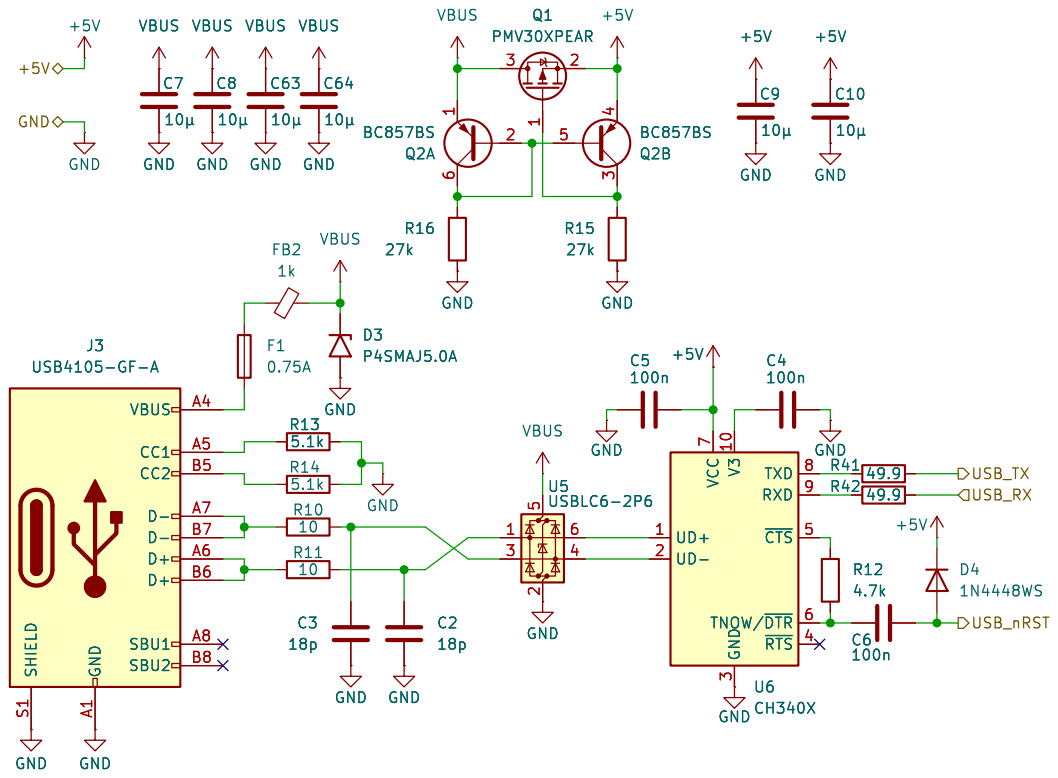
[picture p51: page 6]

3 TXD 8 RXD 9 ~{CTS}5 TNOW/~{DTR}6 ~{RTS}4 U6 CH340X GND

3 TXD 8 RXD 9 ~{CTS}5 TNOW/~{DTR}6 ~{RTS}4

Id: 6/6 Title: Poe Ethernet GPIB Adapter File: USB.kicad_sch Sheet: /USB/ KOFOTRONIC

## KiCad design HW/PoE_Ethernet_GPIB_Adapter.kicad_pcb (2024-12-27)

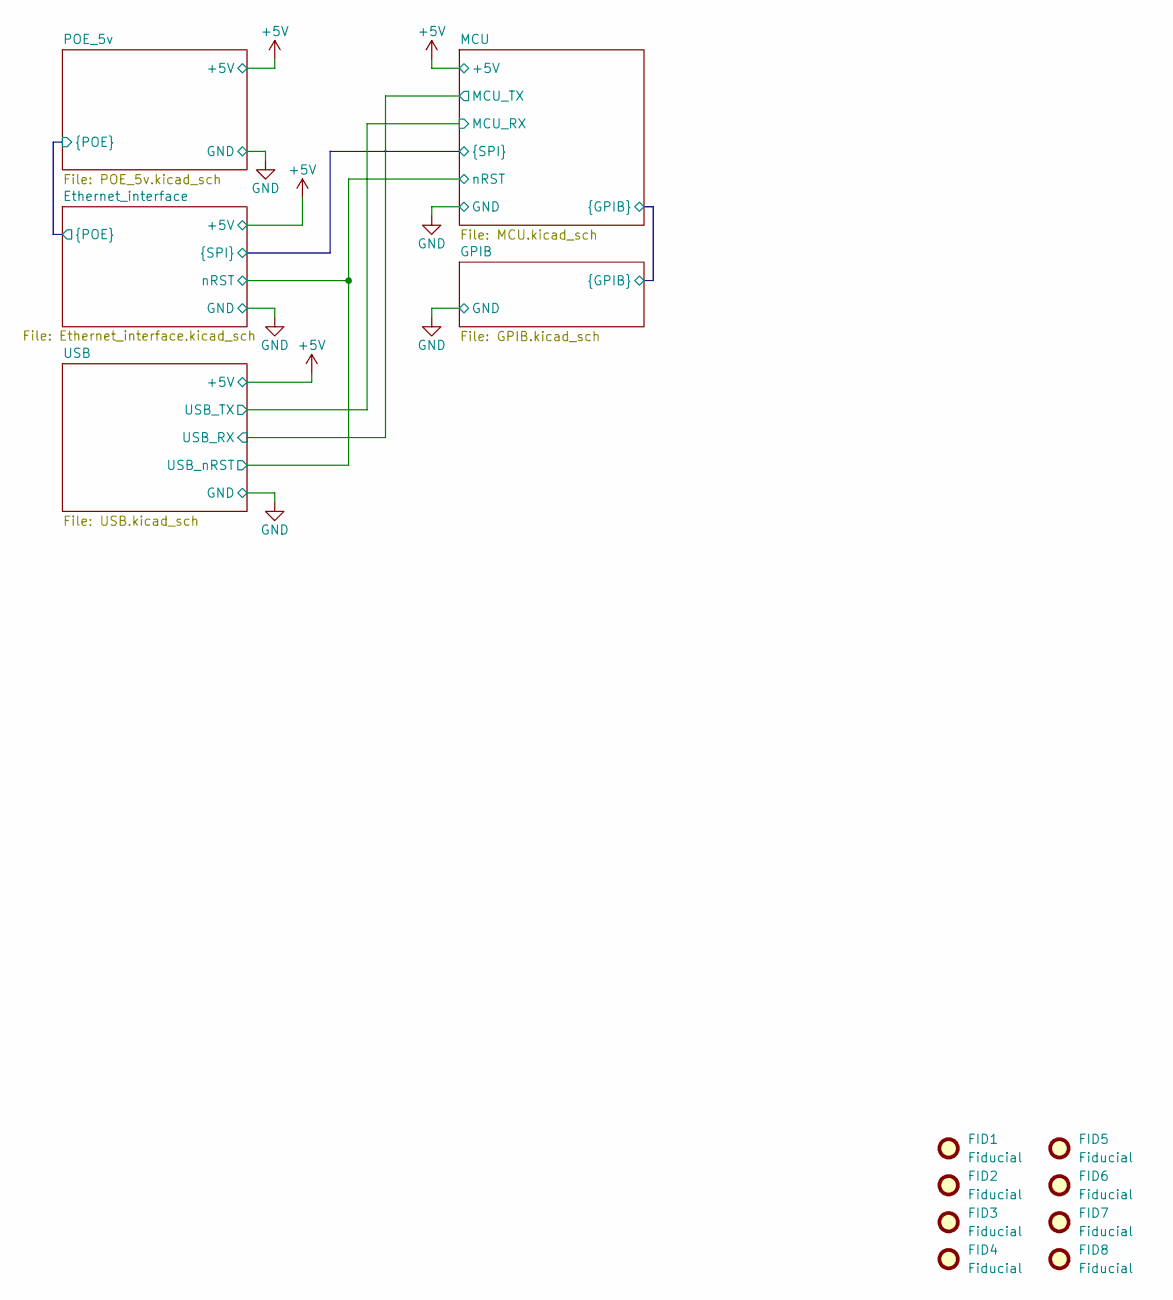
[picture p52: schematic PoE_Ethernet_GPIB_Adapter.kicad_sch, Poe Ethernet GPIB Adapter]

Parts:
FID1, FID2, FID3, FID4, FID5, FID6, FID7, FID8: Fiducial; Fiducial_0.75mm_Mask1.5mm

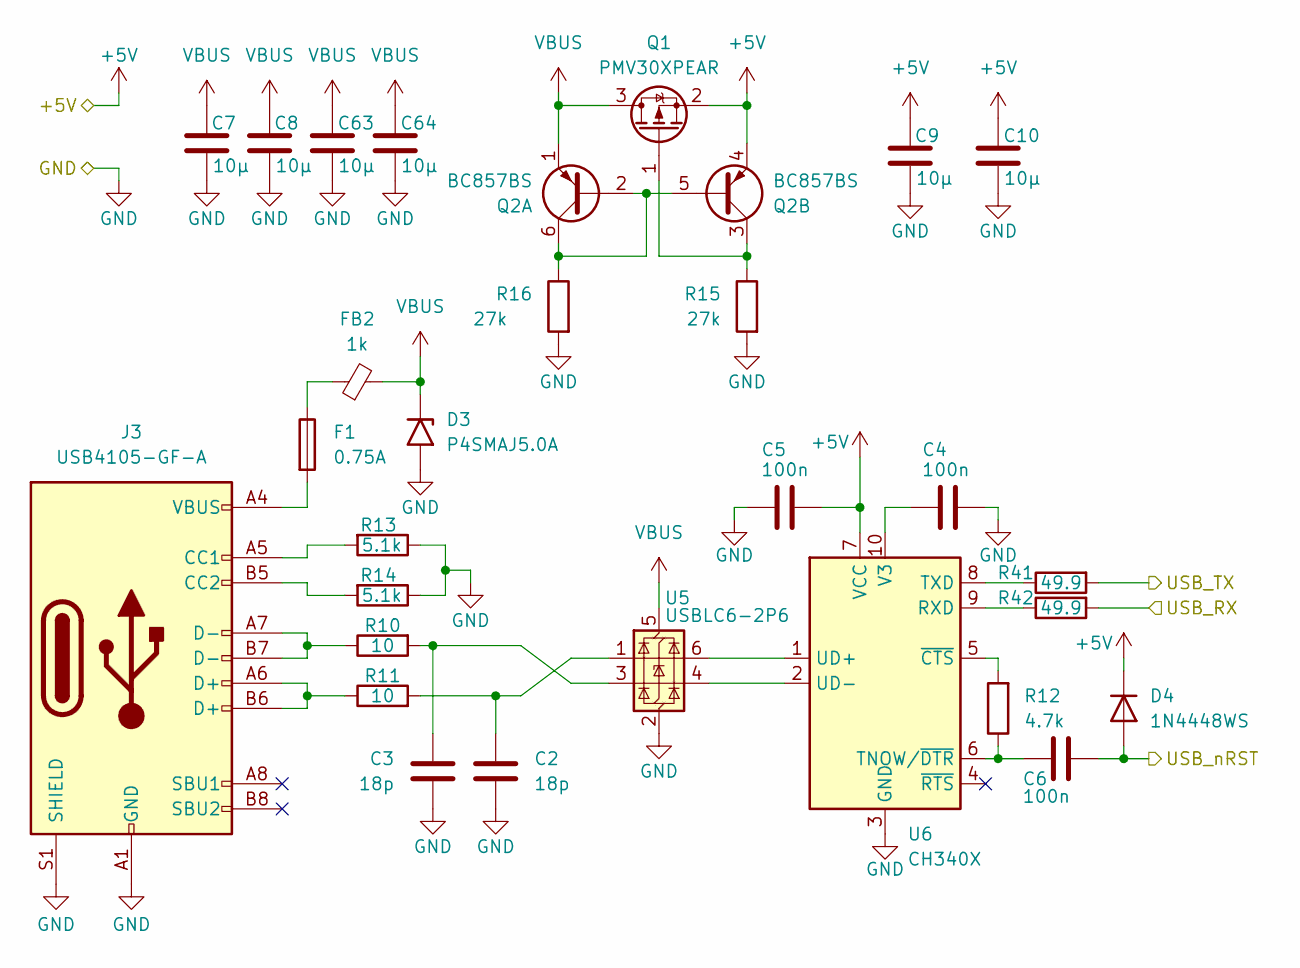
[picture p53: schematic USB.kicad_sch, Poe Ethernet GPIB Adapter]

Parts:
C2, C3: 18p; C_0402_1005Metric; JLCPCB C1549
C4, C5, C6: 100n; C_0402_1005Metric; JLCPCB C1525
C7, C8, C9, C10, C63, C64: 10µ; C_0402_1005Metric; JLCPCB C15525
D3: P4SMAJ5.0A; D_SMA; JLCPCB C391580
D4: 1N4448WS; D_SOD-323; JLCPCB C8602
F1: 0.75A; Fuse_1812_4532Metric; JLCPCB C3107
FB2: 1k; L_0805_2012Metric; JLCPCB C710395
J3: USB4105-GF-A; USB_C_Receptacle_GCT_USB4105-xx-A_16P_TopMnt_Horizontal; JLCPCB C3020560
Q1: PMV30XPEAR; SOT-23
Q2: BC857BS; SOT-363_SC-70-6
R10, R11: 10; R_0402_1005Metric
R12: 4.7k; R_0402_1005Metric
R13, R14: 5.1k; R_0402_1005Metric
R15, R16: 27k; R_0402_1005Metric
R41, R42: 49.9; R_0402_1005Metric
U5: USBLC6-2P6; SOT-666; JLCPCB C2827693
U6: CH340X; MSOP-10_3x3mm_P0.5mm; JLCPCB C3035748

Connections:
+5V: C5.2, C9.1, C10.1, D4.1 (K), Q1.2 (S), Q2.4 (E2), U6.7 (VCC); also elsewhere on the board
/Ethernet_interface/nRST: C6.2, D4.2 (A); also elsewhere on the board
/MCU/MCU_RX: R41.2; also elsewhere on the board
/MCU/MCU_TX: R42.2; also elsewhere on the board
GND: C2.2, C3.2, C4.2, C5.1, C7.2, C8.2, C9.2, C10.2, C63.2, C64.2, D3.2 (A2), J3.A1 (GND), J3.A12 (GND), J3.B1 (GND), J3.B12 (GND), J3.S1 (SHIELD), R13.1, R14.1, R15.2, R16.2, U5.2 (GND), U6.3 (GND); also elsewhere on the board
unnamed: C2.1, R11.2, U5.1 (I/O1)
unnamed: C3.1, R10.2, U5.3 (I/O2)
unnamed: F1.1, FB2.1
unnamed: F1.2, J3.A4 (VBUS), J3.A9 (VBUS), J3.B4 (VBUS), J3.B9 (VBUS)
unnamed: J3.A5 (CC1), R13.2
unnamed: J3.B5 (CC2), R14.2
unnamed: J3.A6 (D+), J3.B6 (D+), R11.1
unnamed: J3.A7 (D-), J3.B7 (D-), R10.1
unnamed: Q1.1 (G), Q2.3 (C2), R15.1
unnamed: Q2.2 (B1), Q2.5 (B2), Q2.6 (C1), R16.1
unnamed: R42.1, U6.9 (RXD)
unnamed: C6.1, R12.1, U6.6 (TNOW/~DTR)
unnamed: R41.1, U6.8 (TXD)
unnamed: U5.6 (I/O1), U6.1 (UD+)
unnamed: U5.4 (I/O2), U6.2 (UD-)
unnamed: C4.1, U6.10 (V3)
unnamed: R12.2, U6.5 (~CTS)
VBUS: C7.1, C8.1, C63.1, C64.1, D3.1 (A1), FB2.2, Q1.3 (D), Q2.1 (E1), U5.5 (VBUS)

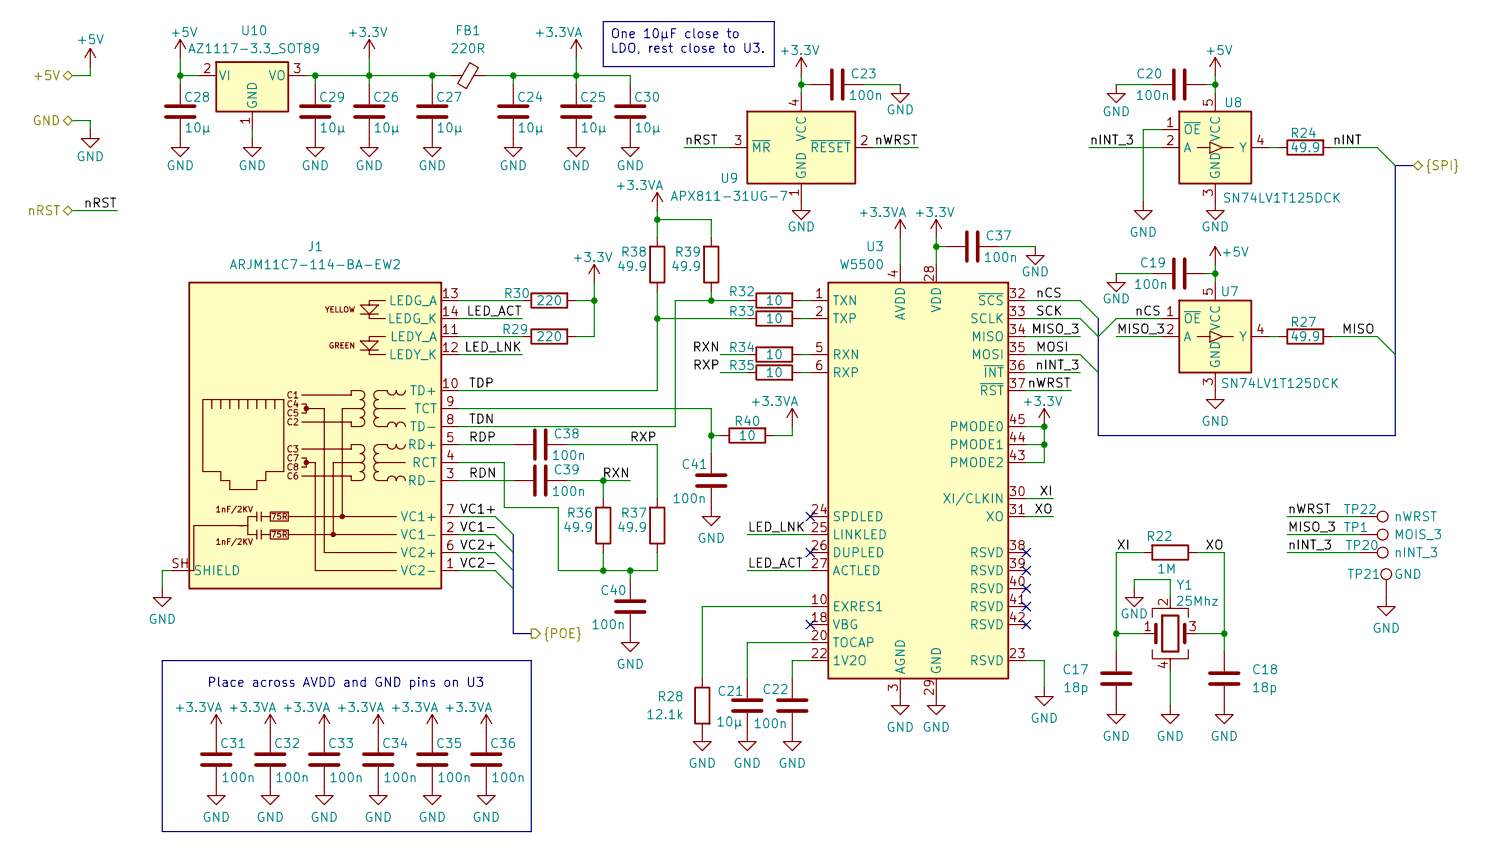
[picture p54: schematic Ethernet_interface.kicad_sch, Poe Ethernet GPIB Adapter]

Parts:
C17, C18: 18p; C_0402_1005Metric; JLCPCB C1549
C19, C20, C22, C23, C31, C32, C33, C34, C35, C36, C37, C38, C39, C40, C41: 100n; C_0402_1005Metric; JLCPCB C1525
C21, C24, C25, C26, C27, C28, C29, C30: 10µ; C_0402_1005Metric; JLCPCB C15525
FB1: 220R; L_0603_1608Metric; JLCPCB C139471
J1: ARJM11C7-114-BA-EW2; RJ45_ARJM11C7-114-BA-EW2
R22: 1M; R_0402_1005Metric
R24, R27, R36, R37, R38, R39: 49.9; R_0402_1005Metric
R28: 12.1k; R_0402_1005Metric
R29, R30: 220; R_0402_1005Metric
R32, R33, R34, R35, R40: 10; R_0402_1005Metric
TP1: MOIS_3; TestPoint_Pad_D1.0mm
TP20: nINT_3; TestPoint_Pad_D1.0mm
TP21: GND; TestPoint_Pad_D1.0mm
TP22: nWRST; TestPoint_Pad_D1.0mm
U3: W5500; LQFP-48_7x7mm_P0.5mm; JLCPCB C32843
U7, U8: SN74LV1T125DCK; SOT-353_SC-70-5; JLCPCB C2859742
U9: APX811-31UG-7; SOT-143; JLCPCB C150481
U10: AZ1117-3.3_SOT89; SOT-89-3; JLCPCB C362111
Y1: 25Mhz; Crystal_SMD_2520-4Pin_2.5x2.0mm; JLCPCB C5727305

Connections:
+3.3V: C23.2, C26.1, C27.1, C29.1, C37.2, FB1.1, R29.2, R30.2, U3.28 (VDD), U3.43 (PMODE2), U3.44 (PMODE1), U3.45 (PMODE0), U9.4 (VCC), U10.3 (VO)
+3.3VA: C24.1, C25.1, C30.1, C31.2, C32.2, C33.2, C34.2, C35.2, C36.2, FB1.2, R38.2, R39.2, R40.2, U3.4 (AVDD), U3.8 (AVDD), U3.11 (AVDD), U3.15 (AVDD), U3.17 (AVDD), U3.21 (AVDD)
+5V: C19.2, C20.2, C28.1, U7.5 (VCC), U8.5 (VCC), U10.2 (VI); also elsewhere on the board
/Ethernet_interface/LED_ACT: J1.14 (LEDG_K), U3.27 (ACTLED)
/Ethernet_interface/LED_LNK: J1.12 (LEDY_K), U3.25 (LINKLED)
/Ethernet_interface/MISO: R27.2; also elsewhere on the board
/Ethernet_interface/MISO_3: TP1.1, U3.34 (MISO), U7.2 (A)
/Ethernet_interface/MOSI: U3.35 (MOSI); also elsewhere on the board
/Ethernet_interface/RDN: C39.2, J1.3 (RD-)
/Ethernet_interface/RDP: C38.2, J1.5 (RD+)
/Ethernet_interface/RXN: C39.1, R34.1, R36.2
/Ethernet_interface/RXP: C38.1, R35.1, R37.2
/Ethernet_interface/SCK: U3.33 (SCLK); also elsewhere on the board
/Ethernet_interface/TDN: J1.8 (TD-), R32.1, R39.1
/Ethernet_interface/TDP: J1.10 (TD+), R33.1, R38.1
/Ethernet_interface/VC1+: J1.7 (VC1+); also elsewhere on the board
/Ethernet_interface/VC1-: J1.2 (VC1-); also elsewhere on the board
/Ethernet_interface/VC2+: J1.6 (VC2+); also elsewhere on the board
/Ethernet_interface/VC2-: J1.1 (VC2-); also elsewhere on the board
/Ethernet_interface/XI: C17.1, R22.2, U3.30 (XI/CLKIN), Y1.1
/Ethernet_interface/XO: C18.1, R22.1, U3.31 (XO), Y1.3
/Ethernet_interface/nCS: U3.32 (~SCS), U7.1 (~OE); also elsewhere on the board
/Ethernet_interface/nINT: R24.2; also elsewhere on the board
/Ethernet_interface/nINT_3: TP20.1, U3.36 (~INT), U8.2 (A)
/Ethernet_interface/nRST: U9.3 (~MR); also elsewhere on the board
/Ethernet_interface/nWRST: TP22.1, U3.37 (~RST), U9.2 (~RESET)
GND: C17.2, C18.2, C19.1, C20.1, C21.2, C22.1, C23.1, C24.2, C25.2, C26.2, C27.2, C28.2, C29.2, C30.2, C31.1, C32.1, C33.1, C34.1, C35.1, C36.1, C37.1, C40.1, C41.1, J1.SH (SHIELD), R28.2, TP21.1, U3.3 (AGND), U3.9 (AGND), U3.14 (AGND), U3.16 (AGND), U3.19 (AGND), U3.23 (RSVD), U3.29 (GND), U3.48 (AGND), U7.3 (GND), U8.1 (~OE), U8.3 (GND), U9.1 (GND), U10.1 (GND), Y1.2, Y1.4; also elsewhere on the board
unnamed: J1.13 (LEDG_A), R30.1
unnamed: J1.11 (LEDY_A), R29.1
unnamed: C40.2, J1.4 (RCT), R36.1, R37.1
unnamed: C41.2, J1.9 (TCT), R40.1
unnamed: C22.2, U3.22 (1V2O)
unnamed: R28.1, U3.10 (EXRES1)
unnamed: R34.2, U3.5 (RXN)
unnamed: R35.2, U3.6 (RXP)
unnamed: C21.1, U3.20 (TOCAP)
unnamed: R32.2, U3.1 (TXN)
unnamed: R33.2, U3.2 (TXP)
unnamed: R27.1, U7.4 (Y)
unnamed: R24.1, U8.4 (Y)

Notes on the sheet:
Place across AVDD and GND pins on U3
One 10µF close to LDO, rest close to U3.

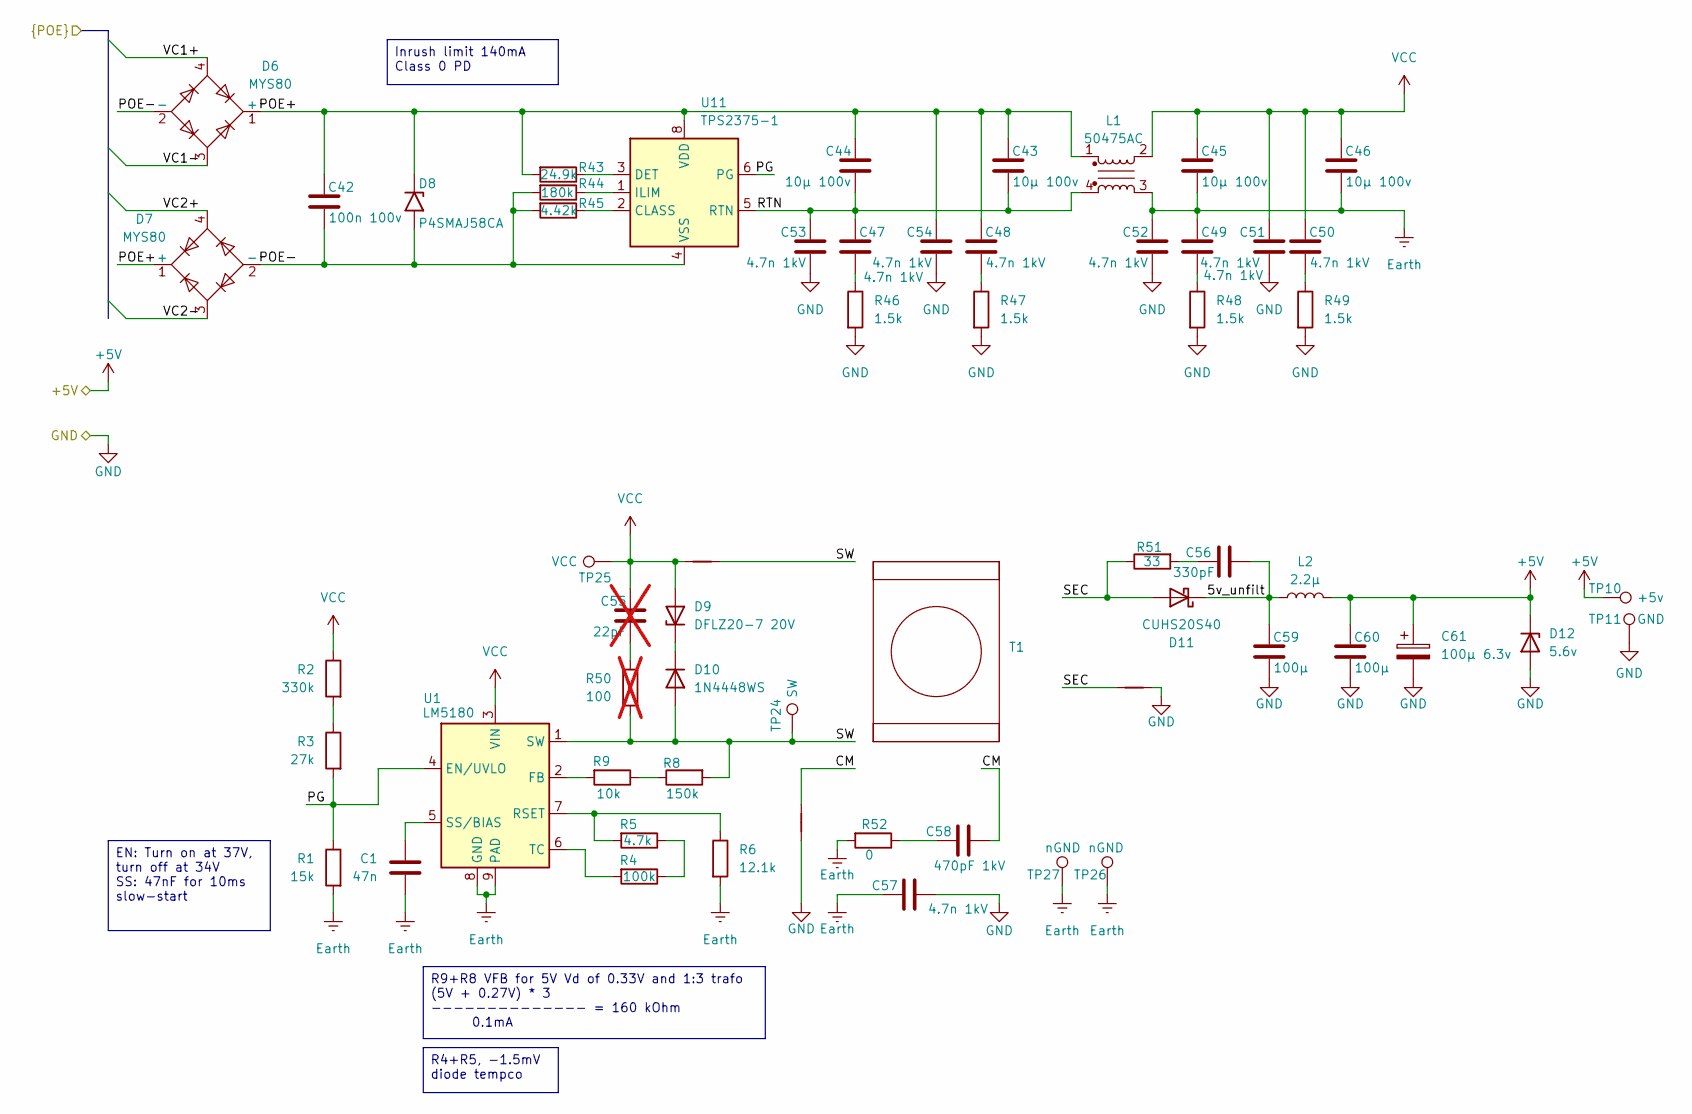
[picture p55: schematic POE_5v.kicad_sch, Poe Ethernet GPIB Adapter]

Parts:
C1: 47n; C_0402_1005Metric; JLCPCB C82219
C42: 100n 100v; C_0603_1608Metric; JLCPCB C15725
C43, C44, C45, C46: 10µ 100v; C_1210_3225Metric; JLCPCB C5156756
C47, C48, C49, C50, C51, C52, C53, C54, C57: 4.7n 1kV; C_0805_2012Metric; JLCPCB C565695
C55: 22pF; C_0603_1608Metric; not fitted
C56: 330pF; C_0603_1608Metric; JLCPCB C458879
C58: 470pF 1kV; C_0805_2012Metric; JLCPCB C20416464
C59, C60: 100µ; C_1206_3216Metric; JLCPCB CL31A107MQHNNNE
C61: 100µ 6.3v; CP_Elec_5x5.3; JLCPCB C5530352
D6, D7: MYS80; Diode_Bridge_Diotec_MicroDil_3.0x3.0x1.8mm; JLCPCB C3589669
D8: P4SMAJ58CA; D_SMA; JLCPCB C268635
D9: DFLZ20-7 20V; D_PowerDI-123; JLCPCB C177024
D10: 1N4448WS; D_SOD-323; JLCPCB C8602
D11: CUHS20S40; D_TUMD2; JLCPCB C3758140
D12: 5.6v; D_SOD-123F; JLCPCB C2119
L1: 50475AC; muRata_5000A
L2: 2.2µ; L_Taiyo-Yuden_NR-50xx
NT1, NT2: NetTie_2; NetTie-2_SMD_Pad0.5mm
NT3: NetTie_2; NetTie-2_SMD_Pad0.8mm
R1: 15k; R_0402_1005Metric
R2: 330k; R_0805_2012Metric
R3: 27k; R_0402_1005Metric
R4: 100k; R_0402_1005Metric
R5: 4.7k; R_0402_1005Metric
R6: 12.1k; R_0402_1005Metric
R8: 150k; R_0805_2012Metric
R9: 10k; R_0402_1005Metric
R43: 24.9k; R_0402_1005Metric
R44: 180k; R_0402_1005Metric
R45: 4.42k; R_0402_1005Metric
R46, R47, R48, R49: 1.5k; R_0603_1608Metric
R50: 100; R_0603_1608Metric; not fitted
R51: 33; R_0603_1608Metric
R52: 0; R_0603_1608Metric
T1: ER14_planar_4_to_1_48v_in_5v_out_5w
TP10: +5v; TestPoint_Pad_D1.0mm
TP11: GND; TestPoint_Pad_D1.0mm
TP24: SW; TestPoint_Pad_D1.0mm
TP25: VCC; TestPoint_Pad_D1.0mm
TP26, TP27: nGND; TestPoint_Pad_D1.0mm
U1: LM5180; WSON-8-1EP_4x4mm_P0.8mm_EP1.98x3mm; JLCPCB C2868878
U11: TPS2375-1; TSSOP-8_4.4x3mm_P0.65mm; JLCPCB C2859774

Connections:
+5V: C60.1, C61.1, D12.1 (K), L2.2, TP10.1; also elsewhere on the board
/Ethernet_interface/VC1+: D6.4; also elsewhere on the board
/Ethernet_interface/VC1-: D6.3; also elsewhere on the board
/Ethernet_interface/VC2+: D7.4; also elsewhere on the board
/Ethernet_interface/VC2-: D7.3; also elsewhere on the board
/POE_5v/5v_unfilt: C56.2, C59.1, D11.1 (K), L2.1
/POE_5v/CM: C58.1, NT2.2
/POE_5v/PG: R1.1, R3.2, U1.4 (EN/UVLO), U11.6 (PG)
/POE_5v/POE+: C42.1, C43.1, C44.1, C48.1, C54.1, D6.1 (+), D7.1 (+), D8.1 (A1), L1.1, R43.2, U11.8 (VDD)
/POE_5v/POE-: C42.2, D6.2 (-), D7.2 (-), D8.2 (A2), R44.2, R45.2, U11.4 (VSS)
/POE_5v/RTN: C43.2, C44.2, C47.1, C53.1, L1.4, U11.5 (RTN)
/POE_5v/SEC: D11.2 (A), NT3.1, R51.1
/POE_5v/SW: D10.2 (A), NT1.2, R8.2, R50.2, TP24.1, U1.1 (SW)
Earth: C1.2, C45.2, C46.2, C49.1, C52.1, C57.2, L1.3, R1.2, R6.2, R52.2, TP26.1, TP27.1, U1.8 (GND), U1.9 (PAD)
GND: C51.2, C52.2, C53.2, C54.2, C57.1, C59.2, C60.2, C61.2, D12.2 (A), NT2.1, NT3.2, R46.2, R47.2, R48.2, R49.2, TP11.1; also elsewhere on the board
unnamed: C47.2, R46.1
unnamed: C48.2, R47.1
unnamed: C49.2, R48.1
unnamed: C50.2, R49.1
unnamed: C55.2, R50.1
unnamed: C56.1, R51.2
unnamed: C58.2, R52.1
unnamed: D9.1 (K), D10.1 (K)
unnamed: R2.2, R3.1
unnamed: R4.1, R5.1
unnamed: R8.1, R9.1
unnamed: R9.2, U1.2 (FB)
unnamed: R5.2, R6.1, U1.7 (RSET)
unnamed: C1.1, U1.5 (SS/BIAS)
unnamed: R4.2, U1.6 (TC)
unnamed: R45.1, U11.2 (CLASS)
unnamed: R43.1, U11.3 (DET)
unnamed: R44.1, U11.1 (ILIM)
VCC: C45.1, C46.1, C50.1, C51.1, C55.1, D9.2 (A), L1.2, NT1.1, R2.1, TP25.1, U1.3 (VIN)

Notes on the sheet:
R9+R8 VFB for 5V Vd of 0.33V and 1:3 trafo (5V + 0.27V) * 3 -------------- = 160 kOhm 0.1mA
R4+R5, -1.5mV diode tempco
EN: Turn on at 37V, turn off at 34V SS: 47nF for 10ms slow-start
Inrush limit 140mA Class 0 PD

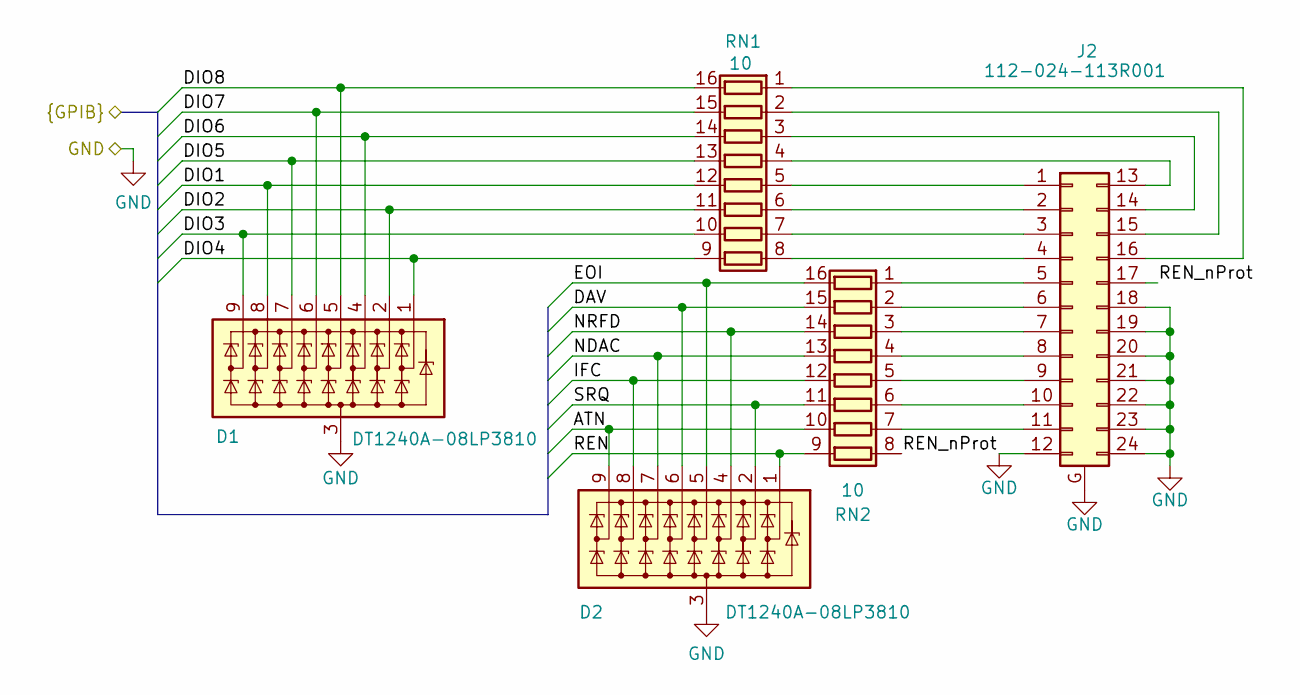
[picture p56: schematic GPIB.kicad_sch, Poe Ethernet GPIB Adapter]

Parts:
D1, D2: DT1240A-08LP3810; UDFN-9_1.0x3.8mm_P0.5mm; JLCPCB C526598
J2: 112-024-113R001
RN1, RN2: 10; R_Array_Convex_8x0602; JLCPCB C1518172

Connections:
/GPIB/ATN: D2.9 (K8), RN2.10 (R7.2); also elsewhere on the board
/GPIB/DAV: D2.6 (K5), RN2.15 (R2.2); also elsewhere on the board
/GPIB/DIO1: D1.8 (K7), RN1.12 (R5.2); also elsewhere on the board
/GPIB/DIO2: D1.2 (K2), RN1.11 (R6.2); also elsewhere on the board
/GPIB/DIO3: D1.9 (K8), RN1.10 (R7.2); also elsewhere on the board
/GPIB/DIO4: D1.1 (K1), RN1.9 (R8.2); also elsewhere on the board
/GPIB/DIO5: D1.7 (K6), RN1.13 (R4.2); also elsewhere on the board
/GPIB/DIO6: D1.4 (K3), RN1.14 (R3.2); also elsewhere on the board
/GPIB/DIO7: D1.6 (K5), RN1.15 (R2.2); also elsewhere on the board
/GPIB/DIO8: D1.5 (K4), RN1.16 (R1.2); also elsewhere on the board
/GPIB/EOI: D2.5 (K4), RN2.16 (R1.2); also elsewhere on the board
/GPIB/IFC: D2.8 (K7), RN2.12 (R5.2); also elsewhere on the board
/GPIB/NDAC: D2.7 (K6), RN2.13 (R4.2); also elsewhere on the board
/GPIB/NRFD: D2.4 (K3), RN2.14 (R3.2); also elsewhere on the board
/GPIB/REN: D2.1 (K1), RN2.9 (R8.2); also elsewhere on the board
/GPIB/REN_nProt: J2.17, RN2.8 (R8.1)
/GPIB/SRQ: D2.2 (K2), RN2.11 (R6.2); also elsewhere on the board
GND: D1.3 (A), D2.3 (A), J2.12, J2.18, J2.19, J2.20, J2.21, J2.22, J2.23, J2.24, J2.G (Chassis); also elsewhere on the board
unnamed: J2.1, RN1.5 (R5.1)
unnamed: J2.2, RN1.6 (R6.1)
unnamed: J2.3, RN1.7 (R7.1)
unnamed: J2.4, RN1.8 (R8.1)
unnamed: J2.5, RN2.1 (R1.1)
unnamed: J2.6, RN2.2 (R2.1)
unnamed: J2.7, RN2.3 (R3.1)
unnamed: J2.8, RN2.4 (R4.1)
unnamed: J2.9, RN2.5 (R5.1)
unnamed: J2.10, RN2.6 (R6.1)
unnamed: J2.11, RN2.7 (R7.1)
unnamed: J2.13, RN1.4 (R4.1)
unnamed: J2.14, RN1.3 (R3.1)
unnamed: J2.15, RN1.2 (R2.1)
unnamed: J2.16, RN1.1 (R1.1)

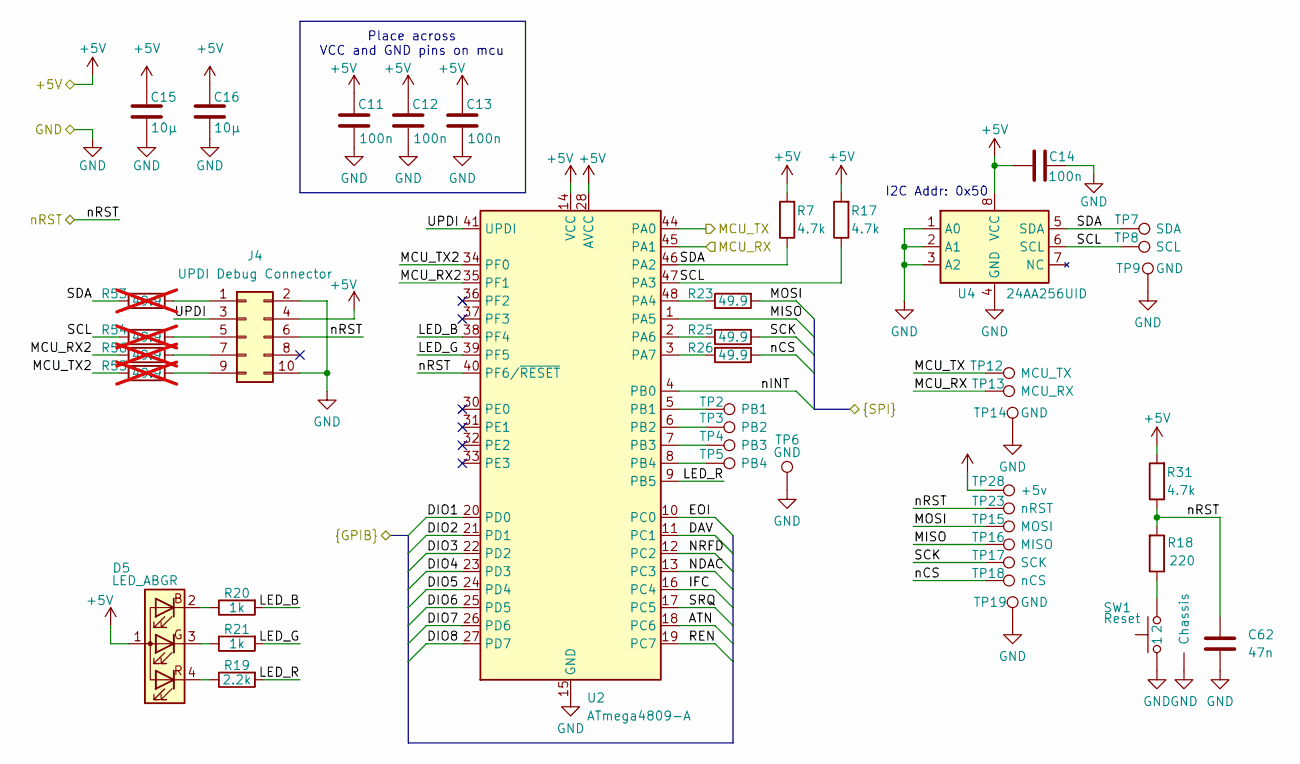
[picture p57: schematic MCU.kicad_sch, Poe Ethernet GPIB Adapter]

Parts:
C11, C12, C13, C14: 100n; C_0402_1005Metric; JLCPCB C1525
C15, C16: 10µ; C_0402_1005Metric; JLCPCB C15525
C62: 47n; C_0402_1005Metric; JLCPCB C82219
D5: LED_ABGR; LED_RGB_Everlight_EASV3015RGBA0_Horizontal; JLCPCB C5365900
J4: UPDI Debug Connector; PinHeader_2x05_P1.27mm_Vertical
R7, R17, R31: 4.7k; R_0402_1005Metric
R18: 220; R_0402_1005Metric
R19: 2.2k; R_0402_1005Metric
R20, R21: 1k; R_0402_1005Metric
R23, R25, R26: 49.9; R_0402_1005Metric
R53, R54, R55, R56: 49.9; R_0402_1005Metric; not fitted
SW1: Reset; SW_Tactile_SKHH_Angled
TP2: PB1; TestPoint_Pad_D1.0mm
TP3: PB2; TestPoint_Pad_D1.0mm
TP4: PB3; TestPoint_Pad_D1.0mm
TP5: PB4; TestPoint_Pad_D1.0mm
TP6, TP9, TP14, TP19: GND; TestPoint_Pad_D1.0mm
TP7: SDA; TestPoint_Pad_D1.0mm
TP8: SCL; TestPoint_Pad_D1.0mm
TP12: MCU_TX; TestPoint_Pad_D1.0mm
TP13: MCU_RX; TestPoint_Pad_D1.0mm
TP15: MOSI; TestPoint_Pad_D1.0mm
TP16: MISO; TestPoint_Pad_D1.0mm
TP17: SCK; TestPoint_Pad_D1.0mm
TP18: nCS; TestPoint_Pad_D1.0mm
TP23: nRST; TestPoint_Pad_D1.0mm
TP28: +5v; TestPoint_Pad_D1.0mm
U2: ATmega4809-A; TQFP-48_7x7mm_P0.5mm; JLCPCB C1340041
U4: 24AA256UID; SOIC-8_3.9x4.9mm_P1.27mm; JLCPCB C1349800

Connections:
+5V: C11.2, C12.2, C13.2, C14.1, C15.1, C16.1, D5.1 (A), J4.4, R7.2, R17.2, R31.2, TP28.1, U2.14 (VCC), U2.28 (AVCC), U2.42 (VCC), U4.8 (VCC); also elsewhere on the board
/Ethernet_interface/MISO: TP16.1, U2.1 (PA5); also elsewhere on the board
/Ethernet_interface/MOSI: R23.2, TP15.1; also elsewhere on the board
/Ethernet_interface/SCK: R25.2, TP17.1; also elsewhere on the board
/Ethernet_interface/nCS: R26.2, TP18.1; also elsewhere on the board
/Ethernet_interface/nINT: U2.4 (PB0); also elsewhere on the board
/Ethernet_interface/nRST: C62.1, J4.6, R18.2, R31.1, TP23.1, U2.40 (PF6/~RESET); also elsewhere on the board
/GPIB/ATN: U2.18 (PC6); also elsewhere on the board
/GPIB/DAV: U2.11 (PC1); also elsewhere on the board
/GPIB/DIO1: U2.20 (PD0); also elsewhere on the board
/GPIB/DIO2: U2.21 (PD1); also elsewhere on the board
/GPIB/DIO3: U2.22 (PD2); also elsewhere on the board
/GPIB/DIO4: U2.23 (PD3); also elsewhere on the board
/GPIB/DIO5: U2.24 (PD4); also elsewhere on the board
/GPIB/DIO6: U2.25 (PD5); also elsewhere on the board
/GPIB/DIO7: U2.26 (PD6); also elsewhere on the board
/GPIB/DIO8: U2.27 (PD7); also elsewhere on the board
/GPIB/EOI: U2.10 (PC0); also elsewhere on the board
/GPIB/IFC: U2.16 (PC4); also elsewhere on the board
/GPIB/NDAC: U2.13 (PC3); also elsewhere on the board
/GPIB/NRFD: U2.12 (PC2); also elsewhere on the board
/GPIB/REN: U2.19 (PC7); also elsewhere on the board
/GPIB/SRQ: U2.17 (PC5); also elsewhere on the board
/MCU/LED_B: R20.2, U2.38 (PF4)
/MCU/LED_G: R21.2, U2.39 (PF5)
/MCU/LED_R: R19.2, U2.9 (PB5)
/MCU/MCU_RX: TP13.1, U2.45 (PA1); also elsewhere on the board
/MCU/MCU_RX2: R56.1, U2.35 (PF1)
/MCU/MCU_TX: TP12.1, U2.44 (PA0); also elsewhere on the board
/MCU/MCU_TX2: R55.1, U2.34 (PF0)
/MCU/SCL: R17.1, R54.1, TP8.1, U2.47 (PA3), U4.6 (SCL)
/MCU/SDA: R7.1, R53.1, TP7.1, U2.46 (PA2), U4.5 (SDA)
/MCU/UPDI: J4.3, U2.41 (UPDI)
GND: C11.1, C12.1, C13.1, C14.2, C15.2, C16.2, C62.2, J4.2, J4.10, SW1.1, SW1.G (Chassis), TP6.1, TP9.1, TP14.1, TP19.1, U2.15 (GND), U2.29 (GND), U2.43 (GND), U4.1 (A0), U4.2 (A1), U4.3 (A2), U4.4 (GND); also elsewhere on the board
unnamed: D5.2 (BK), R20.1
unnamed: D5.3 (GK), R21.1
unnamed: D5.4 (RK), R19.1
unnamed: J4.1, R53.2
unnamed: J4.5, R54.2
unnamed: J4.7, R56.2
unnamed: J4.9, R55.2
unnamed: R18.1, SW1.2
unnamed: R23.1, U2.48 (PA4)
unnamed: R25.1, U2.2 (PA6)
unnamed: R26.1, U2.3 (PA7)
unnamed: TP2.1, U2.5 (PB1)
unnamed: TP3.1, U2.6 (PB2)
unnamed: TP4.1, U2.7 (PB3)
unnamed: TP5.1, U2.8 (PB4)

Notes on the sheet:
I2C Addr: 0x50
Place across VCC and GND pins on mcu

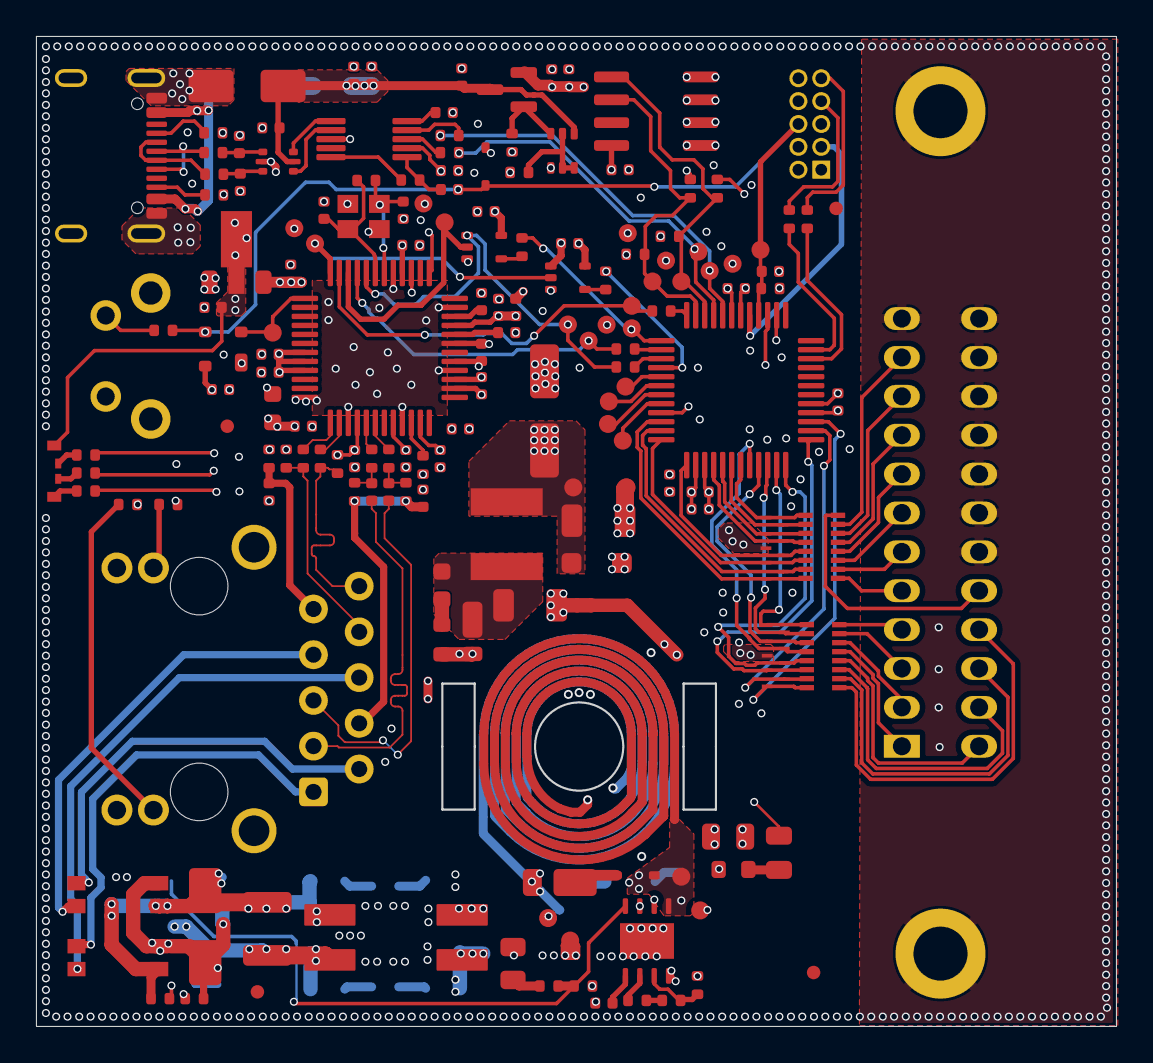
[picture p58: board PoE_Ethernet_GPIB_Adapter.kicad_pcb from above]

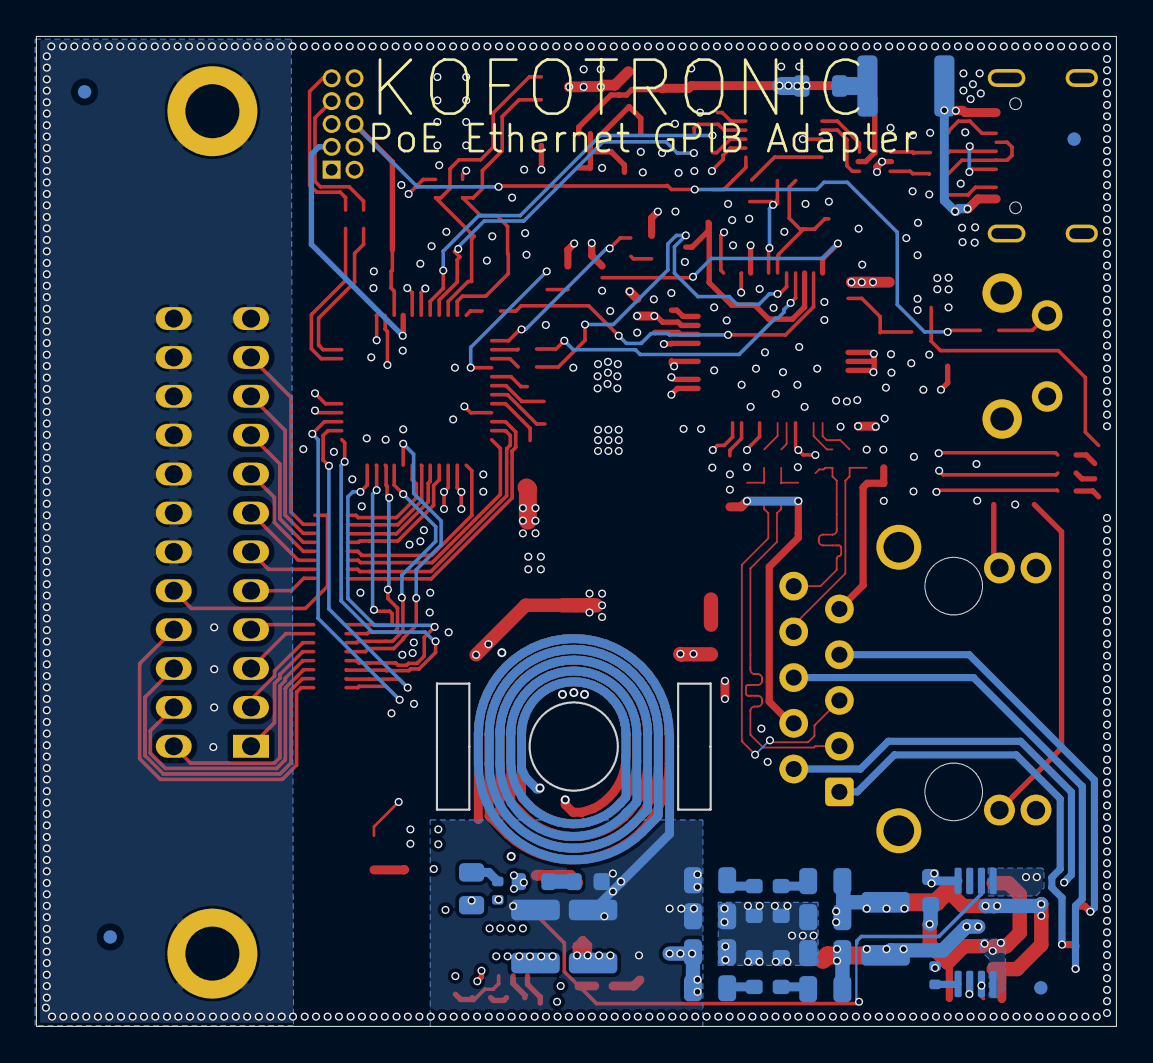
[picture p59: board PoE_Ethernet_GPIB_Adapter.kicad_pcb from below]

Board: 6 copper layers, 60.0 x 55.0 mm, 198 parts (29 on the bottom side), 143 nets.

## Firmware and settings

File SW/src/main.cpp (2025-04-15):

// #pragma GCC diagnostic push
// #pragma GCC diagnostic ignored "-Wtype-limits"
// #pragma GCC diagnostic ignored "-Wunused-variable"

// This is the entry point to the device.
// The device can either function as a VXI11.2 server, either as a prologix server. (sorry, cannot run both due to lack of ROM)

// You can choose which type you want by defining INTERFACE_PROLOGIX or INTERFACE_VXI11 in the config.h file.
// By default, INTERFACE_VXI11 is defined, so you will get a VXI-11 server.
// For PROLOGIX you must define INTERFACE_PROLOGIX in the config.h file or at compile time via -DINTERFACE_PROLOGIX.
// Doing so will disable the VXI-11 server and enable the Prologix server.
// If you define both, then the compiler will complain about not enough ROM space.
// It could however work, provided you have enough ROM space.

// For the explanation of the prologix server, see prologix_server.cpp and the AR488 documentation.

// For VXI-11.2: 
//
// Example of connection string:
//
// 'normal' vxi-11: TCPIP::192.168.1.105::INSTR           implies inst0, see below
//                  TCPIP::192.168.1.105::instN::INSTR    
//  VXI-11.2        TCPIP::192.168.1.105::gpibN,A::INSTR  (or hpibN) A is gpib bus primary address. 0 reserved for the controller
// in all cases, N = interface number. Default is 0. When 0, it can be omitted
//
// VXI-11 Requires 3 servers:
// * 2 port mappers on UDP and TCP that point to the VXI-11 RPC server
// * 1 VXI-11 RPC server. VXI-11 consists of 3 separate RPC programs with the numeric identifiers: 0x0607AF (DEVICE_CORE), 0x0607B0 (DEVICE_ASYNC) and 0x0607B1 (DEVICE_INTR).
// * you may also publish the service presence via mDNS, but this is not required.
//
// For compatibility with basic pyvisa use, you only need DEVICE_CORE, but the guidelines say you should also support the other RPC programs.
//
// While in theory one could re-use an existing VXI-11 RPC server socket for multiple connections, 
// pyvisa requires 1 RPC client socket per device. It doesn't just use create_link on the same socket with a different device name.
//
// VXI-11 works this way:
// * a request for an open port is sent to the port mapper (in UDP or TCP), which returns a port number.
// * the client then connects to the RPC server on that port, with a CREATE_LINK request and device to connect to (inst0, gpib,2 etc). 
// * the RPC server checks if there are resources available and if so, replies to the client with a link ID.
// * the client then uses that port and link ID for DEVICE_WRITE and DEVICE_READ operations
// * when done, the client sends a DESTROY_LINK command to the RPC server, which will close the link and closes the socket.
//
// The link ID is used to map with the device address

#ifdef __AVR__
#include <avr/wdt.h>
#endif

// #pragma GCC diagnostic pop

#include "config.h"
#include "AR488_Config.h"
#include "AR488_GPIBbus.h"
#include "AR488_ComPorts.h"
#include <Ethernet.h>

#include "24AA256UID.h"
#include "user_interface.h"
#ifdef INTERFACE_VXI11
#include "rpc_bind_server.h"
#include "vxi_server.h"
#endif
// The following file is needed for the gpib setup, even if you do not use prologix. 
// This is done there because the code is not trivial and maintenance is easier this way, as upstream code mixes gpib and prologix.
#include "prologix_server.h"

/****** Global variables with volatile values related to controller state *****/

// External EEPROM with MAC and unique ID.
_24AA256UID eeprom(0x50, true);

// GPIB bus object
extern GPIBbus gpibBus;

#ifdef INTERFACE_VXI11

#pragma region SCPI handler

// #define DUMMY_DEVICE

/**
 * @brief a helper class to capture data printed by receiveData (using Stream.write(uint8_t ch)) to an external buffer
 */
class bufStream : public Stream {
   public:
    bufStream(char *buf, size_t size) : buffer(buf), bufferSize(size) {}

    size_t write(uint8_t ch) override {
        // debugPort.print((char)ch);
        if (buffer_pos < bufferSize) {
            buffer[buffer_pos++] = ch;
            return 1;
        }
        return 0;
    }

    int available() { return 0; }  // dummy
    int read() { return 0; }       // dummy
    int peek() { return 0; }       // dummy

    size_t len(void) { return buffer_pos; }

    void flush() {
        buffer_pos = 0;  // clear the buffer
    }

   private:
    char *buffer;
    size_t bufferSize;
    size_t buffer_pos = 0;
};

/**
 * @brief SCPI handler interface
 *
 * This class handles the communication between the VXI servers and the SCPI parser or the devices.
 */
class SCPI_handler : public SCPI_handler_interface {
   public:
    SCPI_handler() {}

    void write(int address, const char *data, size_t len) override {
#ifdef DUMMY_DEVICE
        debugPort.print(F("SCPI write: "));
        printBuf(data, len);
#else
        if (address == 0) {
            // maybe we need to address a device directly on the bus
            address = gpibBus.cfg.caddr;
        }
        if (address == 0) return; // if controller: no writing to the bus

        // Send data to the GPIB bus
        gpibBus.cfg.paddr = address;
        gpibBus.cfg.saddr = 0xFF;  // secondary address is not used
        if (!gpibBus.haveAddressedDevice()) gpibBus.addressDevice(address, 0xFF, TOLISTEN);
        gpibBus.sendData(data, len);
        gpibBus.unAddressDevice();
#endif
    }

    bool read(int address, char *data, size_t *len, size_t max_len) override {
#ifdef DUMMY_DEVICE
        // Simulate a device response
        memset(data, 0, max_len);
        *len = snprintf(data, max_len, "SCPI response");
        return true;
#else
        if (address == 0) {
            // maybe we need to address a device directly on the bus
            address = gpibBus.cfg.caddr;
        }
        // dummy reply if I am addressed
        if (address == 0) {
            strncpy(data, DEVICE_NAME, max_len);
            *len = strlen(data);
            return true;  // no address
        }
        bufStream buf = bufStream(data, max_len);  ///< Buffer stream for incoming data

        bool readWithEoi = true;
        bool detectEndByte = false;
        uint8_t endByte = 0;

        gpibBus.cfg.paddr = address;
        gpibBus.cfg.saddr = 0xFF;  // secondary address is not used
        gpibBus.addressDevice(address, 0xFF, TOTALK);     // tel device 'paddr' to talk. If you do this and the device has nothing to say, you might get an error.
        gpibBus.receiveData(buf, readWithEoi, detectEndByte, endByte);  // get the data from the bus and send out
        gpibBus.unAddressDevice();
        *len = buf.len();
        return true;
#endif
    }

    bool claim_control() override {
        // not needed for the GPIB bus, is done differently
        return true;
    }
    void release_control() override {
        // not needed for the GPIB bus, is done differently
    }

};

#pragma endregion

#pragma region VXI related Socket servers and helpers

static SCPI_handler scpi_handler;                    ///< The bridge from the vxi server to the SCPI command handler
static VXI_Server vxi_server(scpi_handler);          ///< The vxi server
static RPC_Bind_Server rpc_bind_server(vxi_server);  ///< The RPC_Bind_Server for the vxi server

#pragma endregion

#endif  // INTERFACE_VXI11


#pragma region Setup and loop functions

/**
 * @brief Setup function
 *
 * This function is called once at startup. It initializes the LED, serial port, and Ethernet connection.
 * It also sets up the EEPROM and GPIB bus configuration. The function tries to wait for DHCP to assign an IP address.
 */
void setup() {
    setup_serial_ui_and_led(F(DEVICE_NAME));

    // Disable the watchdog (needed to prevent WDT reset loop)
#ifdef __AVR__
    wdt_disable();
#endif

    eeprom.begin();
    uint8_t macAddress[6];
    eeprom.getMACAddress(macAddress);

    debugPort.print(F("MAC Address: "));
    printHexArray(macAddress, 6);

    // Configure and start GPIB interface
    debugPort.println(F("Configuring and Starting GPIB bus..."));
    setup_gpibBusConfig();

    // Initialise dataport, serial or ethernet as defined
#ifdef AR488_GPIBconf_EXTEND
    uint8_t *ipbuff = gpibBus.cfg.ip;
#else    
    uint8_t ipbuff[4];  
    eeprom.getIPAddress(ipbuff);
    gpibBus.cfg.caddr = eeprom.getDefaultInstrument();
#endif
    if (gpibBus.cfg.caddr != 0) {
        if (gpibBus.cfg.caddr > 30) {
            gpibBus.cfg.caddr = 0;
        }
        debugPort.print(F("The devices's default address points to GPIB address "));
        debugPort.println(gpibBus.cfg.caddr);
    }
    // Set up the IP address    
    IPAddress ip = IPAddress(ipbuff);
    Ethernet.init(7);
    if (ip == IPAddress(0, 0, 0, 0)) {
        debugPort.println(F("Waiting for DHCP..."));
        Ethernet.begin(macAddress);
    } else {
        // Use static IP
        // debugPort.print(F("Using IP address "));
        // debugPort.println(ip);
        Ethernet.begin(macAddress, ip);
    }

    // print the IP address
    setup_ipaddress_surveillance_and_show_address();
    // for now, just ignore if we have a good address via FHCP

    // This would be the place to add mdns, but none of the main mdns libraries support the present ethernet library
#ifdef INTERFACE_VXI11
    debugPort.println(F("Starting VXI-11 TCP server..."));
    vxi_server.begin(VXI11_PORT, LOG_VXI_DETAILS);

    debugPort.println(F("Starting VXI-11 port mappers on TCP and UDP..."));
    rpc_bind_server.begin(LOG_VXI_DETAILS);
    debugPort.println(F("VXI-11 servers started"));
#endif


#ifdef INTERFACE_PROLOGIX
#define STR_HELPER(x) #x
#define STR(x) STR_HELPER(x)

    debugPort.println(F("Starting Prologix TCP server on port " STR(PROLOGIX_PORT) "..."));
    // delay(1000);  // wait for message to be printed
    setup_prologix();
#endif
    end_of_setup();
}

/***** ARDUINO MAIN LOOP *****/

/**
 * @brief This is the main loop.
 */
void loop() {
    int nr_connections = 0;

#ifdef INTERFACE_VXI11
    rpc_bind_server.loop();
    nr_connections += vxi_server.loop();
#endif
#ifdef INTERFACE_PROLOGIX    
    nr_connections += loop_prologix();
#endif

    // TODO: if these 2 were not mutually exclusive, we should separate the counters and give them individually to the UI
    loop_serial_ui_and_led(nr_connections);
}
#pragma endregion

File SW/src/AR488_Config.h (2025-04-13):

#ifndef AR488_CONFIG_H
#define AR488_CONFIG_H

/*********************************************/
/***** AR488 GLOBAL CONFIGURATION HEADER *****/
/***** vvvvvvvvvvvvvvvvvvvvvvvvvvvvvvvvv *****/


/***** Firmware version *****/
#define FWVER "AR488 GPIB controller, ver. 0.53.03, 08/04/2025"


/***** BOARD CONFIGURATION *****/
/*
 * Platform will be selected automatically based on 
 * Arduino definition.
 * Only ONE board/layout should be selected per platform
 * Only ONE Serial port can be used to receive output
 */


/*** Custom layout ***/
/*
 * Uncomment to use custom board layout
 */
#define AR488_CUSTOM

/*
 * Configure the appropriate board/layout section
 * below as required
*/
#ifdef AR488_CUSTOM

#include "config.h"
  
/*** UNO and NANO boards ***/
#elif __AVR_ATmega328P__
  /* Board/layout selection */
  #define AR488_UNO
  //#define AR488_NANO
  //#define AR488_MCP23S17

/*** MEGA 32U4 based boards (Micro, Leonardo) ***/
#elif __AVR_ATmega32U4__
  /*** Board/layout selection ***/
  #define AR488_MEGA32U4_MICRO  // Artag's design for Micro board
  //#define AR488_MEGA32U4_LR3  // Leonardo R3 (same pin layout as Uno)
  
/*** MEGA 2560 board ***/
#elif __AVR_ATmega2560__
  /*** Board/layout selection ***/
  #define AR488_MEGA2560_D
  //#define AR488_MEGA2560_E1
  //#define AR488_MEGA2560_E2

/***** Panduino Mega 644 or Mega 1284 board *****/
#elif defined(__AVR_ATmega644P__) || defined(__AVR_ATmega1284P__)
  /* Board/layout selection */
  #define AR488_MEGA644P_MCGRAW

/***** Pololu 328PB board *****/
#elif defined(__AVR_ATmega328PB__)
  /* Board/layout selection */
  #define AR488_UNO

/***** ESP32 boards *****/
#elif defined(ESP32)
  /* Board/layout selection */
  #define NON_ARDUINO   // MUST BE DEFINED!
  #define ESP32_DEVKIT1_WROOM_32
  // David Douard / Johann Wilhelm board layouts
  //#define ESP32_TTGO_T8_161
  //#define ESP32_ESP32DEV
  //#define ESP32_LOLIN32_161   // ESP32_LOLIN32_161_V2 profile has the same pin assigments
  //#define ESP32_S2_161

/***** RPI PIco and Pico W *****/
#elif defined(ARDUINO_ARCH_RP2040)
  /* Board/layout selection */
  #define RAS_PICO_L1
//  #define RAS_PICO_L2

//#elif defined(ARDUINO_NANO_RP2040_CONNECT)

//#elif defined(ARDUINO_ARCH_MBED_NANO)

//#elif defined(ARDUINO_ARCH_MBED_RP2040)

#endif  // Board/layout selection



/***** SERIAL PORT CONFIGURATION *****/
/*
 * Note: On most boards the primary serial device is named Serial. On boards that have a secondary
 *       UART port this is named Serial1. The Mega2560 also supports Serial2, Serial3 and Serial4.
 *       When using layout AR488_MEGA2560_D, Serial2 pins are assigned as GPIO pins for the GPIB bus
 *       so Serial2 is not available.
 */
/***** Communication port *****/
#define DATAPORT_ENABLE
#ifdef DATAPORT_ENABLE
  // Serial port device
  #define AR_SERIAL_PORT Serial
  // #define AR_SERIAL_SWPORT
  // Set port operating speed
  #define AR_SERIAL_SPEED 115200
  // Enable Bluetooth (HC05) module?
  //#define AR_SERIAL_BT_ENABLE 12        // HC05 enable pin
  //#define AR_SERIAL_BT_NAME "AR488-BT"  // Bluetooth device name
  //#define AR_SERIAL_BT_CODE "488488"    // Bluetooth pairing code
#endif

/***** Debug port *****/
//#define DEBUG_ENABLE
#ifdef DEBUG_ENABLE
  // Serial port device
  #define DB_SERIAL_PORT Serial
  // #define DB_SERIAL_SWPORT
  // Set port operating speed
  #define DB_SERIAL_SPEED 115200
#endif

/***** Configure SoftwareSerial Port *****/
/*
 * Configure the SoftwareSerial TX/RX pins and baud rate here
 * Note: SoftwareSerial support conflicts with PCINT support
 * When using SoftwareSerial, disable USE_INTERRUPTS.
 */
#if defined(AR_SERIAL_SWPORT) || defined(DB_SERIAL_SWPORT)
  #define SW_SERIAL_RX_PIN 11
  #define SW_SERIAL_TX_PIN 12
#endif
/*
 * Note: SoftwareSerial reliable only up to a MAX of 57600 baud only
 */



/***** SUPPORT FOR PERIPHERAL CHIPS *****/
/*
 * This sections priovides configuration to enable/disable support
 * for SN7516x chips and the MCP23S17 GPIO expander.
 */


/***** Enable MCP23S17 GPIO expander chip *****/
/*
 * This version uses the SPI interface with speeds up to 10MHz max
 * Note: Use #define MCP23S17 as the layout definition
 */
#ifdef AR488_MCP23S17
  #define MCP_ADDRESS   0
  #define MCP_SELECTPIN 10
  #define MCP_INTERRUPT 2
#endif


/***** Enable SN7516x chips *****/
/*
 * Uncomment to enable the use of SN7516x GPIB tranceiver ICs.
 * This will require the use of an additional GPIO pin to control
 * the read and write modes of the ICs.
 */
//#define SN7516X
#ifdef SN7516X
//  #define SN7516X_TE 6
//  #define SN7516X_DC 13
//  #define SN7516X_SC 12
  // ONLYA board
  #define SN7516X_TE 13
  #define SN7516X_DC 5
#endif


/***** Level shifter (e.g. TXS0108E) enable pin *****/
//#define LEVEL_SHIFTER
#ifdef LEVEL_SHIFTER
  #define LVL_SHIFT_EN 22
#endif


/***** MISCELLANEOUS OPTIONS *****/
/*
 * Miscellaneous options
 */


/***** Device mode local/remote signal (LED) *****/
//#define REMOTE_SIGNAL_PIN 7
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

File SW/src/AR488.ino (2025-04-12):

#ifdef INTERFACE_PROLOGIX
//#pragma GCC diagnostic push
//#pragma GCC diagnostic ignored "-Wtype-limits"
//#pragma GCC diagnostic ignored "-Wunused-variable"

#ifdef __AVR__
  #include <avr/wdt.h>
#endif

//#pragma GCC diagnostic pop

#include "AR488_Config.h"
#include "AR488_GPIBbus.h"
#include "AR488_ComPorts.h"
#include "AR488_Eeprom.h"


/***** FWVER "AR488 GPIB controller, ver. 0.53.03, 08/04/2025" *****/

/*
  Arduino IEEE-488 implementation by John Chajecki

  Inspired by the original work of Emanuele Girlando, licensed under a Creative
  Commons Attribution-NonCommercial-NoDerivatives 4.0 International License.
  Any code in common with the original work is reproduced here with the explicit
  permission of Emanuele Girlando, who has kindly reviewed and tested the
  initial version of this project code.

  Thanks also to Luke Mester for comparison testing against the Prologix interface.
  AR488 is Licenced under the GNU Public licence.

  Thanks to 'maxwell3e10' on the EEVblog forum for suggesting additional auto mode
  settings and the macro feature.

  Thanks to 'artag' on the EEVblog forum for providing code for the 32u4.
*/

/*
   Implements most of the CONTROLLER functions;
   Substantially compatible with 'standard' Prologix "++" commands
   (see +savecfg command in the manual for differences)

   Principle of operation:
   - Commands received from USB are buffered and whole terminated lines processed
   - Interface commands prefixed with "++" are passed to the command handler
   - Instrument commands and data not prefixed with '++' are sent directly to the GPIB bus.
   - To receive from the instrument, issue a ++read command or put the controller in auto mode (++auto 1|2)
   - Characters received over the GPIB bus are unbuffered and sent directly to USB
   NOTES:
   - GPIB line in a HIGH state is un-asserted
   - GPIB line in a LOW state is asserted
   - The ATMega processor control pins have a high impedance when set as inputs
   - When set to INPUT_PULLUP, a 10k pull-up (to VCC) resistor is applied to the input
*/


/*
   NOT YET IMPLEMENTED
   ++myaddr   - set the controller address
*/


/*
   For information regarding the GPIB firmware by Emanualle Girlando see:
   http://egirland.blogspot.com/2014/03/arduino-uno-as-usb-to-gpib-controller.html
*/


/*
   Pin mapping between the Arduino pins and the GPIB connector.
   NOTE:
   GPIB pins 10 and 18-24 are connected to GND
   GPIB pin 12 should be connected to the cable shield (might be n/c)
   Pin mapping follows the layout originally used by Emanuelle Girlando, but adds
   the SRQ line (GPIB 10) on pin 2 and the REN line (GPIB 17) on pin 13. The program
   should therefore be compatible with the original interface design but for full
   functionality will need the remaining two pins to be connected.
   For further information about the AR488 see the AR488 Manual. 
*/


/*************************************/
/***** MACRO STRUCTRURES SECTION *****/
/***** vvvvvvvvvvvvvvvvvvvvvvvvv *****/
#ifdef USE_MACROS

/*** DO NOT MODIFY ***/
/*** vvvvvvvvvvvvv ***/

/***** STARTUP MACRO *****/
const char startup_macro[] PROGMEM = {MACRO_0};

/***** Consts holding USER MACROS 1 - 9 *****/
const char macro_1 [] PROGMEM = {MACRO_1};
const char macro_2 [] PROGMEM = {MACRO_2};
const char macro_3 [] PROGMEM = {MACRO_3};
const char macro_4 [] PROGMEM = {MACRO_4};
const char macro_5 [] PROGMEM = {MACRO_5};
const char macro_6 [] PROGMEM = {MACRO_6};
const char macro_7 [] PROGMEM = {MACRO_7};
const char macro_8 [] PROGMEM = {MACRO_8};
const char macro_9 [] PROGMEM = {MACRO_9};


/* Macro pointer array */
const char * const macros[] PROGMEM = {
  startup_macro,
  macro_1,
  macro_2,
  macro_3,
  macro_4,
  macro_5,
  macro_6,
  macro_7,
  macro_8,
  macro_9
};

/*** ^^^^^^^^^^^^^ ***/
/*** DO NOT MODIFY ***/

#endif
/***** ^^^^^^^^^^^^^^^^^^^^ *****/
/***** MACRO CONFIG SECTION *****/
/********************************/



/*******************************/
/***** SERIAL PARSE BUFFER *****/
/***** vvvvvvvvvvvvvvvvvvv *****/
/*
 * Note: Ardiono serial input buffer is 64 
 */
// Serial input parsing buffer
static const uint8_t PBSIZE = 128;
char pBuf[PBSIZE];
uint8_t pbPtr = 0;

/***** ^^^^^^^^^^^^^^^^^^^ *****/
/***** SERIAL PARSE BUFFER *****/
/*******************************/


/**************************/
/***** HELP MESASAGES *****/
/****** vvvvvvvvvvvvv *****/
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

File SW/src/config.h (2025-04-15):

#pragma once

#define DEVICE_NAME "Ethernet2GPIB Gateway v1.1 (AR488 v0.53.03)\n"

#define LED_R 13
#define LED_G 39
#define LED_B 38

// This is needed, and debugPort should point to Serial if you want to use the serial menu
#define DEBUG_ENABLE
// define USE_SERIALMENU if you want a basic menu on the serial console for amongst others IP address setting.
#define USE_SERIALMENU

// define USE_WEBSERVER if you want to use a very basic web page server that serves a static explanation page.
// It is not interactive, just a cherry on the cake with help text.
// This is mainly meant to be used with the VXI server, but it should work with the Prologix server as long as ROM permits (it will be very close if not over the limit).
#ifndef DISABLE_WEB_SERVER
#define USE_WEBSERVER
#endif

#ifndef INTERFACE_PROLOGIX
#define INTERFACE_VXI11
#endif
// and if you define both, well, you'll have to deal with the compiler telling you there is not enough ROM.


// for the Prologix server: 
#define AR_ETHERNET_PORT
#define PROLOGIX_PORT 1234

// For the VXI server:
#define VXI11_PORT 9010
// Maximum number of clients for the VXI server:
// Max MAX_SOCK_NUM sockets on the device. You will likely not even be able to reach that number, because of other sockets open or busy closing
#define MAX_VXI_CLIENTS MAX_SOCK_NUM
// set LOG_VXI_DETAILS to 0 or 1, depending on whether you want to see VXI details on the debugPort
// setting to 1 messes up the serial menu a bit
#define LOG_VXI_DETAILS 0

// set LOG_WEB_DETAILS to 0 or 1, depending on whether you want to see Web server details on the debugPort
// setting to 1 messes up the serial menu a bit
#define LOG_WEB_DETAILS 0

// if you activate this, the serial menu will be messier. 
// Only activate this when you want to see memory usage 
// and other details in auto refresh on the console.
// #define LOG_STATS_ON_CONSOLE

// EEPROM use: 
// Writing the 24AA256 is somehow broken, so we can also write via the GPIB configuration
#define AR488_GPIBconf_EXTEND

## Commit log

2024-12-26 Added uart and i2c to jtag connector, docs added
    [Ethernet_interface.kicad_sch, GPIB.kicad_sch, MCU.kicad_sch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]
2024-12-26 Updated doc
    [PoE_Ethernet_GPIB_Adapter.3mf]
2024-12-27 mfg files
    [PoE_Ethernet_GPIB_Adapter-B_Cu.gbr, PoE_Ethernet_GPIB_Adapter-B_Mask.gbr, PoE_Ethernet_GPIB_Adapter-B_Paste.gbr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]
2024-12-27 added schematic
2024-12-27 cleaned up and added missing files
    [Ethernet_interface.kicad_sch, GPIB.kicad_sch, MCU.kicad_sch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]
2025-04-10 dummy single device VXI-11 server is up
2025-04-10 some timing issue, but I have an operational VXI-11 to GPIB server
    [AR488_GPIBbus.cpp, main_vxi11.ino, user_interface.cpp]
2025-04-10 VXI-11 is OK on 1 device
2025-04-11 code clean up, better led handling
2025-04-11 add device name
2025-04-11 nicer led colors
2025-04-14 correct custom pin layout
    [AR488_Layouts.cpp]
2025-04-15 socket limitations
2025-04-15 web server OK, socket use investigated
2025-04-16 adapt ethernet link problem detection
    [user_interface.cpp]
2025-04-16 nicer print statements around network problems
    [user_interface.cpp]
